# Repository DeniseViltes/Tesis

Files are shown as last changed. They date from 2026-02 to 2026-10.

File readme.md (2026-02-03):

# Plataforma experimental de ecualización activa de celdas de litio

Trabajo Profesional de Ingeniería Electrónica  
Facultad de Ingeniería – Universidad de Buenos Aires (FIUBA)  
Año 2026

**Integrantes**
- Sebastián Ezequiel García
- Denise Oriana Viltes

**Tutora:** Dra. Cecilia G. Galarza  
**Cotutor:** Ing. Juan Zuloaga

---

## Descripción

Este proyecto presenta el diseño, simulación e implementación de una plataforma
experimental para evaluar estrategias de ecualización activa en baterías de litio.

La plataforma permite:
- reconfigurar dinámicamente el conexionado de celdas mediante una matriz de switches
<!-- Esto es un comentario --> - estimar SoC (State of Charge)
<!-- Esto es un comentario -->- ensayar algoritmos de balanceo activo
- validar resultados mediante simulación y prototipo físico

El objetivo es contar con una plataforma para comparar
distintas arquitecturas de balanceo y analizar su eficiencia energética.

---

## Estructura del repositorio

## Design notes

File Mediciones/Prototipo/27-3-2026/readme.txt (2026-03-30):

Pruebas de sw

Cuando probamos 1 celda y el banco en sw, se llega ver un pico de corriente en la fuente de tension, no llegamos a ver a que corresponde en las tensiones medidas en el osciloscopio.

Cuando intercalamos una celda por otra en un mismo banco no hay pico, la salida se ve constante.

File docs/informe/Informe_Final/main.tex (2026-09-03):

\documentclass[12pt]{article}
\input{paquetes}

\makeatletter
\renewcommand\paragraph{\@startsection{paragraph}{4}{\z@}%
  {2ex plus .2ex}%  Espacio antes
  {0.5em}%             Espacio después
  {\normalfont\normalsize\bfseries}% Estilo
}
\makeatother

% Configuración del encabezado para la carátula y el índice

\newcommand{\quotes}[1]{``#1''}

\sisetup{
  per-mode=fraction,
}

\renewcommand\indexname{Índice}

\setmarginsrb{3 cm}{2.5 cm}{3 cm}{2.5 cm}{1 cm}{1.5 cm}{1 cm}{1.5 cm}

\captionsetup{
    width=0.6\textwidth, % Ancho del caption
    margin=20pt, % Margen del caption
}

\makeindex[columns=3, title=Alphabetical Index, intoc]

\begin{document}

%--------------------------- DATOS GENERALES -----------------------------%

\title{Trabajo Profesional de Ingeniería Electrónica}	% Titulo del trabajo.
\author{UBA - Facultad de Ingeniería}	% Nombre y apellido
\newcommand{\tpnumber}{I}       % Número de trabajo práctico
\date{\today}					% Fecha (automática, no tocar)

\makeatletter
\let\thetitle\@title
\let\theauthor\@author
\let\thedate\@date
\makeatother

\pagestyle{fancy}

\fancyhead[R]{Grupo 2}
\fancyhead[L]{TP1}
\rhead{\theauthor}
\lhead{\thetitle}
\cfoot{\thepage}

%-------------------------------------------------------------------------%
%-------------------------------------------------------------------------%
%------------------------------- CARÁTULA --------------------------------%
%-------------------------------------------------------------------------%
%-------------------------------------------------------------------------%

\begin{titlepage}
\fancyhf{} % limpia encabezado y pie

% --- Configuración del pie de página ---
\fancyfoot[L]{\small Trabajo Profesional de Ingeniería Electrónica}
\fancyfoot[R]{\small Año 2026}

% --- Quita la línea del encabezado y activa la del pie ---
\renewcommand{\headrulewidth}{0pt}
\renewcommand{\footrulewidth}{0.4pt}
\thispagestyle{fancy}

\vfill 

\begin{center}
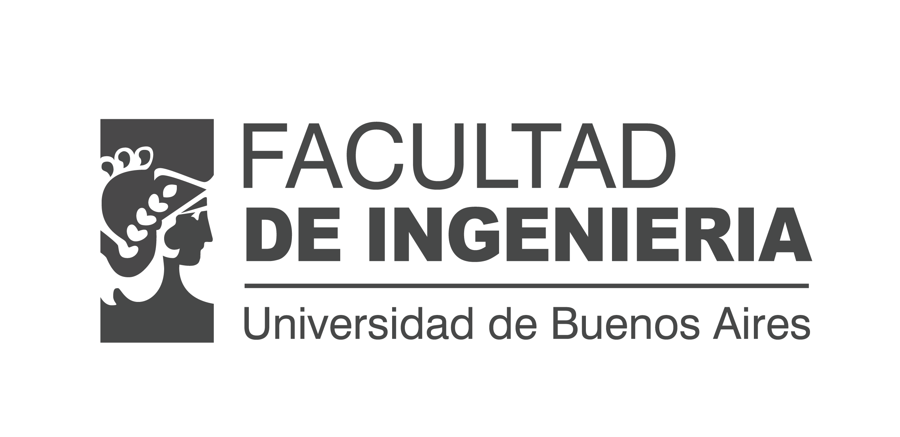
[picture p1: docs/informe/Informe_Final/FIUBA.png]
    \\[1cm]
    
    {\huge \textbf{Diseño de una plataforma experimental de ecualización activa de celdas de litio}}\\[1cm]

    {\large\textbf{Integrantes}}\\[0.2cm]
    {\Large Sebastián Ezequiel García}\\
    Padrón: 103780\\
    \textit{sebgarcia@fi.uba.ar}\\[0.3cm]
    
    {\Large Denise Oriana Viltes}\\
    Padrón: 106943\\
    \textit{dviltes@fi.uba.ar}\\[1cm]

    {\large\textbf{Tutora}}\\[0.2cm]
    {\Large Dra. Cecilia G. Galarza}\\
    \textit{cgalar@fi.uba.ar}\\[0.3cm]
    {\large\textbf{Cotutor}}\\[0.2cm]
   {\Large Ing. Juan Zuloaga}\\
    \textit{jzuloaga@fi.uba.ar}\\[1cm]
\end{center}
\vfill 
\end{titlepage}

\newpage
\tableofcontents
\clearpage

\onehalfspacing
\justifying

%-------------------------------------------------------------------------%

\input{Capitulos/Marco teorico}

\input{Capitulos/Diseño del circuito}
\input{Capitulos/Prototipo}
\input{Capitulos/Mediciones sobre el prototipo}
\input{Capitulos/Circuito final}
\input{Capitulos/Posibles mejoras}

\newpage
\bibliographystyle{IEEEtran}
\bibliography{biblio}

[AGREGARLE COMO REFERENCIAS LAS HOJAS DE DATOS]

\end{document}

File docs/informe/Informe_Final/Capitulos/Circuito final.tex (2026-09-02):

\section{Circuito final}

Con la confirmación de funcionamiento del prototipo, se prosiguió al diseño del sistema final. La principal premisa del trabajo es que sea modular, por lo que se optó por numerosos circuitos pequeños en lugar de uno solo grande como fue el prototipo. En un principio se pensó en mantener las celdas con los portapilas en una placa por separado del resto del circuito dado el tamaño que le agrega a cada módulo. Sin embargo, finalmente se descartó esa idea, resultando en tres circuitos diferentes:

\begin{enumerate}
    \item Circuito de celdas: cada una es un módulo que alberga el portapilas, con su \textit{switch}, LED e inversor.
    \item Circuito de bancos: con el \textit{switch by-pass} de las celdas y desde donde se envían las señales de control a todas las celdas del mismo banco.
    \item Circuito central: donde se inserta el controlador y desde donde parten las señales de control a todo el sistema, y a donde llegan las señales de censado de las celdas.
\end{enumerate}

\begin{figure}[H]
    \centering
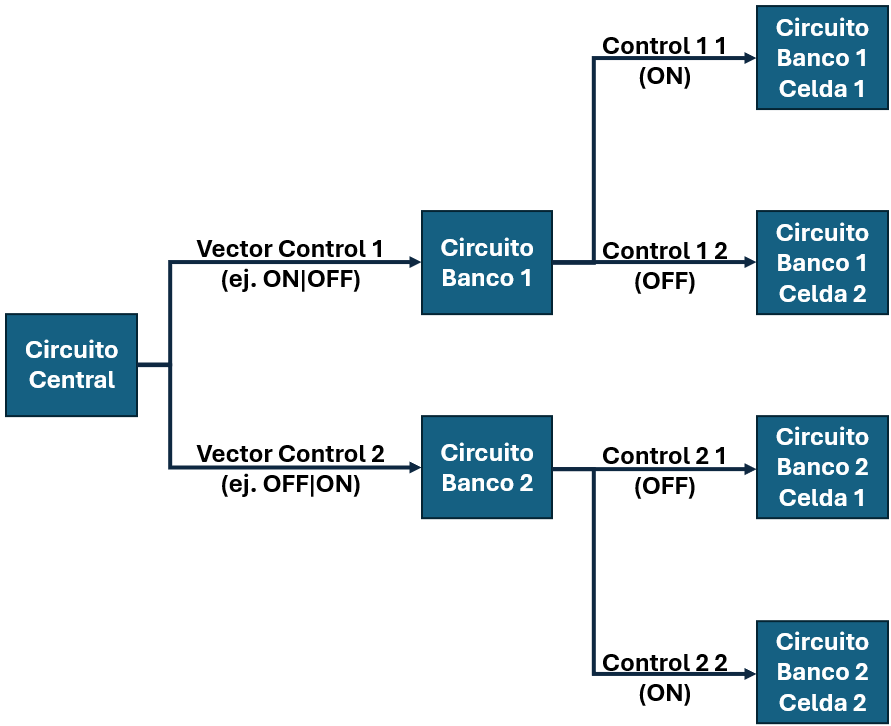
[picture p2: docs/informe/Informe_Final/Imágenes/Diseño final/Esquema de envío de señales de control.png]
    
    \caption{Diagrama de transporte de señales de control entre los módulos.}
    \label{fig:esquema_seniales_control}
\end{figure}

De esta forma, se armaron doce circuitos de celdas, cuatro circuitos de banco y un circuito central.

Al margen de los cambios de diseño del \textit{hardware}, también sufrió cambios el controlador. Debido a la mayor cantidad de celdas en comparación con el prototipo, son necesarios muchos más pines del controlador, más de los disponibles. Esto implica un cambio de lógica al momento de enviar las señales para maximizar el uso de cada pin de salida de la placa programable.

Al no alcanzan los pines del controlador para todas las señales que debe enviar si fuera una por cada celda, se optó por enviar la información en serie para todas las celdas de un banco. Para este rol fue que se utilizó un \textit{shift-register} con \textit{latch} (SR). Más información sobre este componente se provee en la sección del diseño de circuito de banco.

Por otro lado, otro objetivo que se planteó fue el de armar todos los circuitos, siempre que sea posible, con componentes SMD. De esta forma, buscamos:
\begin{itemize}
    \item Minimizar el área de placa de cobre usada,
    \item Facilitar el planchado y perforado de las placas,
    \item Identificar de forma clara qué corresponde a una entrada y/o salida, y qué al circuito propio de cada módulo,
    \item Aprender a soldar componentes SMD.
\end{itemize}

Otro punto a destacar fue que se decidió acerca de qué topología conformarían los módulos conectados. Ya haciendo pruebas y mediciones con el prototipo mismo, rápidamente se mostró la incomodidad al tener que usar cables \textit{dupont} para todo el conexionado. Cables demasiado largos, fácil de enredarse y que no enganchan con firmeza, complican mucho la instalación del banco de prueba. Para esto es que se decidió eliminar el uso de cables individuales y utilizar más que nada pines que encastren entre los módulo para conectarlos.

A la primera configuración planteada se la denominó "tren". Consistía en usar pines $90^\circ$ macho a un lado de la placa y hembra en el extremo opuesto. De esta forma, podrían conectarse de costado cada módulo. Sin embargo, esta configuración tenía tres grandes problemas. Por un lado, los pines hembra y macho $90^\circ$ no están a la misma altura, por lo que se tendría que soldar de forma muy cuidadosa para garantizar un encastre correcto. A su vez, el hecho que haya señales compartidas entre todas las celdas de un mismo banco implicaría que la señal entra por un costado de la placa y tendría que trasladarse a través de todo el circuito hasta la salida en el otro extremo para que el siguiente módulo reciba la señal correcta. Esto complicaría enormemente el ruteo de la placa. Por último, si se tuviera un banco con varias placas de celda, sería necesario mucho espacio en una mesa y sería complicado moverlas sin necesidad de desconectarlas. Por todo esto fue que se decidió optar por la segunda configuración.

La otra opción era la configuración "torre". Este caso era mucho más simple: los módulos de celdas se montarían uno encima de otro mediante pines y, abajo de todo como si fueran los cimientos, estaría el módulo del banco. Esto facilitaba en gran medida el ruteo (no hace falta trasladar la señal de entrada de un lado a otro de la placa), el transporte y el espacio necesario. La única condición estrictamente necesaria es que el pin macho que recibe las entradas desde el "piso de abajo" tenga un equivalente hembra apuntando hacia arriba para transmitirlas hacia el siguiente módulo. Para esto se usaron los pines hembra-macho o también llamados pines hembra largos de la figura \ref{fig:pin_hembra_largo}. Otro inconveniente menor es la poca rigidez estructural de la torre, pero se asumió que los pines tienen un agarre suficientemente fuerte como para mantener a las placas en pie. Con todos los problemas solucionados, esta configuración torre fue la elegida.

\begin{figure}[H]
    \centering
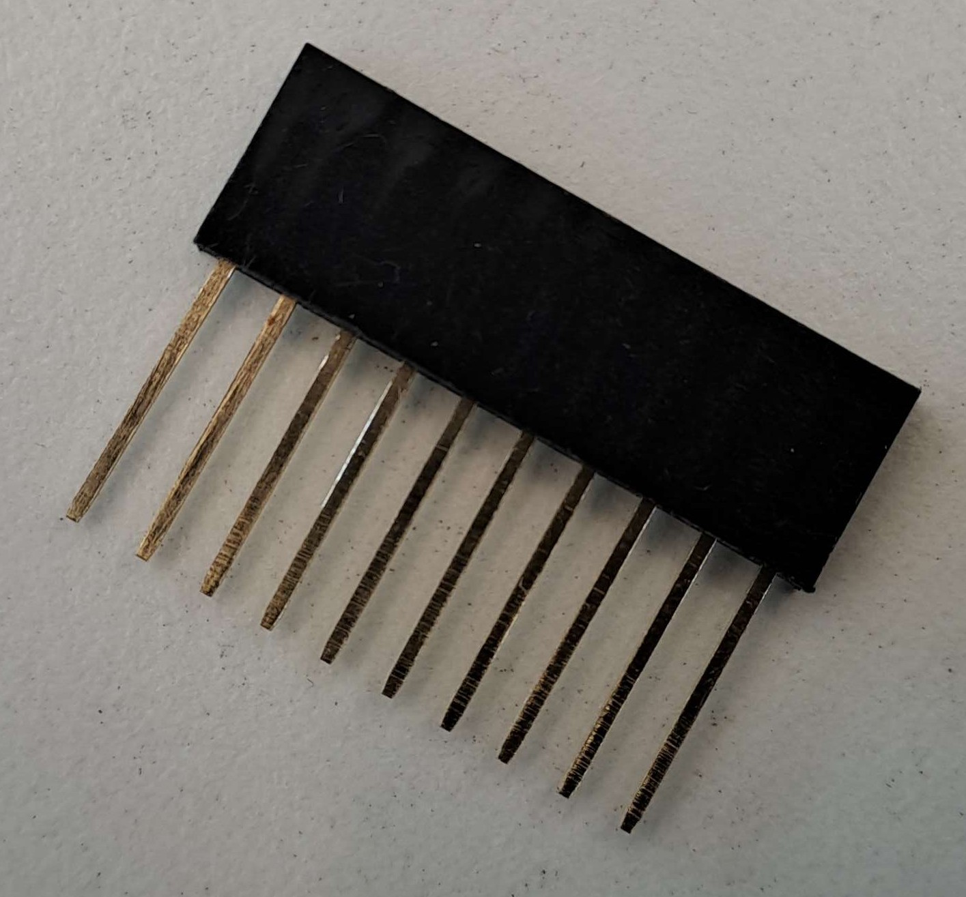
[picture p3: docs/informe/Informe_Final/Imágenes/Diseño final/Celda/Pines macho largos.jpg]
    
    \caption{Tira de diez pines hembra-macho utilizados.}
    \label{fig:pin_hembra_largo}
\end{figure}

\subsection{Diseño del circuito de las celdas}

%OPCIONES PARA LAS ENTRADAS A LAS CELDAS:
%- MULTIPLEXOR
%- SHIFT REGISTER CON LATCH
%- MICRO EN CADA CELDA

El principal problema a tratar fue el de los pocos pines del controlador. Antes de utilizar el \textit{shift-register}, se pensó en colocar un microcontrolador en cada módulo de celda. De esta forma, mediante comunicación I2C se podría enviar la señal de encendido o apagado a cada módulo utilizando solo dos vías. Esto permitiría conectar la cantidad de celdas que se deseen por banco. Sin embargo, se descartó esta idea debido al aumento de precio que implica y su complejidad de implementación. Finalmente se terminó optando por el envío de información en serie en una etapa anterior, y que cada módulo de celda simplemente reciba como entrada su señal de control.

\subsubsection{Versión 2.0}

El circuito, en grandes rasgos, se mantuvo como en el prototipo, al menos en cuanto a su funcionamiento. Sin embargo, sí hubieron diferencias constructivas en pos de la modularidad del sistema. El circuito propiamente dicho fue igual salvo por la incorporación de un inversor para la señal de control negada, como entrada en la base del transistor $Q_3$.

En el prototipo, para las señales negadas se utilizó el integrado \textbf{CD40106} que contenía seis inversores. En este caso, sería un desperdicio de recursos y espacio montar uno de esos por módulo, por lo que se identificaron dos opciones: tener tanto señal de control como señal negada como entradas, o incorporar un inversor más simple por módulo. Se optó por la segunda opción, y, ante la imposibilidad de conseguir inversores individuales, se implementó un inversor CMOS discreto. Para esto se utilizaron los MOSFETS \textbf{AO3400} (canal N) y \textbf{AO3401} (canal P), como se muestra en la figura \ref{fig:inversor_cmos}.

\begin{figure}[H]
    \centering
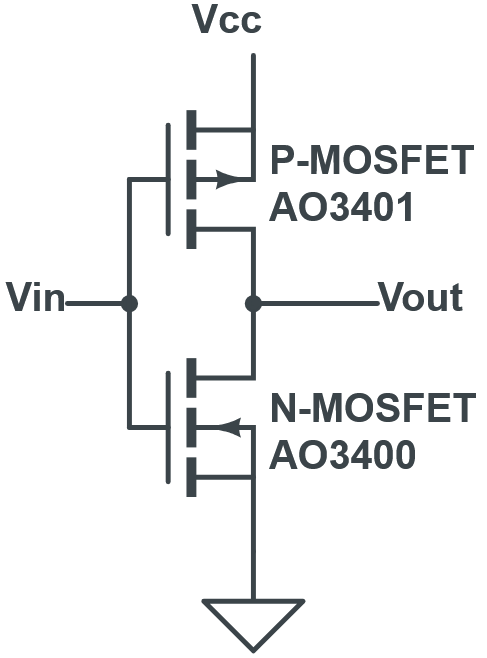
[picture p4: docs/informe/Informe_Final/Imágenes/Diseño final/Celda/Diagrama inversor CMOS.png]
    
    \caption{Diagrama del inversor CMOS discreto implementado.}
    \label{fig:inversor_cmos}
\end{figure}

Al igual que en el prototipo, se implementó un pequeño circuito con un LED. Mediante un TBJ NPN, se abre o cierra la malla del dispositivo según sea la señal de control del \textit{switch} de la celda. De esta forma, se puede ver claramente cuándo es que cada celda está encendida.

Cada módulo tiene una cantidad de entradas definidas para poder funcionar correctamente. En un principio están $Vcc$ y $GND$. Por un lado, necesarios para la etapa de control del módulo, la malla del LED y el inversor CMOS, y por otro para que las tierras de todos los circuitos estén acopladas. A su vez están los buses positivo y negativo de cada banco ($bus\_pos$ y $bus\_neg$). Éstos son tanto entrada como salida: si la celda está prendida, ésta impone su diferencia de tensión entre estos buses, pero a la vez, también deben coincidir con los buses de todas las celdas del banco dado que están en paralelo. Finalmente se tiene el control global. Éste es una señal de control separada de las individuales para cada celda. Con el objetivo de simplificar la comunicación, se decidió enviar, además de las señales de control individuales para cada módulo, una señal compartida para todas ellas. Dado que el control se hace por banco y no por celda, éste sería el control utilizado en el funcionamiento normal del sistema. Para poder seleccionar entre esta señal global y la individual, se usa un \textit{jumper}.

Con respecto a la entrada de control individual, se hicieron varias consideraciones. En un principio, como cada módulo envía al siguiente exactamente la misma información que recibe, cada módulo necesariamente tiene que recibir las señales de control de todas las celdas individuales del banco. Para esto se utilizó una tira de siete pines hembra-macho, uno por módulo de celda en el banco. La tarea de asignar qué señal se corresponde a qué módulo se dejó para hacerse a mano. Esto se hizo mediante una tira de pines macho dobles y un \textit{jumper}. El sistema montado se muestra en la figura \ref{fig:pines_control_celda}.

\begin{figure}[H]
    \centering
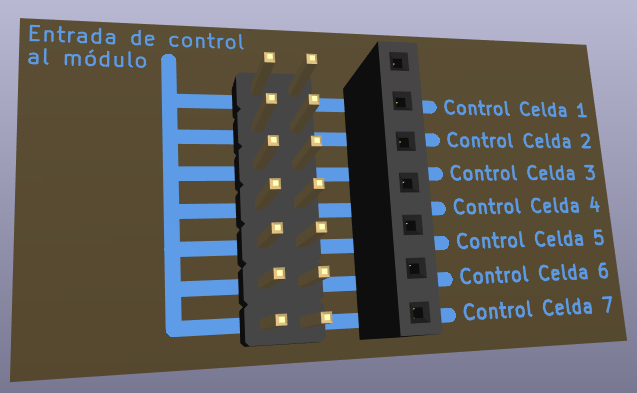
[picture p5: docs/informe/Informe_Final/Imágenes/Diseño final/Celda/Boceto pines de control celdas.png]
    
    \caption{Configuración realizada para la entrada de las señales de control en cada módulo de celda.}
    \label{fig:pines_control_celda}
\end{figure}

En celeste está diagramado el conexionado entre las dos tiras de pines. Importante destacar que el lado izquierdo de la tira de pines macho doble no está conectado con el lado derecho. Pero los pines del lado izquierdo sí están conectados todos entre sí, los cuales son la señal de entrada al módulo en cuestión. De esta forma, mediante un \textit{jumper} puede seleccionarse cuál de las siete entradas termina siendo la que realmente controla la celda.

Por otro lado, también se tienen las salidas de censado. Se decidió tomar el valor de tensión de cada módulo de celda el valor de $cell\_neg$, es decir, el nodo entre el terminal negativo del portapilas y el \textit{drain} del N-MOSFET. Se utilizó un sistema igual que para las entradas de control: cada módulo tiene las tensiones de todos los módulos del banco. Mediante un \textit{jumper} es que se le asigna a cada módulo su salida correspondiente de entre los siete posibles. Para colocarlo se usa otra tira de siete pines macho dobles.

Con todo esto ya quedan definidas las entradas y salidas de cada módulo de celda. Se tienen veinte pines dobles hembra-macho de entrada/salida:
\begin{itemize}
    \item Pin Vcc.
    \item Dos pines GND. Son dos para facilitar el ruteo (si no habría que usar más vías).
    \item $bus\_pos$.
    \item $bus\_neg$.
    \item Pin de control para todos los módulos del banco $Vcontrol\_global$.
    \item Siete pines de control individual (uno por módulo de celda en el banco).
    \item Siete pines de censado de $cell\_neg$ (uno por módulo).
\end{itemize}

Luego está el tema de la estabilidad mecánica de la torre. Ya se mencionó que el agarre de los pines hembra-macho es fuerte. Sin embargo, para mayor seguridad, se tomaron dos medidas. En un principio, en cada ocasión que se utilizaron dichos pines, se tomaron siempre tiras dobles. De esta forma, la cantidad de pines que se conectan entre un módulo y el siguiente se duplica. El único problema de esto es que no se venden en el país pines hembra-macho dobles, por lo que se utilizaron en cada instancia dos tiras simples (salvo en un caso por temas de espacio en la placa). Por otro lado, la otra medida para hacer más robusta la torre fue colocar los pines en diferentes lados de la placa. Con estas dos medidas, la torre debería mantenerse firme incluso si se conectara la máxima cantidad de celdas posibles por banco.

Existe otro inconveniente del que hasta ahora no se habló: la altura de cada módulo. Para ser más específico, la altura del portapilas. El problema reside en que los pines, a pesar de ser mucho más largos que unos hembra comunes, aún así no son más largos que el alto del portapilas. Esto significaría que una celda no podría conectarse con otra por encima. Para solucionar esto se decidió usar otra iteración de los mismos pines. Es decir, entre módulo y módulo hay otras tiras de pines como se ve en la figura \ref{fig:celda_stackeada}. De esta forma, hay un muy pequeño espacio entre cada módulo, por donde entran sin problema los componentes SMD del circuito.

\begin{figure}[H]
    \centering
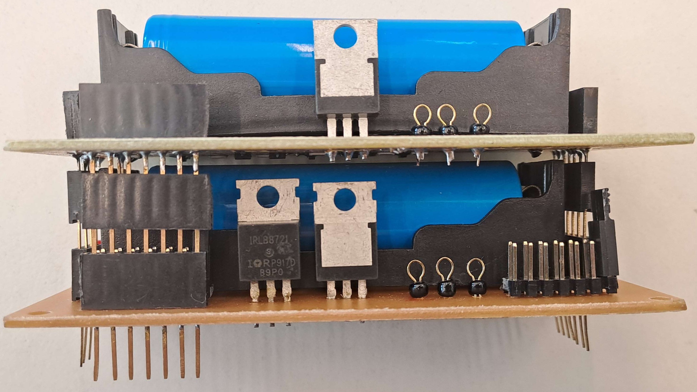
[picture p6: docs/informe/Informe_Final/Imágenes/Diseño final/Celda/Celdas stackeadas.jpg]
    
    \caption{Dos módulos de celdas (versión 2.1), una por encima de otra, con los pines de conexión.}
    \label{fig:celda_stackeada}
\end{figure}

Como datos de color, se menciona que el MOSFET de canal N que enciende y apaga cada celda se colocó con la cara metálica del encapsulado apuntando hacia afuera de la placa. Esto permite que tenga lugar disponible en caso que se desee incorporar un disipador. No es necesario para esta topología pero, en caso de querer aumentar la corriente a la salida, puede hacer falta. Por otro lado, también se utilizó, como en el prototipo, un fusible de \SI{3}{\ampere} en cada celda en la malla de salida. Además, se creó una pequeña zona libre de cobre en torno a los tornillos sujetadores del portapilas. Esto se hizo para que las tuercas que ajustan no estén en contacto con el plano de tierra del circuito.

En cuanto al ancho de las pistas, se tomó para las pistas de la malla de potencia \SI{1.5}{\milli\meter} y para las pistas de la etapa de control, \SI{0.4}{\milli\meter}. Ambas fueron elegidas de forma tal que puedan sin problemas tolerar la corriente máxima que puede atravesar cada pista. Los valores fueron seleccionados con la tabla dada por Peterson (2025) \cite{peterson2025pcb}.

Finalmente, para facilitar el \textit{debuggeo} se instalaron tres \textit{test-points}: uno en la base del TBJ PNP, otro en el nodo de \textit{gate} del \textit{switch} N-MOSFET y el último a la salida del inversor.

Con todo esto, el circuito resultó como se ve en las figuras \ref{fig:pcb_celda_v20} y \ref{fig:modelo3d_celda_v20}.

\begin{figure}[H]
    \centering
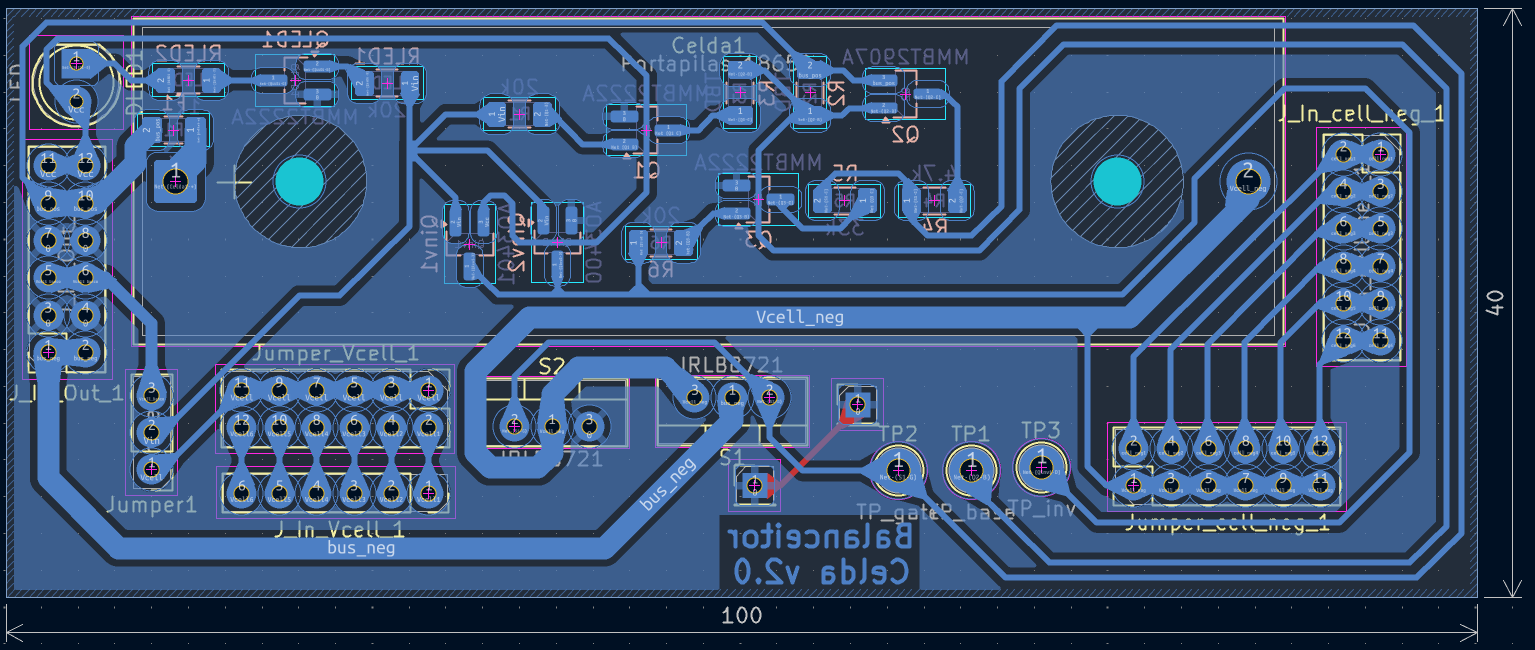
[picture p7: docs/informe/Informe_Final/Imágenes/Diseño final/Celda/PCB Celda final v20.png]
    
    \caption{PCB diseñado en \textit{KiCad} del módulo de una celda, versión 2.0.}
    \label{fig:pcb_celda_v20}
\end{figure}

\begin{figure}[H]
    \centering

    \begin{subfigure}{\linewidth}
        \centering
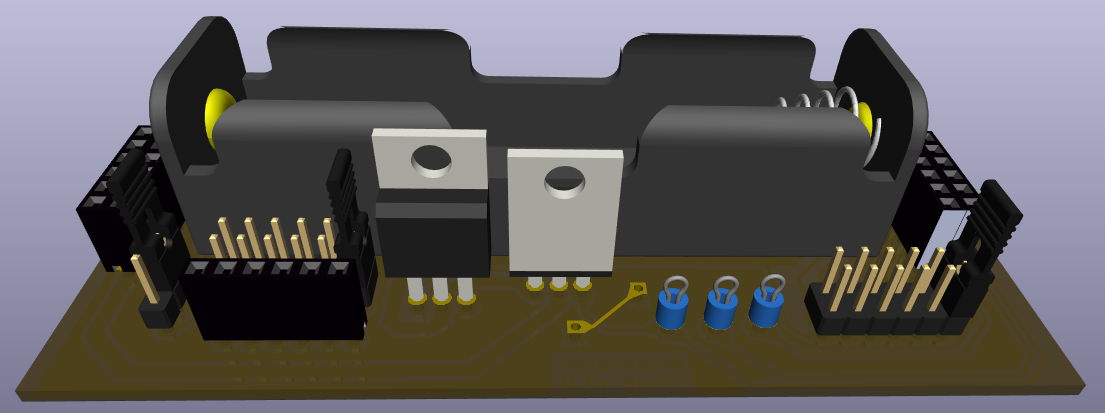
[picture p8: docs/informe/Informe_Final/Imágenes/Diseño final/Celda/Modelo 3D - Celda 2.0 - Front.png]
        
        \caption{Modelo 3D del frente.}
        \label{fig:modelo3d_celda_v20_f}
    \end{subfigure}

    \vspace{0.5cm}

    \begin{subfigure}{\linewidth}
        \centering
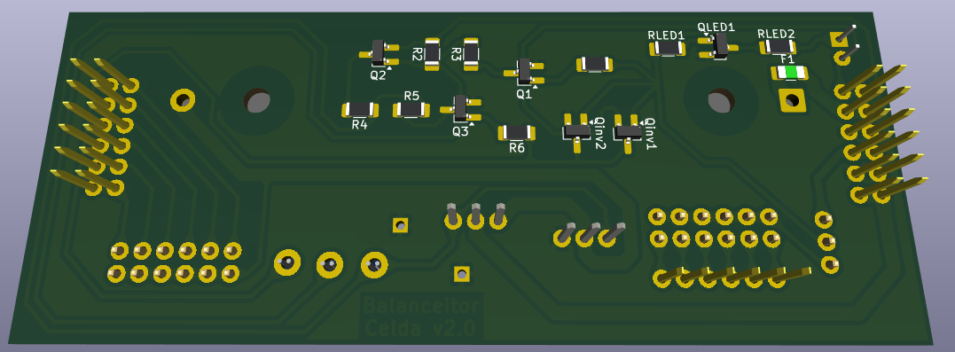
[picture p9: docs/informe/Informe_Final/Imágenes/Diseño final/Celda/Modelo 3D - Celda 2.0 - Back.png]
        
        \caption{Modelo 3D del reverso.}
        \label{fig:modelo3d_celda_v20_r}
    \end{subfigure}

    \caption{Modelos 3D del módulo de una celda, versión 2.0.}
    \label{fig:modelo3d_celda_v20}
\end{figure}

\subsubsection{Versión 2.1}

La versión 2.0 del módulo de celdas tuvo una vida muy corta. Por un lado, debido a un error de cálculos, se diseñó el módulo para que sea parte de un banco de hasta seis celdas. Sin embargo, el máximo real de módulos conectados que permite el SR es siete. A su vez, hubo un problema mucho más grave: la celda nunca se apagaba. Incluso cuando su señal de control era de apagado, el PNP se mantenía encendido. Esto provocaba un camino de baja impedancia entre el bus positivo y la tierra, mediante los transistores $Q_2$ y $Q_3$ de la figura \ref{fig:circuito_original}. Este problema ya había sido detectado en el prototipo pero se lo había descartado como una falla en la impresión de la placa. Finalmente se encontró la verdadera respuesta, y era efectivamente un problema de diseño. Los resistores $R_2$ y $R_3$, al ser tan grandes ($\SI{10}{\mega\ohm}$ y $\SI{1}{\mega\ohm}$ respectivamente), provocaban una significativa caída de tensión ante cualquier diminuta corriente parásita o de fuga que los atraviesen. Dicha caída era suficientemente alta como para encender el PNP, por ende, encendiendo el N-MOSFET de \textit{switcheo}. Reemplazándolos por resistores de $\SI{100}{\kilo\ohm}$ y $\SI{10}{\kilo\ohm}$ se solucionó el problema. Es curioso notar que este efecto no se veía en simulaciones, dado que era causado por corriente parásitas que el motor del \textit{LTspice} no simula.

Dado que el diseño estaba claramente incorrecto, se creó una nueva versión del módulo de celdas, corrigiendo algunos de los errores encontrados y aplicando otras tantas mejoras.

En un principio, se decidió eliminar el control global de todo el banco del diseño. Se lo consideró innecesario y que agregaba pines y \textit{jumpers} excesivos. Ahora, si se desea apagar o prender todas las celdas de un mismo banco, simplemente se le envía a todas señales iguales en lugar de decidir de qué forma tomar la entrada de control. Esto permitió eliminar el pin de $Vcontrol\_global$ y la tira de tres pines macho con el \textit{jumper} de selección de entrada de control. A su vez, al eliminar este pin de las entradas se simplificó el ruteo, lo cual también se eliminó la necesidad de que hayan dos pines de GND separados.

Por otro lado, hubieron mejoras en cuanto a la estabilidad mecánica de cada torre. En lugar de usar tiras de pines hembra-macho dobles, se instalaron orificios para una varilla roscada de \SI{3}{\milli\meter} en cada esquina de la placa. Así se reemplazaron las tiras dobles por simples, ahorrando en tiras de pines a comprar y espacio en la placa. De esta forma, se tiene ahora certeza absoluta de la robustez de la instalación por las varillas.

Por último, en lugar de una vía se utilizó un resistor SMD de \SI{0}{\ohm}. Éste cumple la misma función pero ocupando menos espacio y sin la necesidad de hacer orificios en la placa.

Con todos los cambios mencionados, también se pudo achicar ligeramente el tamaño de cada módulo (unos pocos milímetros por lado). De este modo, el PCB resultó como se muestra en las figuras \ref{fig:pcb_celda_v21} y \ref{fig:modelo3d_celda_v21}.

\begin{figure}[H]
    \centering
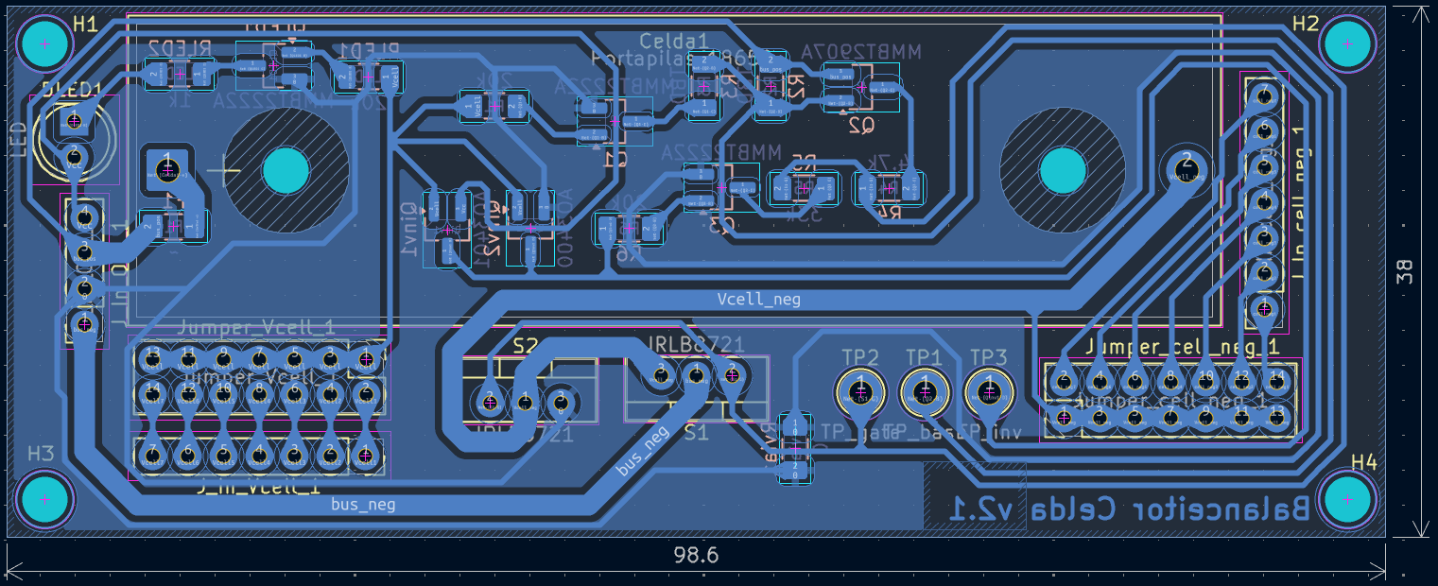
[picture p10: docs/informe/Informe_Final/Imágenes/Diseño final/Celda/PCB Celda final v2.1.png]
    
    \caption{PCB diseñado en \textit{KiCad} del módulo de una celda, versión 2.1.}
    \label{fig:pcb_celda_v21}
\end{figure}

\begin{figure}[H]
    \centering

    \begin{subfigure}{\linewidth}
        \centering
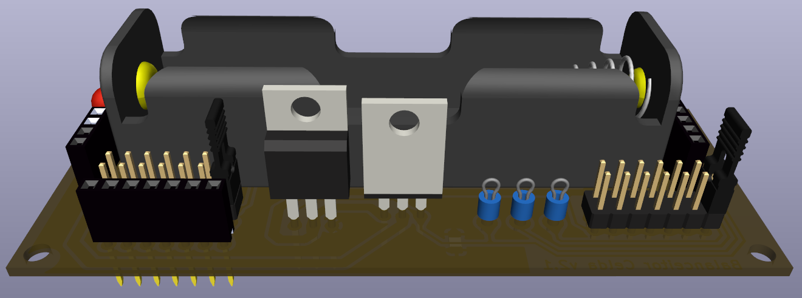
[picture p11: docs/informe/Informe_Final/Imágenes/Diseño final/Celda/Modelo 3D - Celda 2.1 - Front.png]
        
        \caption{Modelo 3D del frente.}
        \label{fig:modelo3d_celda_v21_f}
    \end{subfigure}

    \vspace{0.5cm}

    \begin{subfigure}{\linewidth}
        \centering
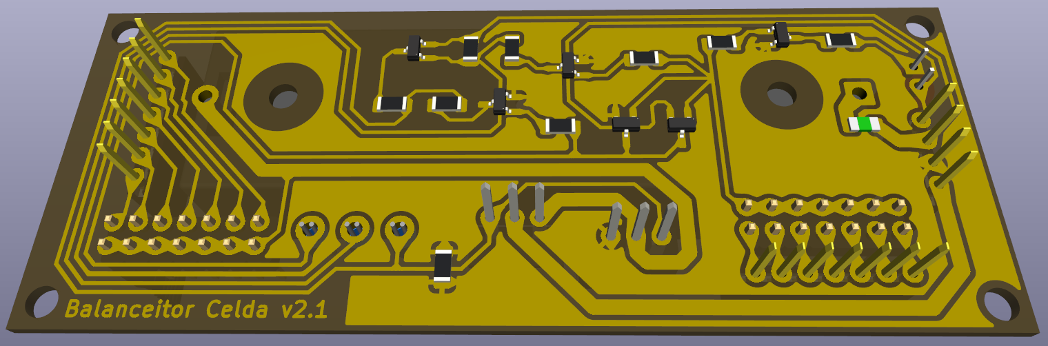
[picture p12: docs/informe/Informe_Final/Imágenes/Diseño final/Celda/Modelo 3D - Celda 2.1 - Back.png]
        
        \caption{Modelo 3D del reverso.}
        \label{fig:modelo3d_celda_v21_r}
    \end{subfigure}

    \caption{Modelos 3D del módulo de una celda, versión 2.1.}
    \label{fig:modelo3d_celda_v21}
\end{figure}

A diferencia de la versión anterior, esta sí funcionó como era esperado y se cumplieron exitosamente las pruebas básicas de funcionamiento del módulo. Sin embargo, unos resultados fueron algo alarmantes.

\subsubsection{Versión 2.2}

Mientras se realizaban las pruebas de funcionamiento en los módulos de celda v2.1, se descubrió que el valor de tensión de $cell\_neg_1$, el nodo del terminal negativo de las celdas del banco 1, era negativo. Este valor se volvía más negativo a medida que se agregaban más bancos en serie, llegando a unos \SI{-500}{\milli\volt} cuando se tenían cuatro bancos instalados. Esto es alarmante porque ese mismo nodo es el que se censa mediante del multiplexor analógico, el cual, para no dañarse, puede recibir tensiones menores a medio volt negativo. Dado que se está alcanzando dicho umbral, era necesario reducir (en módulo) dicha tensión. Cabe destacar que este fenómeno se da solamente en los nodos $cell\_neg$ de las celdas del banco 1.

\begin{wrapfigure}{l}{0.55\textwidth}
    \centering
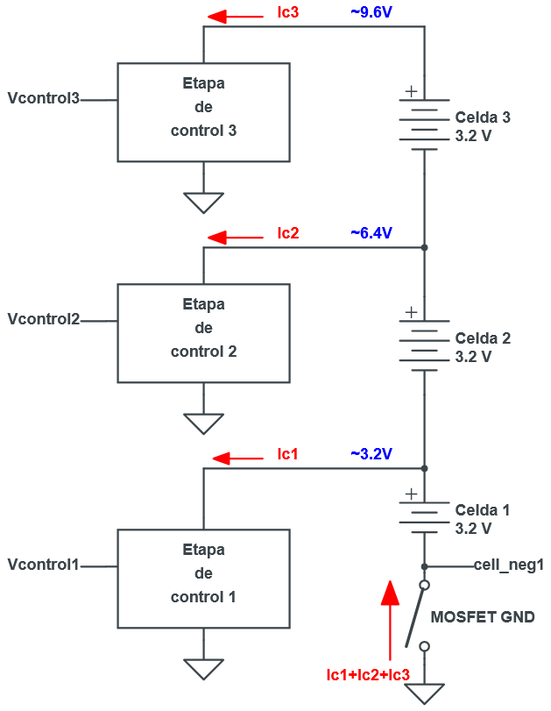
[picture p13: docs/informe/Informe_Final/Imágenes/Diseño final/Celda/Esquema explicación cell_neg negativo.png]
    
    \caption{Esquema simplificado de un sistema de tres bancos de una celda cada uno.}
    \label{fig:cell_neg_negativo}
\end{wrapfigure}

La causa del problema mencionado se puede analizar de forma más visual mediante el diagrama de la figura \ref{fig:cell_neg_negativo}. El inconveniente radica en que las mallas de control de cada módulo reciben corriente de la misma celda a la que están conectadas y cierran por tierra. 

Esto quiere decir que la única forma en la que la malla se cierra y la corriente regresa a las celdas es mediante la tierra. Cuando el N-MOSFET de GND está cerrado, o lo que es equivalente, cuando la celda del banco 1 está prendida, la corriente retorna sin problema alguno. Sin embargo, cuando dicha celda se encuentra apagada, el MOSFET está abierto. Mediante pruebas empíricas se descubrió que la corriente de todas formas circula a través del transistor, pero con un valor de impedancia significativo. Esto implica una caída de tensión, lo que conlleva a que el nodo $cell\_neg_1$ adquiera un valor de tensión negativo.

Otro dato a destacar es que las corrientes mostradas en el diagrama no son iguales. Su magnitud respeta el ordenamiento $Ic_3 > Ic_2 > Ic_1$ debido a que la caída de tensión en cada etapa de control aumenta a medida que aumenta el número de banco.

Este efecto se tornó mucho más notorio al disminuir las resistencias de $R_2$ y $R_3$. Éstas están relacionadas con la corriente consumida en la etapa de control durante el encendido. La solución no era trivial: se podrían aumentar nuevamente dichas impedancias pero eso significaría regresar el problema que tuvo el módulo v2.0, donde era imposible apagar la celda.

Finalmente se descubrió otra alternativa. Mediante la colocación de un tercer resistor entre $R_2$, $R_3$ y la base del PNP como se muestra en la figura [FIGURA].

% Ton PNP sin Rbase: 210us - Ton PNP con Rbase=100k: 240us

\begin{table}[H]
\centering
\begin{tabular}{@{}cccc@{}}
\toprule
$R_2\ [\Omega]$ & $R_3\ [\Omega]$ & $R_{\text{base}}\ [\Omega]$ & $cell\_neg_1\ [\text{V}]$ \\ \midrule
\SI{100}{k}     & \SI{10}{k}      & 0                           & \SI{-0.510}{} \\
\SI{560}{k}     & \SI{56}{k}      & \SI{100}{k}                 & \SI{-0.428}{} \\
\SI{560}{k}     & \SI{56}{k}      & \SI{560}{k}                 & \SI{-0.280}{} \\ \bottomrule
\end{tabular}
\caption{Comparación de valores de resistencias con su respectivo valor de tensión del nodo $cell\_neg_1$.}
\label{tab:cell_neg}
\end{table}

[SEGUIR]

De esta forma, se diseñó la tercera y última variante del módulo de celda, la versión 2.2 como se aprecia en las figuras \ref{fig:pcb_celda_v22} y \ref{fig:modelo3d_celda_v22}. Como este efecto ya se descubrió que \textit{LTspice} no lo simula, los valores exactos de los resistores no se encontraron hasta que se implementó físicamente el circuito. A su vez, como una alternativa, se instaló un \textit{jumper} soldado para poder cortocircuitar el nuevo resistor $R_{base}$ en caso que se desee regresar a la topología de los módulos v2.1.

\begin{figure}[H]
    \centering
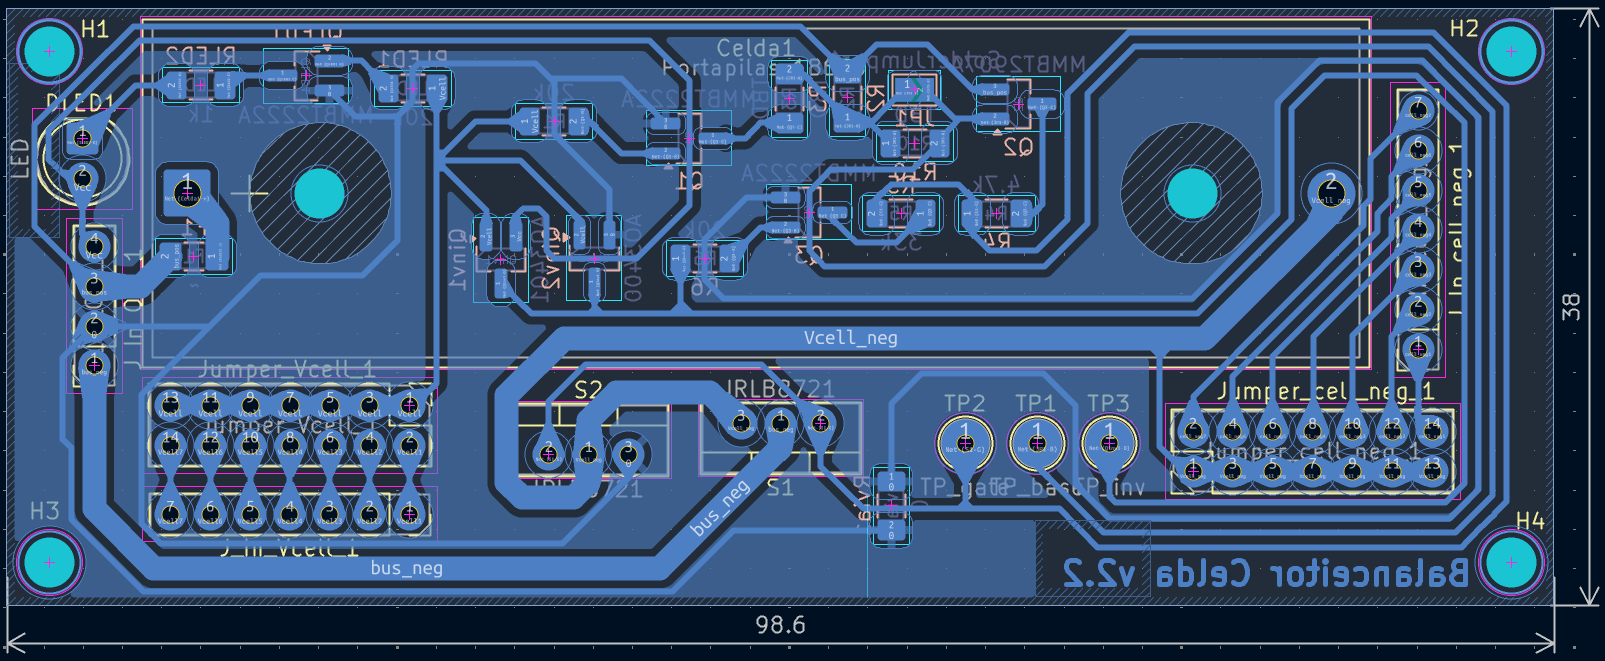
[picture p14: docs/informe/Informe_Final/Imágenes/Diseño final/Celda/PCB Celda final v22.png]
    
    \caption{PCB de la versión 2.2 del módulo de celda.}
    \label{fig:pcb_celda_v22}
\end{figure}

\begin{figure}[H]
    \centering

    \begin{subfigure}{\linewidth}
        \centering
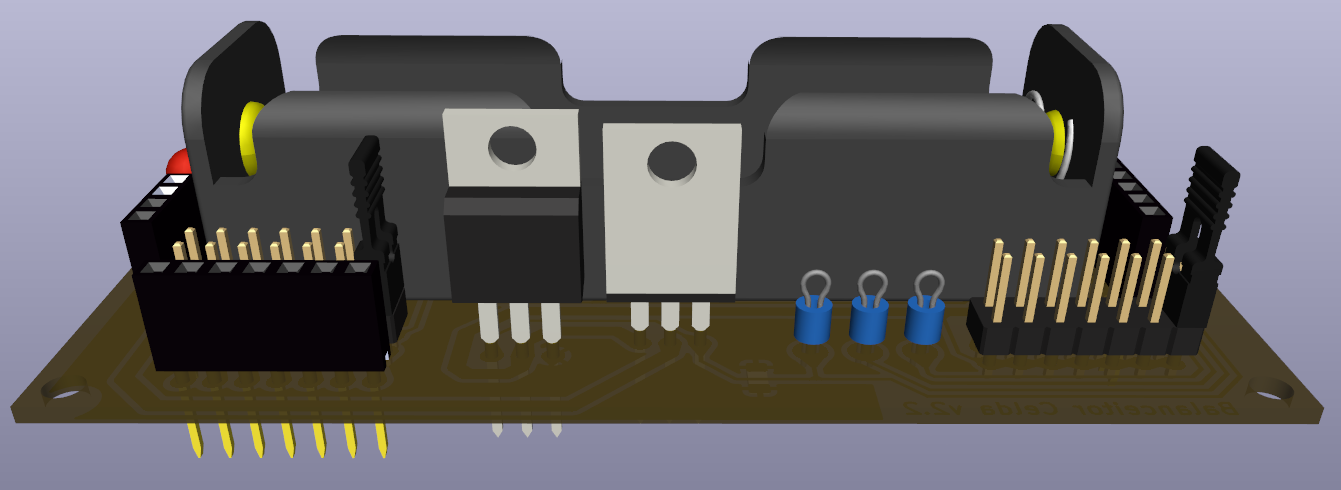
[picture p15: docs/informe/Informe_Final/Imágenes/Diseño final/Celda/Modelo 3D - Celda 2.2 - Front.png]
        
        \caption{Modelo 3D del frente.}
        \label{fig:modelo3d_celda_v22_f}
    \end{subfigure}

    \vspace{0.5cm}

    \begin{subfigure}{\linewidth}
        \centering
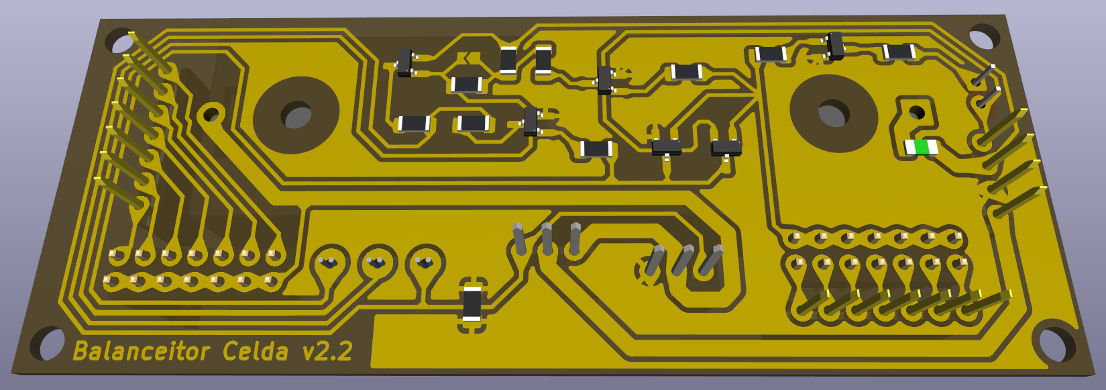
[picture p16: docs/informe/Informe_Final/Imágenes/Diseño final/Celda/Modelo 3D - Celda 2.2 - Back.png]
        
        \caption{Modelo 3D del reverso.}
        \label{fig:modelo3d_celda_v22_r}
    \end{subfigure}

    \caption{Modelos 3D del módulo de una celda, versión 2.2.}
    \label{fig:modelo3d_celda_v22}
\end{figure}

\subsection{Diseño del circuito de los bancos}

Se comienza con la problemática inicial, el switch de bypass, como se menciona anteriormente el P-MOSFET utilizado en el prototipo, no cumplia con el comportamiento esperado, se vuelve al panorama inicial en la búsqueda de componentes, resultando en dos opciones:

\begin{table}[H]
\centering
\begin{tabular}{@{}cccc@{}}
\toprule
P-MOSFET  & $V_{GS(TH)}\ [\si{\volt}]$ & $R_{DS(on)}\ [\si{\ohm}]$ & $R_{\theta JA}\ [\si{\celsius \per \watt}] $ \\ \midrule
IRLML6402 & -1.2         & 0.065        & 100             \\
AO3401    & -1.3         & 0.085        & 125             \\ \bottomrule
\end{tabular}
\caption{Comparación de criterios para la selección del MOSFET de canal P.}
\label{tab:nuevo_pmos}
\end{table}

 Ambos muy similares pero siendo el \textbf{IRLML6401} con ventaja. Al cambiar a un dispositivo de baja potencia es necesario analizar a la potencia que se verá exigido dicho componente. En este caso se supone una temperatura de funcionamiento  de $\SI{60}{\celsius}$ y del datasheet del componentes se obtiene que $T_{j} = \SI{150}{\celsius}$, se calcula la potencia máxima permitida para el componente con \eqref{eq:potencia_disipada}, obteniendo $P_{permitida} = \SI{900}{\milli \watt}$

\begin{gather}
    P_{permitida} = \frac{T_{jmax} - T_{funcionamiento}}{R_{\theta JA}}
    \label{eq:potencia_disipada}
\end{gather}

A continuación se realiza analiza la potencia en el P-MOSFET del banco 1, aumentando la cantidad de bancos totales, dicho switch siempre encendido y los bancos superiores siempre apagados de forma tal de exponer el switch al caso de mayor exigencia de corriente. Debe destacarse que la carga del sistema se modifica para mantener la corriente constante en la salida en \SI{3}{\ampere} para todas las matrices.

\begin{table}[H]
\centering
\begin{tabular}{@{}ccccc@{}}
\toprule
Cantidad de bancos & $V_{gs} [\si{\volt}]$ & $V_{ds} [\si{\volt}]$ & $I_d  [\si{\ampere}]$ & $Potencia [\si{\milli \watt}[$ \\ \midrule
2                  & -1.86               & -134.6              & -1.5               & 202.8                        \\
3                  & -1.79               & -221.4              & -2.03              & 450.7                        \\
4                  & -1.78               & -250.2              & -2.3               & 577.3                        \\
5                  & -1.767              & -268.0              & -2.47              & 662.47                       \\
6                  & -1.75               & -280.3              & -2.58              & 723.7                        \\ \bottomrule
\end{tabular}
\caption{Potencia en el P-MOSFET en el banco 1 para distinta cantidad de bancos en la matriz.}
\label{tab:potencia}
\end{table}

Como se ve en la tabla (\ref{tab:potencia}) este dispositivo disipa energía dentro de los limites establecidos en el datasheet, por lo tanto, para la cantidad de bancos fabricados se cumple con no necesitar disipador. 
De todas formas a modo preventivo en caso de resultar en una potencia mayor en el circuito físico se conecta un segundo P-MOSFET quedando ambos en paralelo. Esto logra dividir la corriente entre ambos MOSFETS, disminuyendo la potencia que disipa cada uno significativamente, en este caso no es de interés que sea una división simétrica de corriente, el único objetivo es no trabajar cerca de la potencia limite. Cabe aclarar que se analiza el caso del bypass del banco 1 ya que es que disipa la mayor cantidad de potencia, en los bancos superiores, la potencia disipada en los bancos superiores resulta menor a los \SI{300}{\milli \watt}.

Ya que el $V_{GS}$ logrado se encuentra cerca del umbral de encendido, el MOSFET opera en una región para la cual el fabricante no especifica el valor de $R_{DSon}$ de funcionamiento. A partir de los valores de la tabla \ref{tab:potencia}, se puede estimar que $R_{DS} = \frac{V_{DS}}{I_D} \simeq \SI{100}{\milli \ohm}$. Por lo tanto al utilizar el esquema de doble P-MOSFET (fig. \ref{fig:doble_pmos}), la resistencia equivalente resulta $R_{DSeq} = \frac{R_{DSon}}{2}$. Por lo tanto no solo  se observa una mejora en cuanto a potencia, al dividirse la corriente en ambos P-MOSFETS, si no que al reducir $R_{DSeq}$, reduce $V_{DS}$ y por consecuencia incrementa ligeramente el $V_{GS}$. Esto significa una menor caida de tensión entre $bus_pos$ y $bus_neg$, resultando en un mejor bypass.  Por otro lado, como buena práctica \cite{ti_mosfet_parallel}, se agrega una pequeña resistencia en el gate de cada MOSFET, asimismo, se busca una conexión simétrica en las pistas que unen a los MOSFETS en el PCB.

\begin{figure}[H]
    \centering
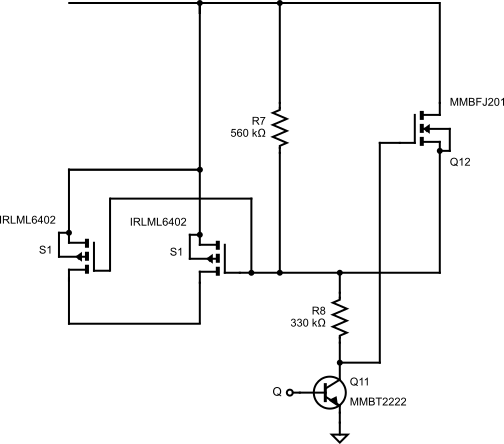
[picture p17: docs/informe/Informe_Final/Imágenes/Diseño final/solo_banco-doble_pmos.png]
    
    \caption{Conexión del P-MOSFET en paralelo}
    \label{fig:doble_pmos}
\end{figure}

Asimismo se ve en la figura \ref{fig:doble_pmos},  se agrega una resistencia en el gate de cada MOSFET como buena práctica indicada en \cite{ti_mosfet_parallel} y luego en el diseño de PCB se busca asegurar una conexión simetrica en las pistas que unen a los MOSFETS.

Para este modulo, se evalúa la necesidad de utilizar el jfet, se realizan pruebas con solo los elementos del banco en una placa (fig. \ref{fig:placa_de_prueba_banco}).
El principal motivo para agregarlo es para mejorar el apagado del PMOS, un apagado más veloz ayuda a evitar solapamientos entre el PMOS del módulo banco y el NMOS del módulo celda.

\begin{figure}[H]
    \centering
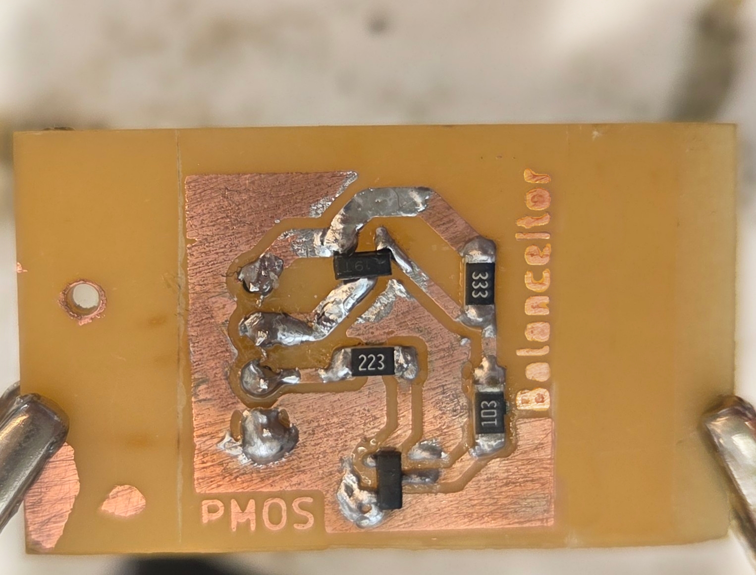
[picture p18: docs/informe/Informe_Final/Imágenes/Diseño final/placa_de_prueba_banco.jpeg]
    
    \caption{Placa de pruebas de P-MOSFET y JFET.}
    \label{fig:placa_de_prueba_banco}
\end{figure}

Se obtienen as siguientes mediciones:

\begin{figure}[H]
    \centering
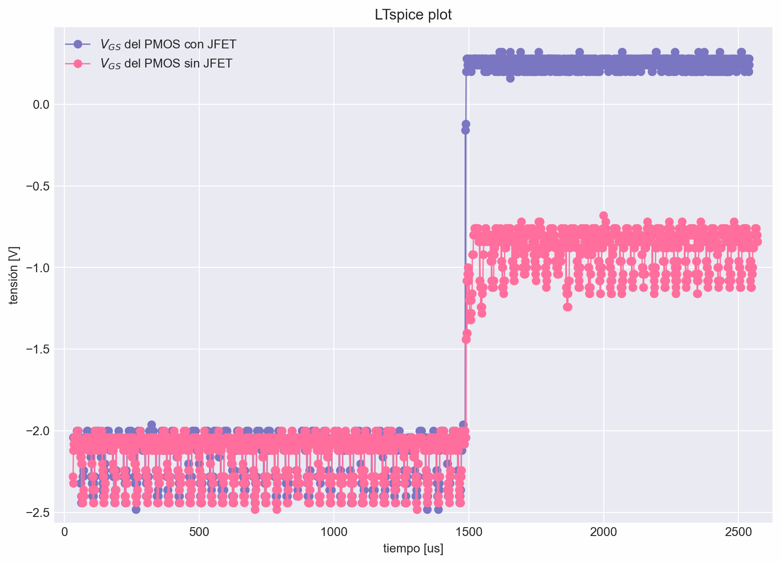
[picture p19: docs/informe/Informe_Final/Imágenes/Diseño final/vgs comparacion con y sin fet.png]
    
    \caption{Medición en banco de prueba del $V_{GS}$ del PMOS.}
    \label{fig:vgs comparacion con y sin fet}
\end{figure}

Como se puede observar, es claro el beneficio del JFET. Agregarlo permite que el PMOS pueda efectivamente apagarse, l caso sin JFET se queda en el limite entre el encendido y apagado. En cuanto a la velocidad, son unos pocos \si{\micro \second} de diferencia, pero son los suficientes para provocar un solapamiento con el NMOS del modulo celda. Por lo tanto el módulo banco, continua con JFET.

El modulo banco es el encargado de distribuir las señales de control a las celdas en su dominio. Como se menciona anteriormente, el encargado de realizar esta tarea es el SR, no se exigen criterios exigentes para seleccionar un componente, el componente que más se ajusta al proyecto es el \textbf{74HC595}. Como característica a destacar es que tiene registro de almacenamiento (latch). Este se trata de un componente de 8-bits, el cual permite manejar 8 salidas a partir de 3 señales de entrada. Al enviar la información de las 8 salidas en serie por un solo pin se logra reducir la cantidad de pines de forma significativa. 

Su funcionamiento se basa en dos registros, \textit{registro de desplazamiento}, el cual recibe la información en serie y el registro de almacenamiento, este guarda toda la información y la envía de forma paralela a sus 8 salidas de forma simultanea.
Las señales de control se envían por el pin SERIAL DATA INPUT (DATA), un bit a la vez, de forma simultanea, se  envía un pulso por el pin SHIFT CLOCK. Este último pin al recibir un pulso se encarga de desplazar todos los pines una posición ingresando el bit al registro de desplazamiento. En este estado en las salidas del SR no es posible ver los bits enviados, es necesario enviar un pulso en LATCH CLOCK (LATCH) para enviar todos los bits almacenados.

En cuanto los pines OUTPUT ENABLE (OE) y RESET se conectan directamente a GND y VCC. El primero se encarga de habilitar las salidas en paralelo, esta pin es active-low (entrada negada), por lo tanto se enciende un cero lógico, al colocarlo a GND, las salidas quedan siempre habilitadas. La situación es similar con el pin RESET, es una entrada active-low, por lo tanto un cero lógico resetea el registro de desplazamiento sin modificar las salidas actuales. El pin SERIAL DATA OUTPUT sirve para conectar otros SR en serie, y como las salidas son de alta impedancia, es seguro dejarlo desconectado.

Por lo tanto, para cada banco se necesitan 3 pines para manejar el SR, DATA, CLOCK y LATCH. Para no utilizar pines o señales de control adicionales, se aprovecha  el SR para enviar la señal de control del banco, resultando en 7 salidas paralelas restantes. Este valor es el que se toma como limite de celdas por banco. Como se ve en la figura \ref{fig:sr_conexion}  la primer salida se designa al control del banco y el resto de forma ordenada ascendente a las celdas. A cada salida se le colocan un resistor en serie como protección ante los picos de corriente que se pueden generar debido al inversor en el módulo celda. Para estos resistores se busca que sean valores menores a \SI{500}{\ohm}, su único objetivo es evitar el pico de corriente, no debería haber una gran caída de tensión debido a este.

\begin{figure}[H]
    \centering
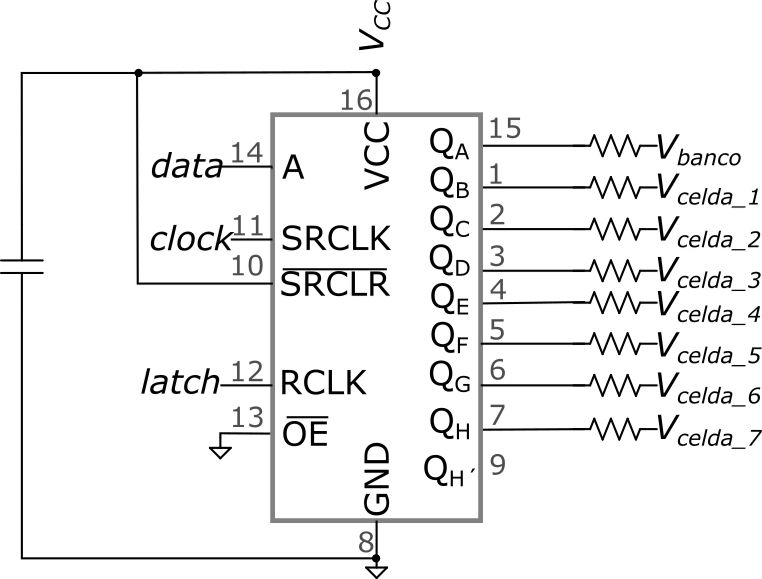
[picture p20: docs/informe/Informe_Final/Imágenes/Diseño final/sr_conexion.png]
    
    \caption{Diagrama de conexión del SR.}
    \label{fig:sr_conexion}
\end{figure}

En el caso de las mediciones, esta instancia solo se encarga de recolectar las mediciones del terminal negativo de la celda. Este valor no será utilizado en el controlador, pero si debe estar para cumplir con las funcionalidades de la plataforma experimental. Para el presente informe esta medición se encuentra solo como una posibilidad más de medición. Como instrumento de medición se utiliza el \textit{Multiplexor analógico}, \textbf{74HC4051} (MUX). Este componente permite conectar una salida común a uno de los 8 canales analógicos a partir de tres entradas selectoras (S0, S1 y S2). Para este caso, se utiliza como multiplexor, por lo tanto los 8 canales actuan como entradas, y el pin común como salida. La entrada de tensión negativa y el pin que habilita el dispositivo (active-low), se conectan a tierra, permitiendo un rango de tensión para los canales entre $GND$ y $V_{cc}$,y, como en el caso del SR queda constantemente habilitado. 

La entrada del \textit{gpi}o del controlador admite como máximo \SI{3.3}{\volt}, por lo tanto se aprovecha en esta etapa a colocar un divisor resistivo en las canales del MUX. La tensión máxima permitida por el dispositivo es $V_{cc}$ por lo tanto es divisor esta para establecer que la tensión máxima sea  \SI{3.3}{\volt} obteniendo así una tensión que también cumpla con el \textit{gpio} del controlador, La conexión de pines se observa en la figura \ref{fig:diagrama_mux}.

\begin{figure}[H]
    \centering
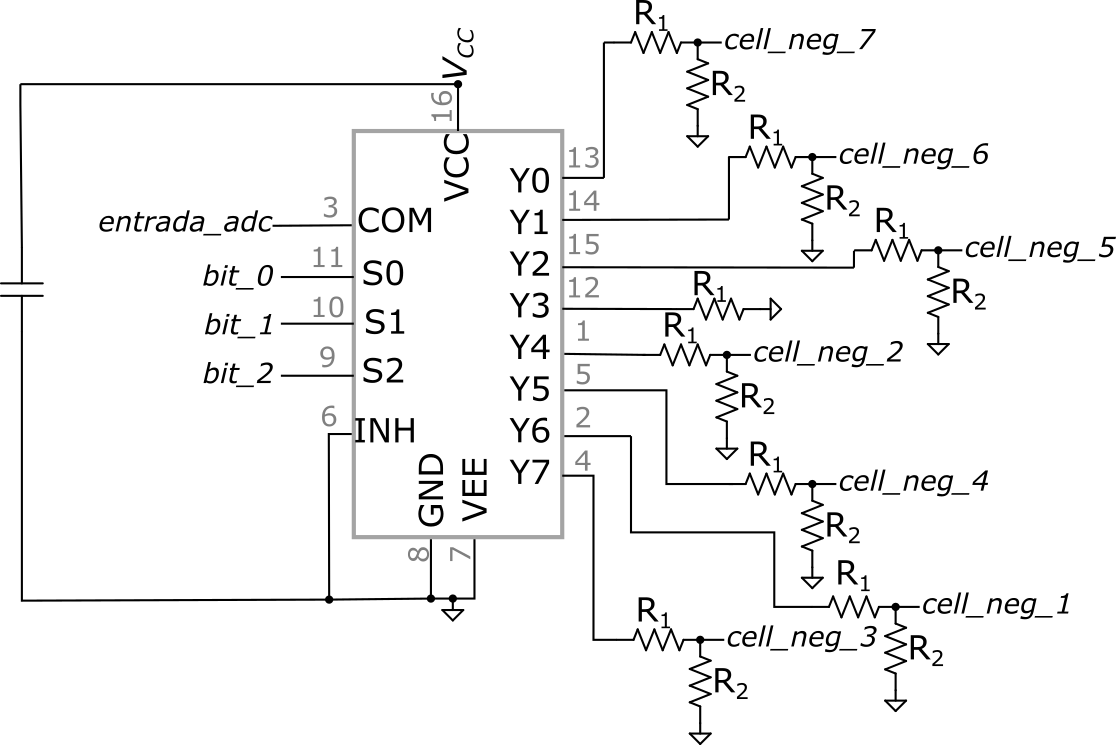
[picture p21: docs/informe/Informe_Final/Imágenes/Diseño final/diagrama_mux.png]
    
    \caption{Diagrama de conexión del MUX.}
    \label{fig:diagrama_mux}
\end{figure}

Para ambos integrados usados en este módulo se coloca un capacitor de desacople entre $V_{cc}$ y $GND$ para mantener la estabilidad en la alimentación y filtrar ruidos de alta frecuencia. 

Luego para completar el PCB, se coloca el LED correspondiente al banco y los pines  coincidiendo con los pines de la celda. Para la conexión con las celdas se utilizan pines hembra simples. En el caso de las entradas, se busca mejor robustez mecánica por lo tanto se decide utilizar cable plano. Se utilizan pines hembra para cable plano de 14 pines, repitiéndose tan solo $GND$ en dos pines.

El resultado final del PCB se encuentra en la figura\ref{fig:pcb_modulo_banco} El tamaño final resulta por poco un poco más ancho que el modulo celda. Esto incluso resulta favorable para la estructura de torre, ya que proporciona más estabilidad al modulo de celdas cuando la celda ya se encuentra colocada.

\begin{figure}[H]
    \centering
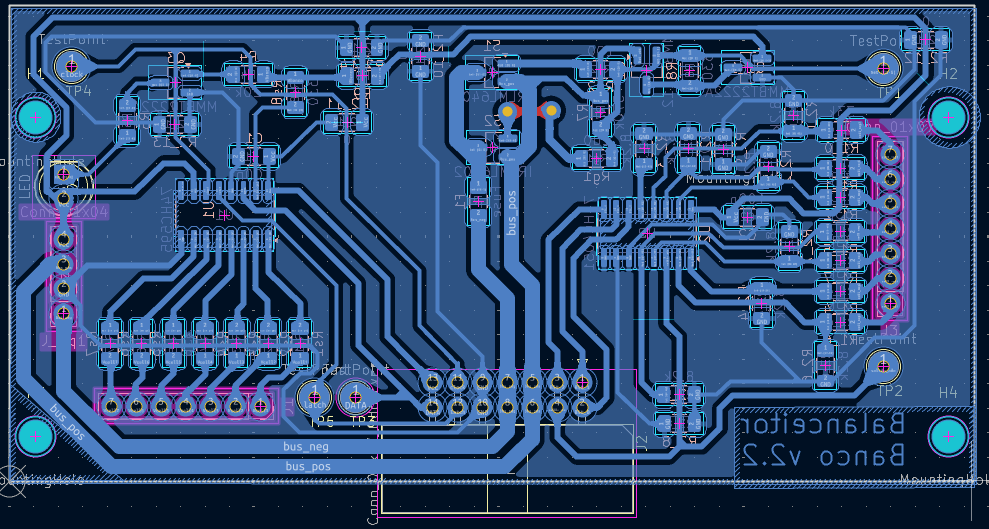
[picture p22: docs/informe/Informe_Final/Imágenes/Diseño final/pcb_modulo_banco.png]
    
    \caption{Diseño del PCB del módulo banco,}
    \label{fig:pcb_modulo_banco}
\end{figure}

Para llegar al diseño final del pcb, es decir la \textbf{versión 2.2} (fig. \ref{fig:pcb_modulo_banco}) se realizaron los siguientes cambios:

\begin{enumerate}
    \item Cambio de huellas: El primer error durante la elaboración fue utilizar huellas \textit{DIP-16}, que luego se modificaron por huellas \textit{SOIC-16}. Dando origen a la\textbf{ versión 2.1}. Para esta versión se agregan test points en la salida del mux, y en los pines de control del SR.

    \item El siguiente cambio fue eliminar resistencias de pull down en el shift register, En una versión inicial, se utilizaba el pin $OE$ del SR para la llave maestra por lo cual resultaba necesario que los pines de salida no queden en alta impedancia en caso de deshabilitar las salidas. Dicha idea se decartó y los resistores se eliminaron para una mejor eficiencia del SR en la \textbf{versión 2.2}.
\end{enumerate}

\begin{comment}
    poner imagen del resultado final del banco
\end{comment}

\subsection{Diseño del circuito central}

Como se mencionó previamente, como placa controladora se utilizó una \textbf{STM32 NUCLEO-F103RB}. Haciendo mediciones de testeo, rápidamente se hizo notoria la necesidad de simplificar el conexionado entre controlador y módulos de banco al igual que entre los mismos bancos entre sí. Al haber tantas señales que debían enviarse, muchas digitales y otras analógicas que debían conectarse en pines específicos, se tornaba una tarea muy tediosa cada vez se armaba y desarmaba el sistema. Para esto es que se diseñó el llamado \enquote*{circuito central}. Su tarea era ser simplemente una placa con pines hembra donde se montara la STM32, y tenga salidas mediante conectores de cable plano para enviar a cada módulo de banco. De esta forma, se reemplazaría todo el cableado por ruteo de la placa y las conexiones serían mediante tiras de catorce cables planos.

Originalmente se decidió que la placa no tenga ningún tipo de lógica circuital. Es decir, su rol es únicamente de soporte mecánico y de envío de información mediante buses.

Sin embargo, a medida que se hacían mediciones de pruebas sobre las demás placas, fueron surgiendo la necesidad (e ideas nuevas) con funciones para implementar. Para cuando se diseñó efectivamente la placa, lejos estaba de esa propuesta original muy simple de ser únicamente para simplificar el conexionado. Estas nuevas funciones agregadas fueron:
\begin{enumerate}
    \item Una llave de apagado manual y otra automática.
    \item \textit{Switches} entre cada banco y la salida, y entre bancos.
    \item Un medidor de corriente a la salida.
    \item La creación de una tensión $-Vcc$ de \SI{-5}{\volt}.
    \item Amplificadores operacionales para proteger los pines del controlador que censan tensión.
\end{enumerate}

Con respecto a los \textit{switches}, como se mencionó, hubieron uno manual y otro controlado. Ambos funcionan cortando la llegada de $Vcc$ a los módulos, y de esta forma, evitando cualquier tipo de control sobre las celdas. El manual se implementó con un pulsador y funciona simplemente como un botón de prendido y apagado de todo el sistema. A su vez, el automático se implementó, con la topología mostrada en la figura [FIG], con el objetivo de apagar todo el sistema ante la detección de una falla crítica (como puede serlo, un pico demasiado alto de corriente).

[AGREGAR DIAGRAMA DEL SWITCH PMOS]

[COMPLETAR]

\subsection{Problemas de diseño} 

Uno de los principales problemas durante el diseño del circuito inicial fue la tierra, colocando una tierra virtual en el terminal negativo se logra que funcione el sistema, pero se encontraron algunos inconvenientes. Se utiliza como banco de prueba una matriz de $2x1$, dos bancos de una celda y se observaron los siguientes resultados:

\begin{itemize}
    \item Banco 1 OFF, Banco 2 ON,
    \begin{figure}[H]
        \centering
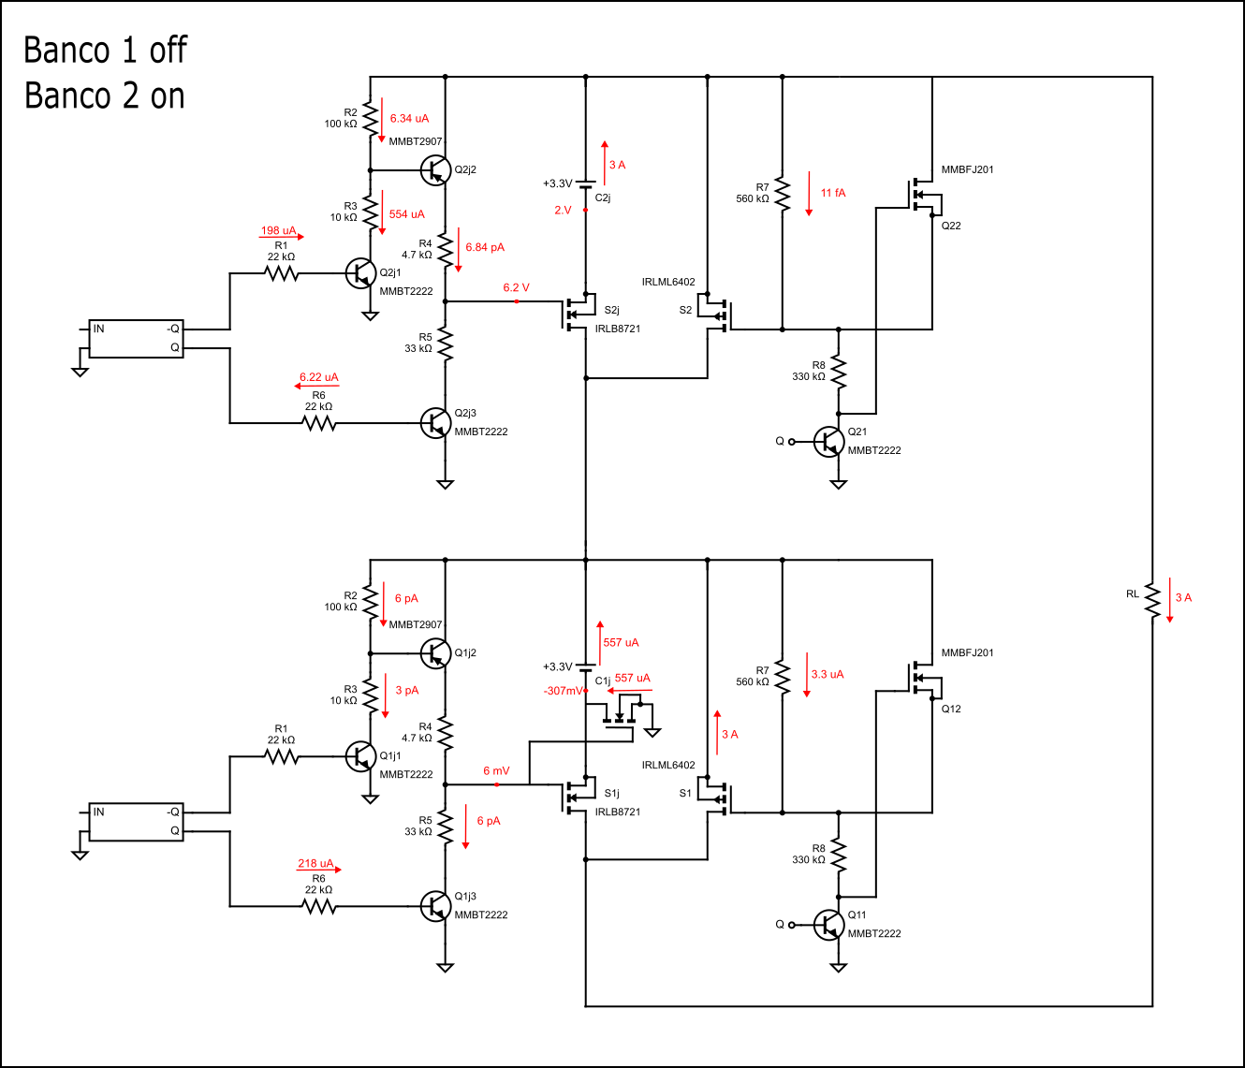
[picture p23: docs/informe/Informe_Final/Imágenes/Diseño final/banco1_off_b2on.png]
        
        \caption{ Análisis de corriente para la configuración: \textit{Banco 1 OFF, Banco 2 ON}}
        \label{fig:banco1_off_b2on}
    \end{figure}

    \item Banco 1 ON, Banco 2 OFF,
    \begin{figure}[H]
        \centering
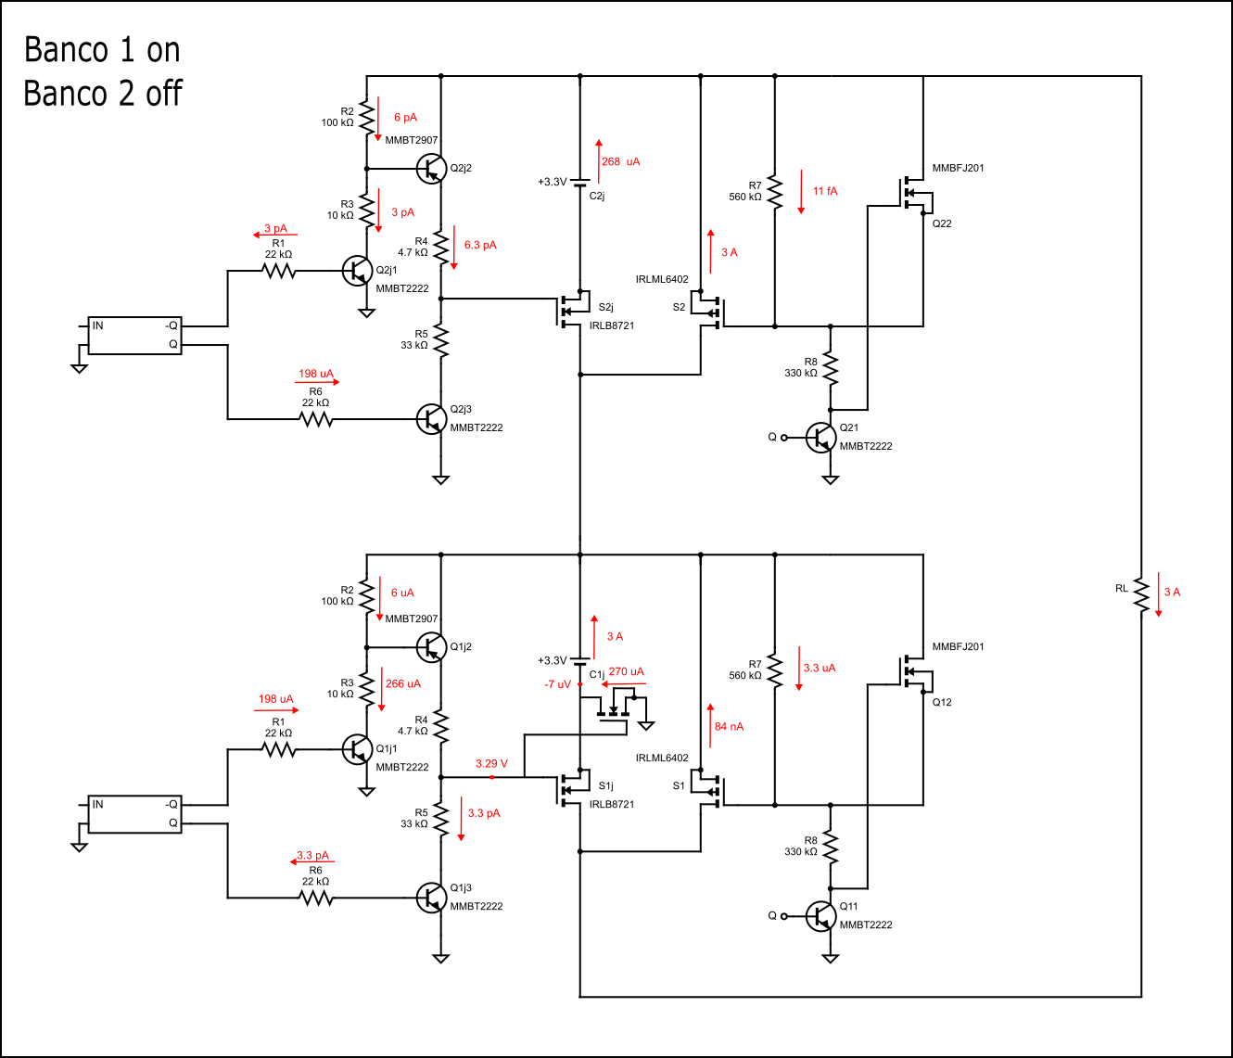
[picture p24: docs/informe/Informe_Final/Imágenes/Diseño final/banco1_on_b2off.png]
        
        \caption{Análisis de corriente para la configuración: \textit{ Banco 1 ON, Banco 2 OFF}}
        \label{fig:banco1_on_b2off}
    \end{figure}
    \item Banco 1 ON, Banco 2 ON,
    \begin{figure}[H]
        \centering
        
        \caption{Análisis de corriente para la configuración: \textit{Banco 1 ON, Banco 2 ON}}
        \label{fig:banco1_on_b2on}
    \end{figure}
    
\end{itemize}
Lo primero en notar de esta situación (fig. \ref{fig:banco1_off_b2on}) es la corriente en el MOSFET de tierra, esto provoca una tensión negativa en el terminal negativo de la celda. Analizando la corriente en cada componente del circuito de la celda, es posible notar que dicha corriente se genera en el driver del banco 2. Al encender la celda del banco 2, es decir encender el TBJ NPN $Q_{2j2}$, el colector queda a tierra, cerrando la malla atraves de la tierra virtual del MOSFET de tierra. Como no hay una referencia a GND para cada banco, al agregar bancos aumenta la tensión que percibe el driver de dicho banco, resultando en un aumento de corriente en el colector del TBJ de encendido.

Como se ve en (fig. \ref{fig:banco1_on_b2off}), y en (fig. \ref{fig:banco1_on_b2on}), este efecto ocurre incluso en caso de estar el banco 1 encendido. Al estar la celda del banco 1 encendida, se produce el efecto de la tierra virtual obteniendo que la celda tenga su terminal negativo a GND, pero al medir la corriente que circula en el MOSFET de tierra, se sigue viendo lo descripto anteriormente. Esto principalmente ocurre por que hay un único GND global para todo el circuito y la tierra virtual resulta ser el mismo. 

\subsection{Diseño del controlador}

Para el controlador de este diseño modular, no es posible partir del controlador del prototipo, es necesario un nuevo planteo. Los principales cambios son debido al \textit{hardware}, los cuales afectan a la lógica del software. 

Toda la lógica de encendido ahora depende del SR, a diferencia del controlador del prototipo donde cada switch era un pin del \textit{GPIO}. acá solo hay un pin de \textit{Data} y es el SR el que se encarga de seleccionar el switch a accionar. A cada banco le corresponde un switch, y a modo de mantener todo sincronizado y ahorrar pines \textit{GPIO}, se decide que los pines del SR \textit{Latch} y \textit{Clock} serán los mismo para toda la matriz. Esto implica que cada vez se envía un pulso de \textit{clock} el bit actual en data de todos los bancos será desplazado, de igual manera con un pulso de \textit{latch}. Por lo tanto hay que tener precaución  al enviar los pulsos de \textit{latch} y \textit{clock} para evitar enviar información basura a los \textit{switches}.

Por lo tanto, ahora se organiza el controlador por jerarquías. Se siguen mandando las instrucciones por \textit{USART}, y el que las maneja es el \textbf{controlador} el cual tiene un conjunto de bancos, a cada banco le asigna un SR. Desde el banco solo se va a poder enviar un '1' o un '0', pero sin activar el \textit{clock}, es el controlador el que se va a encargar de los mandar pulsos de \textit{clock} y \textit{latch} solo cuando todos los pines de data

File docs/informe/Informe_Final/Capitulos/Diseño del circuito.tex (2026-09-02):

\section{Diseño del circuito}

%---> Que es una celda y que es un banco
El circuito propuesto surge a partir del trabajo de \cite{kim2012self}, donde se implementa una plataforma de ecualización activa mediante el método de \textit{bypass}. En este contexto y con el fin de unificar la terminología de este informe, se denomina \textit{celda} a la unidad de almacenamiento que convierte energía química en energía eléctrica constituida por un ánodo y un cátodo. Cada una de estas celdas se conecta a un circuito para habilitar o deshabilitarla, al cual llamaremos \enquote*{\textit{switch}}. Por otro lado, el conjunto de celdas conectadas en paralelo se denomina \enquote*{banco}, los cuales cuentan con su propio \textit{switch} de \textit{by-pass} para asegurar la continuidad del sistema. Se conectan los bancos en serie formando una matriz, como se ve en la figura \ref{fig:matriz_de_celdas}, a la cual se designa como \enquote*{batería}. En esta plataforma, se trabajará con celdas LiFePo4 de valor nominal de \SI{3.2}{\volt} (con valores mínimo y máximo de \SI{2.5}{\volt} y \SI{3.7}{\volt} respectivamente).

%[ARGREGAR DIBUJITOS CON EL CAMINO DE LA CORRIENTE CUANDO ESTAN PRENDIDAS/APAGADAS LAS CELDAS]

% LISTO [AGREGAR LA EXPLICACION DE LA BATERIA RECONFIGURABLE CON LA POSIBILIDAD DE ELIMINAR CELDAS DE SERVICIO]

% LISTO [AGREGAR UN PARRAFO DE COMO ECUALIZARIAMOS CON ESTO]

\begin{figure}[H]
    \centering
    
    \caption{Esquema de la matriz de celdas propuesta \cite{kim2012self}.}
    \label{fig:matriz_de_celdas}
\end{figure}

Ambos grupos, el de celdas y el de los \textit{switches}, se unifican mediante el controlador formando la plataforma experimental de la figura   \ref{fig:esquema_bateria}. Para mayor claridad se denominaron \enquote*{bus positivo} (o \enquote*{bus\_pos}, como se lo llamó más comúnmente) al nodo del terminal positivo de la celda y \enquote*{bus negativo} (o \enquote*{bus\_neg}) al nodo conectado al borne del \textit{switch} más alejado de su celda.

\begin{figure}[H]
    \centering
    
    \caption{Esquema de la plataforma experimental adaptado de \cite{kim2012self}.}
    \label{fig:esquema_bateria}
\end{figure}

El principio de funcionamiento de la matriz consiste en encender o apagar los \textit{switches} de cada celda para lograr la tensión deseada en la salida del circuito. El controlador se encarga de dicha mecánica y de seleccionar a los bancos más apropiados para alcanzar la tensión objetivo maximizando el tiempo de vida útil de la misma.

Además de la ecualización previamente mencionada, esta topología permite crear una batería reconfigurable. Como los bancos están en serie, prendiendo o apagándolos es que se puede decidir si la tensión de salida del sistema corresponderá a la de una celda, dos, tres, etcétera. Es decir, que se podrá obtener una tensión típica de salida $n\times\SI{3.2}{\volt}$, siendo $n$ un número a elegir entre $1$ y la cantidad de bancos en la batería.

Esta funcionalidad presenta dos grandes ventajas. Por un lado, la posibilidad de modificar en tiempo real mediante el controlador la tensión que se desea obtener, basta con elegir el número de bancos encendidos. Por otro lado, si no están todos encendidos a la vez, se los puede alternar periódicamente para prolongar el tiempo de funcionamiento del sistema antes de necesitar ser cargado.

\subsection{Esquema base}

 La figura \ref{fig:circuito_original} muestra cómo fue el planteo original del circuito:

\begin{figure}[H]
    \centering
    
    \caption{Circuito obtenido de \cite{kim2012self}.}
    \label{fig:circuito_original}
\end{figure}

Este esquema presenta dos partes con funciones diferentes. El lado izquierdo corresponde al circuito responsable de prender y apagar cada celda. A su vez, el derecho es similar para los bancos. En ambos casos a modo de llave se usa un transistor MOSFET junto con TBJs para sus respectivas etapas de control.

\begin{comment}
    Agregar que se trabaja con una fuente externa.
\end{comment}

\subsubsection{\textit{Switch} de las celdas}

%--> Como funciona el switch (el camino de la señal de la señal de control para encender switch)
%--> Que componentes se consiguen

El circuito de las celdas consta de un N-MOSFET en serie con la celda. De esta forma, al encender el MOSFET se cierra la malla y se obtiene como salida la tensión de la celda. Para lograr esto con éxito es crucial que la tensión $R_{DS}$ del transistor sea lo más chica posible. El otro caso es con el MOSFET apagado, dejando a la celda en una malla abierta, apagándola.

Por otro lado, también se tiene la etapa de control, la cual recibe una señal de entrada y su negada, que definen si se debe prender o apagar el sistema. En las figuras(fig.  \ref{fig:celda_encendida}) y(fig.  \ref{fig:celda_apagada}) se pueden ver ambos casos.

\begin{figure}[H]
    \centering
    \begin{subfigure}{0.48\textwidth}
        \centering
        
        \caption{}
        \label{fig:celda_encendida}
    \end{subfigure}
    \hfill
    \begin{subfigure}{0.48\textwidth}
        \centering
        
        \caption{}
        \label{fig:celda_apagada}
    \end{subfigure}
    \caption{Circuitos de una celda encendida (a) y apagada (b).}
    \label{fig:circuito_celda_on_off}
\end{figure}

Cuando se recibe la señal de encendido (\textit{IN} $= 1$) como en la figura(fig.  \ref{fig:celda_encendida}), se enciende directamente el TBJ NPN $Qij_1$, el cual a su vez enciende el PNP $Qij_2$. Esto implica un aumento de tensión en el nodo de \textit{gate} del MOSFET, permitiendo conducción a través de él. Esto se mantiene así hasta que el capacitor MOS se carga, cortando el paso de la corriente a través de $Qij_2$. Como se mencionó previamente, con el MOSFET prendido se obtiene la tensión de la celda a la salida.

Con respecto a las resistencias, sus ubicaciones y valores cumplen un rol específico. En un principio, las resistencias en las bases de los TBJs ($R_1$ y $R_6$) están para limitar la corriente que entra a la base de los transistores. Por otro lado, las resistencias $R_2$ y $R_3$ tienen valores elevados de forma tal que la corriente de colector del TBJ NPN $Qij_1$ se reducida en valor. Esto último es crucial, dado que la etapa de control también está siendo alimentada por las mismas celdas por lo que se busca minimizar la potencia consumida en dicha etapa. De forma similar se toman los valores de las resistencias $R_4$ y $R_5$: se buscan valores elevados para que la corriente circulando a través de $Qij_2$ sea chica, pero no tan elevado como para realentizar excesivamente la descarga del capacitor MOS cuando se apaga la celda.

Con estas consideraciones en mente, se tiene el otro caso, el de apagar de la figura(fig.  \ref{fig:celda_apagada}), el cual funciona de forma más simple. $Qij_1$ y $Qij_2$ están apagados pero sí se enciende $Qij_3$. Con este TBJ, el \textit{gate} del MOSFET tiene conexión a tierra, permitiendo su descarga. De esta forma se lo puede apagar y abrir la malla que contiene a la celda.

Finalmente, se tiene el diodo \textit{zener}. Su rol es de protección: si por alguna falla, la tensión toma un valor demasiado elevado, se puede eliminar el pico a través del \textit{zener} y descargarlo a tierra por el transistor $Qij_3$. De esta forma, dicho pico de tensión no se propaga por el circuito ni afecta a la salida del sistema.

\subsubsection{\textit{Switch} de los bancos}

%--> Para que está el switch
%--> Como debe ir sincronizado con las celdas del banco
%--> Como se enciende el switch
%--> Para que esta el Jfet
%--> Que componentes se consiguen

El \textit{switch} de cada banco solo entra en funcionamiento cuando todas las celdas del banco se encuentras apagadas. Encender $S_i$ permite garantizar la existencia de un camino eléctrico entre las celdas previas ($S_{(i-n)}$) y los terminales de la batería. El \textit{switch} tiene dos estados posibles: en caso de apagarse las celdas, éste se debe encender; de otro modo, en caso de hallarse al menos una celda encendida se deberá mantener el \textit{switch} apagado.

El P-MOSFET debe accionarse según el estado de las celdas del banco evitando el solapamiento con el N-MOSFET de cualquier celda. Al momento de encenderse, se deben apagar las celdas y luego se procede a habilitar el \textit{switch} del banco. En caso contrario es necesario tomar medidas más cautelosas, al encender las celdas es obligatorio tener el P-MOSFET apagado, pero su conmutación no es instantánea, y en estos instantes aún existe conducción, dando lugar a la posibilidad de tener dos caminos uno por $S_i$ y otro por $S_{ij}$. La velocidad de conmutación del \textit{switch} depende de la velocidad de descarga de su compuerta, por lo tanto, para mejorar este aspecto se encuentra el JFET. Éste solo entra en funcionamiento cuando se apaga el P-MOSFET, y ofrece un camino de menor impedancia para descargar la compuerta del P-MOSFET, logrando acelerar la conmutación de \textit{switch}.

A nivel circuital, planteando como estado inicial el circuito apagado, tenemos en el \textit{gate} aproximadamente la tensión de la celda obteniendo un \textit{$v_{gs} \simeq 0$}. Por lo tanto, para encender el P-MOSFET(fig.  \ref{fig:banco_encendido}, se inyecta un pulso positivo en la base de $Q_{i1}$, esto provoca que baje la tensión del nodo colector del mismo, obteniendo un \textit{$V_{GS}$} más negativo el cual enciende el \textit{switch}. Luego, para apagar el switch, se necesita un pulso negativa en la entrada del $Q_{i1}$, volviendo a subir la tensión a el nivel de celda, 

\begin{figure}[H]
    \centering
    \begin{subfigure}{0.48\textwidth}
        \centering
        
        \caption{}
        \label{fig:banco_encendido}
    \end{subfigure}
    \hfill
    \begin{subfigure}{0.48\textwidth}
        \centering
        
        \caption{}
        \label{fig:banco_apagado}
    \end{subfigure}
    \caption{Circuitos de un banco encendido (a) y apagado (b).}
    \label{fig:circuito_banco_on_off}
\end{figure}

%[DEJAR ABIERTA LA POSIBILIDAD DE EXPLICAR EL PORQUE PARTICULAR DE CADA VALOR DE LOS COMPONENTES]

\subsection{Cambios funcionales}

%--->Porque anda mal, y los cambios para que funcione
%---> Porque ponemos [Rout]? En principio para que no tire error ltspice. Además sirve para modelar la resistencia interna de la celda. Por otro lado los dejamos para tomar mediciones en la placa.

Al circuito descrito previamente se le aplicaron sucesivos cambios. El principal problema es que en algunos aspectos fallaba y no cumplía correctamente su rol de ecualizador. Algunos de los cambios fueron hechos para corregir dichos problemas, mientras que otros simplemente para mejorar el funcionamiento del sistema en ciertos aspectos.

En un principio, debe hacerse la aclaración de cómo se toma la salida. La salida es diferencial, tomando la tensión entre los buses positivo del último banco y el negativo del primero. Importante notar que en el circuito original no hay tierra en la malla de salida. Este fue una de los primeros problemas que se detectó y se corrigió.

\subsubsection{Incorporación de tierra flotante}

%-->Primero probamos solo poniendo la tierra
%-->Despues agregamos una resistencia, y variamos la resistencia
%--->Agregamos el mosfet para tener la celda a tierra cuando la celda está encendida (con una resistencia considerable) y flotando cuando este apagada.

%[PONER POR QUE SE PUSO LA TIERRA FLOTANTE Y LOS GRAFICOS DE COMO QUEDA CON Y SIN EL CAMBIO]

Se simula el circuito propuesto en(fig.  \ref{fig:circuito_original}) evaluando el comportamiento de un banco con una única celda. En esta simulación se encuentran algunos defectos respecto al funcionamiento planteado, como se muestra en la figura(fig.  \ref{fig:primer_simu_funcional}).En la salida se alcanza el valor de tensión esperado correspondiente a una celda encendida, sin embargo al apagar la celda, la tensión no cae a cero.
Esto se debe a que en la celda aun hay corriente, es decir que la celda nunca se apaga. 

\begin{figure}[H]
    \centering
    
    \caption{Primer resultado de simulación con el circuito propuesto}
    \label{fig:primer_simu_funcional}
\end{figure}

La solución propuesta es colocar una tierra en el terminal negativo de la celdas del primer banco, proporcionando una referencia a tierra absoluta para el resto de la matriz. Esto proporciona un camino de descarga para todas las cargas residuales, evitando así las corrientes parásitas. De esta forma se asegura el apagado completo de la celda.

Con esta solución surgen fugas en esta nueva tierra, por lo tanto, en un intento de solucionar  este problema, se coloca una resistencia en la tierra  (fig.  \ref{fig:detalle_resistencia_en_tierra}). En este caso si se observan resultados positivos en el apagado de la celda, a mayor resistencia, menor la corriente que se fuga por la tierra. Pero surge un efecto negativo, a resistencias altas se observan deformaciones en la salida, los bancos superiores dejan de funcionar bajo lo indicado por la señal de control y solo replican la condición del banco 1. Para observar esta situación, se propone utilizar como banco de pruebas en ltspice la siguiente configuración, 

\begin{itemize}
    \item Matriz 2x2
    \item Entrada de control pulso de \SI{10}{\milli \second}, con un tiempo de encendido de 10ms.
     \item Periodo de \SI{20}{\milli \second}
      \item Configuración 1:Bancos sincronizados (ambos bancos comienzan encendidos).
     \item Configuración 2: Bancos desincronizados, es decir banco 1 comienza encendido, banco 2 comienza apagado.
\end{itemize}

\begin{figure}[H]
    \centering
    
    \caption{Detalle del circuito con conexión a tierra en el terminal negativo de la celda mediante una resistencia.}
    \label{fig:detalle_resistencia_en_tierra}
\end{figure}

\begin{figure}[H]
    \centering

    \begin{subfigure}{\textwidth}
        \centering
        
        \caption{Tensión de salida.}
        \label{fig:config1-barrido_de_res-tension_salida}
    \end{subfigure}

    \vspace{0.8em}

    \begin{subfigure}{\textwidth}
        \centering
        
        \caption{Corriente en la celda.}
        \label{fig:config1-barrido_de_res-corriente_celda}
    \end{subfigure}

    \label{fig:config1-barrido_res}
\end{figure}

\begin{figure}[H]\ContinuedFloat
    \centering

    \begin{subfigure}{\textwidth}
        \centering
        
        \caption{Corriente en tierra.}
        \label{fig:config1-barrido_de_res-corriente_en_tierra}
    \end{subfigure}

    \caption{Barrido de resistencias en la tierra para la configuración 1.}
\end{figure}

\begin{figure}[H]
    \centering

    \begin{subfigure}{\textwidth}
        \centering
        
        \caption{Tensión de salida.}
        \label{fig:config2-barrido_de_res-tension_salida}
    \end{subfigure}

    \vspace{0.8em}

    \begin{subfigure}{\textwidth}
        \centering
        
        \caption{Corriente en la celda.}
        \label{fig:config2-barrido_de_res-corriente_celda}
    \end{subfigure}

    \label{fig:config2-barrido_res}
\end{figure}

\begin{figure}[H]\ContinuedFloat
    \centering

    \begin{subfigure}{\textwidth}
        \centering
        
        \caption{Corriente en tierra.}
        \label{fig:config2-barrido_de_res-corriente_en_tierra}
    \end{subfigure}

    \caption{Barrido de resistencias en la tierra para la configuración 2.}
\end{figure}

A partir de lo expuesto, se coloca un MOSFET en la tierra, coordinado con el MOSFET de la celda (fig.  \ref{fig:mos en tierra}). Hay dos opciones de conexión, se puede conectar el drain o el source a tierra. Utilizando el banco de pruebas indicado anteriormente en la configuración 1, no se observan diferencias en el comportamiento del circuito con ambas opciones de conexión. Sin embargo al utilizar la matriz en la segunda configuración, el caso del drain a tierra, provoca que el segundo banco no genere la tensión de salida esperada. (fig. \ref{fig:tension-salida_comparacion_mos}).

\begin{figure}[H]
    \centering
    
    \caption{Circuito con un N-MOSFET entre la tierra y el terminal negativo de la celda.}
    \label{fig:mos en tierra}
\end{figure}

Este cambio (fig. \ref{fig:mos en tierra}) soluciona el problema del apagado de la celda, cuando el N-MOSFET esta apagado funciona como una gran resistencia. Cuando el N-MOSFET está encendido proporciona una tierra para el terminal negativo de la celda.

[INSERTAR IMAGENES DE COMPORTAMIENTO DEL MOSFET PARA DRAIN O SOURCE A TIERRA]
\begin{figure}[H]
    \centering
    
    \caption{Comparación de la tensión en la salida para ambas conexiones del mosfet}
    \label{fig:tension-salida_comparacion_mos}
\end{figure}

\begin{comment}
mosfet prendido -> tierra
mosefet apagado->resistencia
\end{comment}

\subsubsection{Capacitor en la salida}

Al realizar simulaciones con más de un banco surge otro problema, al intercalar un banco por otro, en el instante de switch se genera un pico de tensión. En el instante de conmutación al apagar un banco la salida cae a cero, y luego al encenderse el otro vuelve a subir a la tensión correspondiente. Esto se da en un pequeño instante, pero idealmente la salida debe ser constante, por lo tanto para oponerse a los cambios bruscos de tensión, se coloca un capacitor en la salida en paralelo a la carga. 

\begin{comment}
[INSERTAR COMPARACIÓN DE SALIDA CON Y SIN CAP]
\end{comment}

\subsubsection{Pruebas con \textit{delay} en la entrada}

%[Se buscaba solucionar el problema de los picos de corriente, no se pudo]

Otro inconveniente que se tenía fue la presencia de picos de corriente de las celdas. en el instante del \textit{switcheo} como se muestra en la figura \ref{fig:I_cell_s_delay_s_zoom}. Cabe destacar que estos picos aparecían solamente en las celdas pero no se veían reflejados en la salida. A su vez, se daba cuando se pasaba de todas las celdas del banco apagadas, es decir, todos los N-MOSFETs abiertos, a al menos una prendida. 

En los mismo gráficos se aprecia que el encendido y apagado se hace correctamente pero con grandes picos de corriente entre apagado y prendido. Estos valores son de dos órdenes de magnitud mayores a la corriente esperada y puede llegar a dañar la celda.

\begin{figure}[H]
    \centering
    \begin{subfigure}{0.9\textwidth}
        \centering
        
        \caption{}
        \label{fig:I_cell_s_delay_s_zoom}
    \end{subfigure}
    \begin{subfigure}{0.9\textwidth}
        \centering
        
        \caption{}
        \label{fig:I_cell_s_delay_c_zoom}
    \end{subfigure}
    \caption{Corriente simulada de la celda 12 en función del tiempo con \textit{switcheo}, valores totales (a) y con \textit{zoom} en las bajas corrientes (b).}
    \label{fig:I_cell_s_delay}
\end{figure}

Después de analizar la situación se llegó a la conclusión que esto se debe a que el cambio de los MOSFETs de las celdas y del banco no se daban exactamente a la vez. 

\begin{figure}[H]
    \centering
    \begin{subfigure}{0.32\textwidth}
        \centering
        
        \caption{}
        \label{fig:pico_i_pmos}
    \end{subfigure}
    \hfill
    \begin{subfigure}{0.32\textwidth}
        \centering
        
        \caption{}
        \label{fig:pico_i_ambos}
    \end{subfigure}
    \hfill
    \begin{subfigure}{0.32\textwidth}
        \centering
        
        \caption{}
        \label{fig:pico_i_nmos}
    \end{subfigure}
    \caption{Esquemas de la progresión del \textit{switcheo} de una celda y del banco cuando se pasa de todas las celdas del banco apagadas a una prendida.}
    \label{fig:pico_corriente_esquema}
\end{figure}

En la figura (fig.  \ref{fig:pico_corriente_esquema}) se aprecia la progresión de izquierda a derecha de la situación descrita previamente. Se parte de la posición inicial de la figura (fig.  \ref{fig:pico_i_pmos}), donde están los \textit{switches} de las celdas abiertos y el del banco cerrado. Sin embargo, el problema radica en que el cierre de un MOSFET es más rápido que su apertura. Entonces, cuando se da la orden de prender la celda (por ende, abrir el \textit{switch} del banco a la vez), ocurre lo de la figura (fig.  \ref{fig:pico_i_ambos}). Queda formada una malla con muy baja impedancia, siendo las $R_{DS}$ de los dos MOSFETs las únicas resistencias presentes, lo que produce el nombrado pico de corriente en la celda. Una vez se carga el capacitor del P-MOSFET, se transita al esquema(fig.  \ref{fig:pico_i_nmos}), donde se vuelve al funcionamiento correcto.

\subsubsection{Resistencias del nodo de \textit{gate} de los N-MOSFET}

->Se descarga más rápido el mos, mejorando el problema del delay

\subsubsection{Selección de componentes}
%[Componentes no lineales que se mantuvieron: TBJs NPN y PNP, JFET]

Para seleccionar los componentes se parte de los propuestos en \cite{kim2012self}. Los TBJs y el JFET aun es posible encontrarlos en el mercado y  funcionan para las tensiones esperadas en esta matriz, por lo que se mantienen en el circuito final. El resto de los elementos son reemplazados priorizando que estos estén disponibles en el mercado local.

\paragraph{MOSFET}

Dado que el componente utilizado en el circuito original es obsoleto, se analizan nuevas opciones, que cumplan con lo pedido en \cite{kim2012self},

\begin{itemize}
    \item Tensión $V_{GS}$ baja, preferentemente mucho menor que la tensión de las celdas.
    \item MOSFET de potencia. No es un aspecto crítico, pero debe permitir la circulación de corrientes del orden de \SI{1}{\ampere}, por lo tanto se busca que tenga una $R_{DS_{on}}$ muy baja. Esto permite la circulación bidireccional de corriente con perdidas mínimas.
    \item Minimizar el calentamiento, se buscan componentes con una resistencia térmica baja o que permitan el uso de disipadores térmicos.
\end{itemize}

Para el caso de los N-MOSFET, no se encuentran dificultades para encontrar reemplazos, se prueban las opciones, y se selecciona la que ofrece el nivel de tensión esperado en la salida. En cambio esto no sucede para los P-MOSFET, el modelo utilizado en el paper no se consigue actualmente, por lo tanto se buscan sustitutos que cumplan las condiciones expuestas. El primer modelo elegido AO3401A, cumple con los primeros items y en simulacion se comportaba como era necesario, sin embargo al revisar la potencia disipada, nos encontramos que no cumple con el ultimo item, por lo tanto se busca un sustito nuevamente. Como nueva solución, se consigue otro mosfet SMD, el cual cumple con las exigencias, bajo las condiciones típicas, en el caso del $v_{th}$ máximo, no sería posible encender correctamente el dispositivo.

\begin{comment}
    la mayoría de las opciones disponibles tienen un $V_{GS}$ en el rango de [2, 4]\si{\volt}, y otras producen mucho calentamiento. Por lo tanto, los MOSFET que mejor se adecúan al circuito propuesto son,

    [PONER LA EVOLUCIÓN DEL P-MOSFET (PRIMERO EL DEL PAPER, DESPUÉS OTRO QUE NO ERA DE POTENCIA, DESPUÉS PROBAMOS MÁS Y FINALMENTE EL ÚLTIMO)]
\end{comment}

\begin{itemize}
    \item \small{\textbf{N-MOSFET: } IRLB8721.}
    \item \small{\textbf{P-MOSFET: } FDMS6681Z.}
\end{itemize}

En ambos casos, se trata de MOSFET de potencia; en el primer caso es un THT, una opción fácil de conseguir, y en el segundo se trata de un dispositivo SMD de potencia que logra cumplir los requerimientos con márgenes ajustados. En condiciones normales de operación, permiten prescindir de disipadores de corriente, evitando condiciones de estrés térmico.

\paragraph{TBJ}
Para la etapa de control no hay requerimientos esenciales, por lo tanto se eligen TBJ típicos para el canal n y p, en versión smd, siendo esta la única condición  de diseño.
\paragraph{JFET}
En el caso del JFET, se buscan dispositivos de bajo consumo, y con alta impedancia de forma que sea posible conectarlo a la celda.

%[Componentes que se cambiaron: NMOS, PMOS, \textit{zener}, inversores]

%//Requsitos para elegir los MOS

%-vgs chico (nos costo encontrar uno de potencia con vgs menor a 3V)
%-potencia (Para que se banque la corriente de todos los bancos)
%-térmicos (El pmos smd no tiene disipador termico, tienen que bancarse el calor sin disipador)

\paragraph{Zener}

No se indica en \cite{kim2012self} un modelo de diodo Zener; por lo tanto, se elige uno que se adapte a los nuevos parámetros del circuito. Se busca que la tensión nominal del Zener sea lo más cercana a la tensión máxima que permita la celda. La corriente que circule por esta rama se espera que sea despreciable, lo que permite elegir un diodo de baja potencia. Se elige el diodo Zener de $V_z = \SI{3.9}{\volt}$ y \SI{1}{\watt}. 

%// Zener: seleccionamos uno adecuado para la celda que vamos a usar

\paragraph{Inversor}

Para la entrada de control, en el circuito original se propone el uso de un \textit{flip-flop} para generar las señales complementarias en los transistores $Q_{ij1}$ y $Q_{ij3}$. En este proyecto, para simplificar la implementación se reemplaza el \textit{flip-flop} por una compuerta \textit{NOT}. Toda la lógica de control se desarrolla en el microcontrolador, por lo tanto las operaciones y secuencias conmutación se trasladan al dispositivo de control. 

Permitir un mínimo de lógica digital en el diseño de la placa, ayuda a optimizar los recursos del microcontrolador. El uso del inversor permite reducir los pines \textit{gpio} necesarios, controlando ambas entradas del driver de $S_{ij}$ mediante una única señal y eliminando la necesidad de lógica externa adicional.

Para garantizar el funcionamiento correcto del circuito es necesario insertar tiempos muertos durante la conmutación del \textit{switch} del banco y el de las celdas para evitar estados no deseados durante la transición.

%//Inversor: cambiamos el flip flop por un inversor.

[QUIZAS: VER SI AGREGAR UNA SUBSECTION DE POTENCIA/CONSUMO/*EFICIENCIA* PARA COMPARAR CON LAS MEDICIONES CUANDO ESTEN]

\paragraph{Resumen}

%[AGREGAR UNA TABLITA CON LOS COMPONENTES Y SUS REQUISITOS, INCLUYENDO A LOS TBJS Y EL JFET QUE NO CAMBIAMOS]

A modo de resumen se presenta la siguiente tabla con los requisitos que debe cumplir cada uno de los componentes del circuito y cuáles fueron finalmente los elegidos que cumplen. Cabe destacar que lo primero que se revisó para cada uno de los componentes es la disponibilidad en el mercado local.

\begin{table}[H]
\centering
\begin{tabular}{>{\centering\arraybackslash}m{2.8cm} m{8cm} >{\centering\arraybackslash}m{3.2cm}}
\hline
\textbf{Componente} & \multicolumn{1}{c}{\textbf{Requisitos}} & \textbf{Modelo elegido} \\ \hline
N-MOSFET    & \vspace{4pt}\begin{itemize}[leftmargin=*, nosep]
                \item Tensión $V_{GS}$ igual o menor que la tensión de la celda
                \item Que sea de potencia
                \item Baja resistencia térmica
            \end{itemize} & IRLB8721   \\ \hline
P-MOSFET    & Similar al N-MOSFET con la consideración que debe poder ser atravesado por la corriente de salida & FDMS6681Z  \\ \hline
TBJ NPN     & Bajo costo y alta disponibilidad & MMBT2222A  \\ \hline
TBJ PNP     & Bajo costo y alta disponibilidad & MMBT2907A  \\ \hline
JFET        & Bajo consumo e impedancia & MMBFJ201   \\ \hline
Diodo Zener & La tensión $V_Z$ debe ser la menor posible que siga siendo mayor a la tensión máxima de la celda (\SI{3.7}{\volt}) & 1N4730A    \\ \hline
Inversor    &   \multicolumn{1}{c}{-}    & CD40106    \\ \hline
\end{tabular}
\label{tab:componentes}
\caption{Resumen de los componentes seleccionados y los requisitos que deben cumplir.}
\end{table}

\subsection{Simulaciones en masa}

-->Se simulan distintos casos de configuraciones de celdas 

////////////

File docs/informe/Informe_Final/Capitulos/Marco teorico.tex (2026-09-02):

\section{Marco teórico}
\begin{comment}

-->Ver propuesta, baterias, ecualizacion pasiva y activa

1) QUE ES UNA BATERIA
2) QUE ES UN BMS -> FUNCIONES DEL BMS
3) ECUALIZACION-> PASIVA VS ACTIVA
4) SOLUCION PROPUESTA (breve porque se desarrolla bien en diseño del circuito)
\end{comment}
En la actualidad, con la creciente demanda energética, sumado a la reducción progresiva de la generación de electricidad mediante combustibles fósiles, son necesarias más y mejores forma de almacenar energía eléctrica. Las baterías de litio recargables como  Li-Ion, Li-Po, LiFePO4, etc,  demostraron ser una forma eficiente de almacenamiento.

Generalmente en la mayoría de aplicaciones en las que se requiere una bateriía, se necesita más de lo que puede suministrar una única celda. Por lo tanto, una batería es formada por un grupo de celdas, las cuales se conectan conformando una matriz que cumple con los requerimientos necesarios para el dispositivo en cuestión. Debido a variaciones en las condiciones de fabricación de cada celda, una única batería puede contener celdas con diferentes capacidades \cite{chen2015system}, distintos coeficientes térmicos o, incluso distinto envejecimiento . En cada carga y descarga, estas diferencias provocan desbalances en las carga almacenada en cada celda, parámetro conocido como SoC (\textit{State of Charge}) provocando \cite{rumpf2018influence}:

\begin{itemize}
    \item Disminución de la eficiencia,
    \item Reducción en la vida útil,
    \item Sobrecalentamiento,
    \item Riesgo de cortocircuitos por formación de filamentos de litio metálico.
\end{itemize}

Para mitigar estas complicaciones, el BMS, \textit{Battery Management System}\cite{quinones2019estudio}, debe cumplir el rol de garantizar un funcionamiento seguro de la batería protegiendo las celdas de sobrecarga, sobredescarga y sobrecorriente, asimismo mantener las condiciones seguras de operación dentro de los rangos adecuados de tensión y  temperatura y asi  prolongar la vida útil de las baterías todo lo posible,  En este contexto surge la necesidad de distribuir la energía de forma equitativa en toda la batería y así aprovechar la capacidad total de la misma \cite{lu2013review}. Para ello, la técnica de ecualización resulta una herramienta necesaria, y se puede clasificar en dos tipos de métodos, pasivos o activos, basándose en la topología del sistema. Se ecualiza a partir de una de las características de la batería como, el Soc, la tensión o la capacidad \cite{hua2020comprehensive}.

\begin{comment}
    cuadrito de metodos de ecualización?
\end{comment}

Los métodos pasivos son los más ampliamente difundidos por su simplicidad, fiabilidad y bajo costo. Suele tratarse de un \textit{shunt} resistivo conectado en paralelo a la batería para disipar el exceso de energía de las celdas. Este método aunque es simple y de baja complejidad, trae como desventaja una gran duración de ecualización debido a la baja energía de ecualización y también una corriente de balanceo restringida a los limites de disipación de calor del propio hardware , limitando el uso de este tipo de ecualización, principalmente en baterías de gran capacidad\cite{hua2020comprehensive}.Muchos de estos inconvenientes son posibles solucionar mediante ecualización activo pero aumentando la complejidad de y costo del circuito \cite{pericsoarua2018passive}.

\begin{comment}
    agregar imagen como ejemplo de la conexión del shunt
\end{comment}

Los circuitos de ecualización activa tienen una topología que no utiliza la disipación de la energía sobrante de una celda en su lugar, se transfiere la energía sobrante de una celda a otra celda del circuito o módulos utilizando componentes capaces de almacenar energía como, capacitores, inductores, transformadores, y convertidores,

%se requiere contar con un sistema de control que se encargue de medir el estado de cada celda y del balance de cargas para optimizar el desempeño general del sistema. A este controlador se lo denomina BMS, \textit{Battery Management System}, cuya tarea principal es la ecualización de las cargas . De esta forma se logran diversas estrategias como un \textit{shunt} resitivo para disipar la energía sobrante (balanceo pasivo \cite{li2023active}), convertidores DC-DC, capacitores conmutativos (balanceo activo \cite{li2023active}), entre otras tecnologías \cite{chen2015system}.

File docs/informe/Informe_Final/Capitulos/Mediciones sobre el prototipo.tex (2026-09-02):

\section{Mediciones sobre el prototipo}

[VER SI ESTÁ BIEN SEPARAR EN IMPLEMENTACIÓN Y MEDICIONES O HACERLO TODA UNA MISMA SECCIÓN]

Como se mencionó previamente, el objetivo del prototipo era verificar el correcto funcionamiento del circuito real. Para eso la etapa de medición es crucial, dado que se puede utilizar para buscar posibles errores y mejoras a implementar en el dispositivo final. Sin embargo, como medida cortafuegos, se decidió soldar el prototipo y medir de forma progresiva: primero una celda, luego un banco, y finalmente todo el circuito. De este modo, en caso de haber alguna falla crítica, se puede detectar de forma temprana antes de ya haber dedicado más trabajo y usado todos los componentes a disposición.

\subsection{Primera medición fallida en una celda del banco 1}

Lo primero que se soldó fue el circuito de una de las celda junto con la etapa de control del banco $1$. Aunque a simple vista parecía que todo estaba en orden, rápidamente se reveló que no era el caso.

[INSERTAR IMAGEN DEL KICAD Y FOTO DE ESTA CELDA]

En primer lugar se buscó verificar el funcionamiento en estado estacionario de la celda, por lo que se conectó a la entrada una fuente de tensión continua de \SI{5}{\volt} (con una corriente de hasta \SI{20}{\milli\ampere}). Esto debería ser suficiente para obtener como tensión de salida a la de la celda pero no fue el caso: la salida era nula con pequeñas variaciones ocasionales en torno a las decenas de milivolts.

Ante la temprana falla se midieron las caídas de tensión de todos los componentes en las mallas de control. Cuando se estaba midiendo la caída sobre el resistor $R_3$, el TBJ PNP $Qij_2$ comenzó a soltar humo. De este punto en adelante se desataron una serie de eventos desafortunados que concluyeron en el reemplazo de varios componentes más.

En el intento de desoldar el transistor para reemplazarlo, el diodo \textit{zener} también empezó a soltar humo. Fue tanta la temperatura que desprendió que el estaño que lo sujetaba se fundió. Cabe destacar que la fuente de continua no estaba conectada pero sí estaba colocada la celda. Aunque debido a la baja potencia que emite, ésta no debería haber sido la causa de la destrucción del diodo.

Luego, más humo se desprendió de lo que parecería ser el fusible de la celda. Éste fue rápidamente extraído, aunque luego de unas pruebas con multímetro se descubrió que ambos fusibles estaban perfectamente bien y que ninguno se había quemado.

Dado este nuevo suceso, se decidió que lo más probable que se haya quemado era el transitor N-MOSFET de la tierra, por lo que se lo desoldó. Debido a la proximidad con otros componentes, el calor del soldador fue tal que el plástico del portafusible de la celda se derritió. No hubo otra opción que también descartarlo, siendo el cuarto componente en seguidilla en ser eliminado y sin tener una clara idea de cuál fue el problema.

\subsection{Segundo intento de medición y primero exitoso}

Luego de los problemas del intento anterior, se priorizó restaurar los componentes en la placa, asegurándose en cada paso el correcto funcionamiento de los mismos. Comenzando por la etapa de control, se soldaron nuevos TBJ NPN y diodo \textit{zener}. Ingresando una tensión de control equivalente a un $1$ lógico (\SI{5}{\volt}) se corroboró la correcta apertura del transistor.

Luego, debido a la proximidad de los componentes y el gran tamaño relativo de los portafusibles, se decidió extraerlos. En su lugar se colocaron alambres para cerrar las mallas en las que estaban colocados.

Con lo soldado hasta ahora el sistema debería prender y apagar correctamente la celda. Lo único faltante es el N-MOSFET de la tierra. Cuando se lo desoldó, la pista quedó dañada y se soltó el \textit{pad}, por lo que colocarlo nuevamente resultaría dificultoso. Más adelante es algo que debe hacerse (y se hizo) pero por el momento se podría medir sin el transistor y cortocircuitar la tierra con el nodo correspondiente de forma manual con cables cuando sea necesario.

Con el circuito de la celda devuelto a casi su estado original se conectó todo para volver a medir. Cabe destacar que en lugar de la celda de litio se colocó una tensión a través de una fuente de continua. La razón detrás de esta decisión fue colocar una corriente máxima de \SI{100}{\milli\ampere} para, en caso de que algo falle, minimizar la probabilidad de quemar más componentes.

Con todo esto en mente, se encendieron las fuentes que emiten la tensión de la celda y la entrada de control y se obtuvo a la salida la tensión de la celda. Aunque un progreso respecto del último intento de medición, rápidamente se hizo notorio otro problema: la fuente de la celda estaba emitiendo corriente. Normalmente eso es lo que se esperaría ver salvo cuando la salida está abierta (como era el caso en cuestión) donde no debería haber corriente circulando. Estos valores rondaban los \SI{80}{\milli\ampere} o \SI{90}{\milli\ampere}, valores para nada despreciables. 

Midiendo la caída de tensión en cada componente se encontró la ubicación del problema: había caída de tensión en los resistores $R_7$ y $R_8$ correspondientes a la etapa de control del \textit{switch} del banco. En ellos caían [PONER VALOR TENSIONES].

[AGREGAR IMAGEN CON EL REDONDEL ROJO DE LOS RESISTORES EN CUESTIÓN]

Ese bloque estaba apagado por lo que no debería haber corriente circulando por sus componentes. Testeando continuidad en el nodo de [LA FIGURA QUE FALTA ARRIBA] hay un cortocircuito con tierra. Se desoldó el TBJ, el cual se partió a la mitad. Probablemente haya estado quemado, lo cual explicaría el humo visto previamente en el primer intento de medición que se había creído erróneamente que provenía de alguno de los fusibles. El cortocircuito seguía estando por lo que también se extrajo el JFET, momento en el cual se solucionó el problema.

Nuevamente se incorporan las fuente de tensión y esta vez sí se obtiene el resultado esperado: \SI{33.}{\volt} a la salida con corriente nula. Incorporando cargas de prueba se aprecia que la corriente de salida varía. El MOSFET de la tierra flotante sigue ausente pero se pudo corroborar el correcto funcionamiento del encendido y apagado de una celda.

\subsection{Problemas de diseño del prototipo}

Entre mediciones fallidas y valores no esperados, se pudieron identificar algunos errores de diseño. Por un lado por huellas mal elegidas, y por otro, por errores en el esquemático. Antes de detallarlos es importante destacar que ninguno de estos problemas son críticos ni inhibieron el circuito. Aunque simples de corregir para la versión final, requirieron de trabajo y tiempo al momento de identificarlos.

En primer lugar se tienen los problemas en las huellas, comenzando por la de los JFET. Debido a una confusión con los TBJ, los cuales usan el mismo encapsulado pero diferente configuración de los pines, la huella en \textit{KiCad} no coincidió con la dada en la \textit{datasheet}, como se muestra en la figura \ref{fig:JFET_pinout}.

\begin{figure}[H]
    \centering
    \begin{subfigure}{0.3\textwidth}
        \centering
        
        \caption{}
        \label{fig:JFET_pinout_datasheet}
    \end{subfigure}
    \hfill
    \begin{subfigure}{0.4\textwidth}
        \centering
        
        \caption{}
        \label{fig:JFET_pinout_kicad}
    \end{subfigure}
    \caption{\textit{Pinout} del JFET MMBFJ201 según la hoja de datos (a) y como fue configurado en la huella de \textit{KiCad} (b).}
    \label{fig:JFET_pinout}
\end{figure}

De forma similar, la huella de los diodos \textit{zener} estaba invertida. Esto significó una inversión del ánodo y el cátodo como se aprecia en la figura \ref{fig:zener_kicad}.

\begin{figure}[H]
    \centering
    
    \caption{Huella del diodo \textit{zener} utilizada en \textit{KiCad}.}
    \label{fig:zener_kicad}
\end{figure}

Siendo un elemento de protección, no tiene un rol activo en el funcionamiento del circuito, es más, si todo se desarrolla correctamente nunca debería actuar. Pero el hecho que se encuentre en directa conduciendo cuando no debería provocó valores altos de tensión en el nodo del \textit{gate} de los N-MOSFET cuando el sistema está apagado.

[PONER DIAGRAMA DE LA MALLA DEL CIRCUITO Y COMPLETAR]
[ESTA BIEN DECIR QUE LA TENSION ERA DE 3.3-0.7 EN EL GATE CUANDO ESTABA APAGADO?]

Por otro lado, se tiene la huella de los P-MOSFET. Aunque técnicamente era la huella correcta, la hoja de datos da un comentario que no se tuvo en cuenta. En la figura \ref{fig:pmos_config_datasheet} se ve que hay una región que debería estar libre de cobre en la placa, indicada como "KEEP OUT AREA".

\begin{figure}[H]
    \centering
    
    \caption{Vista inferior del transistor P-MOSFET FDMS6681Z mostrada en su \textit{datasheet}.}
    \label{fig:pmos_config_datasheet}
\end{figure}

Al no incorporar esa zona, hubieron complicaciones al momento de soldarlo: hicieron falta varios intentos de soldar y desoldar el transistor para evitar que el \textit{drain} entre en cortocircuito con el plano de tierra. Finalmente, lo que se decidió hacer es con un destornillador raspar parte del cobre y así evitar que entre en contacto con el MOSFET, como se muestra en la figura \ref{fig:pmos_arreglado}.

\begin{figure}[H]
    \centering
    
    \caption{Foto del transistor P-MOSFET FDMS6681Z soldado indicando la corrección que se hizo para que no haya cortocircuito entre el \textit{drain} y el plano de tierra.}
    \label{fig:pmos_arreglado}
\end{figure}

Al margen de los errores de huellas, hubo otro error menor de diseño con el \textit{jumper} del primer banco. Recordemos que se incorporaron \textit{jumpers} para cada banco, de forma que se pueda medir por separado cada uno usando siempre la misma bornera como salida para colocar carga. Sin embargo, para el primer banco, fue mal diseñado como se aprecia en la figura \ref{fig:jumper_mal}.

\begin{figure}[H]
    \centering
    \begin{subfigure}{0.45\textwidth}
        \centering
        
        \caption{}
        \label{fig:jumper_mal}
    \end{subfigure}
    \hfill
    \begin{subfigure}{0.45\textwidth}
        \centering
        
        \caption{}
        \label{fig:jumper_bien}
    \end{subfigure}
    \caption{Esquema de cómo fue diseñado el circuito prototipo erróneamente en \textit{KiCad} (a) y cómo debería haber sido (b).}
    \label{fig:jumpers}
\end{figure}

El objetivo de los \textit{jumpers} era poder seleccionar si la tensión de la bornera de salida correspondía a una de tres opciones: solo el banco 1, los bancos 1 y 2, o los tres bancos. Sin embargo, como fue diseñado el circuito, el \textit{jumper} correspondiente al primer banco no tenía función alguna, y, en caso que se conecte, se estaría poniendo peligrosamente en cortocircuito a las celdas.

Otro inconveniente fue la forma en la que se soldaron los transistores N-MOSFET. Con el objetivo de minimizar el uso de vías, se utilizaron algunos de los componentes THT para conectar pistas entre capas opuestas. Esto fue práctico usando resistores y diodos pero no fue buena idea con los transistores. Debido a tener pines gruesos, a la forma del encapsulado y a la ubicación en la placa, soldar en la capa \textit{front} resultó incómodo. Como consecuencia de esto, las soldaduras quedaron desprolijas y se torna complicado el proceso de desoldado si fuera necesario.

Por último, el mayor problema que tuvo la placa fue una pobre elección de P-MOSFET como \textit{switch} del circuito \textit{by-pass} de banco. Cuando el transistor debía estar encendido, la tensión $V_{GS}$ era de alrededor de $\SI{1.8}{\volt}$, sin embargo, la tensión de umbral típica (extraída de su hoja de datos) es de $\SI{1.7}{\volt}$. Esto quiere decir que, aunque tecnicamente el MOSFET estaba conduciendo, lo hacía con una resistencia $R_{DS}$ alta entre \textit{drain} y \textit{source}. Es por esto que se veían valores más bajos de lo esperado en la salida: unos $\SI{400}{\milli\volt}$ caen en cada uno de estos transistores cuando están encendidos. Es por esto que se decidió cambiarlo para el circuito final.

Problemas que recordamos:
    - X Huella JFET (corto en la fuente de tensión)
    - X Huella PMOS (corto de drain con tierra)
    - X Huella del Zener (casualidad)
    - X Jumper del banco 1 esta mal puesto
    - X NMOS con soldaduras en las dos capas
    - El PMOS no era correcto
Seguir investigando:
    - Zener funciona raro (no permite que el gate llegue a 0V)

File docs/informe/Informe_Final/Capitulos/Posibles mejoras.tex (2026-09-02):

\section{Posibles mejoras}

\begin{itemize}
    \item Resistores de la salida del SR en cada celda en lugar del banco.
    \item Resistor chiquito de protección en el inversor de cada celda.
    \item Implementación de micro por celda para poder usar protocolos de comunicación más sofisticados (y eliminar los jumpers).
    \item Implementación de tensión negativa en cada banco (ya sea mediante otra entrada o un ICL) para que el MUX pueda correctamente medir el valor de $cell\_neg$.
    \item Switches entre bancos y dip switches entre bancos y salida automáticos.
    \item Implementación de integrado para censado de corriente bidireccional.
    \item Implementación de $Vcc$ a partir de la batería misma.
\end{itemize}

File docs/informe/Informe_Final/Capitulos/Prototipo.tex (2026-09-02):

\section{Prototipo}

[Matriz $3\times2$, uso de celdas 18650 de \SI{3.2}{\volt}]

[PONER LAS MEDICIONES Y EL TESTEO COMO OTRA SECCION]

[AGREGAR UN APENDICE CON UN PEQUEÑO MANUAL DE USO DEL CIRCUITO]

\subsection{Diseño del prototipo}

[Uso de una fuente externa para los LEDs e inversores]
[ejamos el capatitor en una bornera en la salida para  ver cual sirve en la realidad]

\subsubsection{Diseño del esquemático}

[LEDs, portapilas, fusibles, \textit{test points}, \textit{jumpers}]

[POR QUÉ DISEÑAMOS ASÍ LA PLACA, ESPACIO, DISPOSICIÓN, ETCÉTERA]

\subsubsection{Diseño del PCB}

[Placa de $\SI{20}{\centi\meter}\times\SI{20}{\centi\meter}$ bifásica]

////////////

\subsection{Controlador para el prototipo}

[Selección de microcontrolador]

\subsubsection{Diseño del controlador para el prototipo}

[Primero se apaga lo que se deba apagar y después se enciende lo que se deba encender]
 
Para programar el controlador se utiliza la aplicación \textbf{\textit{STM32CubeIDE}}, este entorno permite desarrollar, compilar y depurar el código del microcontrolado, en este caso, \textbf{STM32 NUCLEO-F103RB}. Para la configuración inicial de la placa se utiliza la aplicación \textbf{\textit{STM32CubeMX}}, con la cual se crea el archivo \textit{.ioc}, almacenando toda la información de la configuración de los pines, y todos los archivos necesarios para el funcionamiento de la placa. En la STM32CubeMX
se configura la función de los pines, se habilitan los pines necesarios y se configura de ser necesario el clock, DMA, interrupciones, etc. Uno de los archivos que se generan, es el \textit{main.c}, donde se inicializan todos los periféricos, también proporciona el bucle principal \textit{while(1)}, en donde se pueden agregar las tareas principales.

 En el prototipo, el enfoque principal es diseñar el control manual para probar cada configuración de la matriz. Se utiliza el control manual para poder acceder y probar cada celda, este modo sirve para imitar las simulaciones en \textit{LTSpice} y evaluar el comportamiento del prototipo. 
 En una primera instancia se simplifica el diseño del controlador a determinar el estado de cada celda mediante linea de comandos (CLI), y a partir del estado de todas las celdas del banco, el controlador actualiza el estado del switch del banco según corresponda.
 
 Para este diseño cada switch es un pin distinto del microcontrolador, esto significa que se deben reservar 1 pin para switch del banco y 1 pin para el switch de la celda, resultando en 9 pines \textit{gpio} en modo salida para el prototipo. Cada pin se enciende o se apaga determinando su estado a través del HAL.

Otro requerimiento es la posibilidad de probar el \textit{modo de switching}, en este estado se espera poder encender y apagar los apagar los pines de forma alternada, permitiendo evaluar la conmutación entre celdas y entre bancos. No se espera que el sistema conmute a altas frecuencias en condiciones normales, pero si es necesario verificar como responde el sistema ante este caso. Por lo tanto, el programa del controlador debe tener la posibilidad de asignar el estado \textbf{\textit{switching}} a una celda, siempre actualizando de forma acorde el switch del banco. Se proponen dos opciones, switching sincronizado y complementario, para lograr esto se asignan flags a cada celda seleccionada y se actualiza de forma simultanea todos los pines. Al mismo tiempo, desde el CLI, se le asigna un grupo a cada celda, cada grupo responde a la frecuencia elegida. De esta forma se permite testear conmutación entre celdas, entre bancos, el sistema a distintas frecuencias, y grupos de celdas a distintas frecuencias, así como encontrar los limites en frecuencia del sistema.

Cabe destacar que para obtener una representación fiel de la frecuencia pedida, es necesario actualizar el estado según una base temporal constante. Para ese se puede utilizar el \textit{\textbf{SysTick}}, un temporizador integrado, el cual genera interrupciones periódicas cada \SI{1}{\milli \second}. Para utilizar esta base, se coloca la función correspondiente a la actualización de los pines dentro de la rutina de interrupciones, \textbf{$SysTick_Handler()$} así actualizando el estado de la matriz de forma regular. En caso de utilizar el bucle principal en \textit{main.c}, no se obtendría una base temporal constante, ya que la duración de una iteración depende de la duración del resto de las tareas.

[AGREGAR FOTITO DEL PUTTY]

\subsection{Implementación}

[DECIR QUE ESTABA \enquote*{MAL} LA HUELLA DEL PMOS]

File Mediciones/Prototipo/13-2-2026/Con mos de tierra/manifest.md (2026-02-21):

# Run: 13/2/2026

## Objetivo
Obtener una medicion del comportamiento actual, de chequear si es correcto

## Parámetros
Celda 12, soldada
Celda 11 y banco 1 aun no están soldados por completo
No está el mosfet de tierra conectado, y no hay tierra en cell neg
Rl = 47 ohm

## Conclusiones rápidas
En la salida tenemos entre 0 y 65mA

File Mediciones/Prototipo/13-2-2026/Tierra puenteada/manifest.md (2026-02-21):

# Run: 13/2/2026

## Objetivo
Obtener una medicion del comportamiento actual, de chequear si es correcto

## Parámetros
Celda 12, soldada
Celda 11 y banco 1 aun no están soldados por completo
No está el mosfet de tierra conectado, estamos puenteando la tierra, en el encendido y apagado la celda esta con el terminal negativo a tierra.
Rl = 47 ohm

## Conclusiones rápidas
En la salida tenemos entre 0 y 65mA

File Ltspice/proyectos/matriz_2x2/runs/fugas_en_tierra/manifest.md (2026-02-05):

# Run: 02-02-2026 — prueba de resistencias

## Objetivo
Ver como el valor de la resistencia en tierra
 afecta a la corriente en la celda y a la tension de salida

## Esquemático base
version1.9.asc

## Parámetros
Rg= [1, 2.2, 4.7, 10]
RL=1k

## Conclusiones rápidas

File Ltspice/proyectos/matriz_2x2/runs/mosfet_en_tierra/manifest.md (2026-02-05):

# Run: 02-04-2026 — prueba de mosfet

## Objetivo
Ver si al poner el mosfet el circuito funciona mejor

## Esquemático base
version2.6.asc

## Parámetros
RL=10

## Conclusiones rápidas
En config MAS-MAS, no se ven diferencias
En config MAS-MENOS, cuando se enciende el segundo banco no se llega a la tensión deseada.

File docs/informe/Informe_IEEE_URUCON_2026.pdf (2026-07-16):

## Diseño de una plataforma experimental para ecualización activa de celdas de litio

Sebastián Ezequiel García, Denise Oriana Viltes

La creciente demanda energética actual requiere de más y mejores formas de almacenar energía. Las baterías de litio como Li-Ion, Li-Po, LiFePO4, etc, demostraron ser una forma eficiente de almacenamiento. Una batería está formada por un grupo de celdas, las cuales a modo de ensamble serie-paralelo cumplen con los requerimientos de tensión y corriente. Debido a variaciones en las condiciones de fabricación, una batería contiene celdas con diferentes capacidades [1], coeficientes térmicos, resistencias internas, etc. Estas diferencias provocan desbalances de SoC (State of Charge) entre las celdas, provocando sobrecalentamiento, riesgo de cortocircuitos por formación de filamentos de litio metálico, reducción en la vida útil y disminución de la eficiencia de almacenaje [2].
Para mitigar estas complicaciones, mantener las condiciones seguras de operación y así prolongar la vida útil de las baterías, resulta esencial distribuir la carga de forma equilibrada o ecualizar la carga entre celdas, y contar con una arquitectura que permita aislar rápidamente cualquier celda disfuncional.
Los métodos de ecualización pueden clasificarse en métodos pasivos y métodos activos. Los primeros son los más utilizados por su simplicidad y bajo costo. Estos equilibran la energía de las celdas disipando el exceso de energía entre ellas. Los segundos son más complejos y costosos. Una estrategia posible es redistribuir la energía eléctrica mediante circuitos apropiados [3]. Otra alternativa es utilizar un bypass con el cual se distribuye la energía reconfigurando el camino de la corriente. Esto se obtiene mediante una matriz circuital reconfigurable y activada digitalmente que es capaz de aislar celdas individuales, permitiendo distintas conexiones [4].
En este trabajo se diseñó una plataforma experimental usando una topología de matriz reconfigurable de celdas LiFePO4 de capacidad nominal 1,5 A h. Se parte del circuito propuesto en [5] e implementa una plataforma de ecualización activa mediante el método de bypass. Se denomina celda a la unidad de almacenamiento electroquímico, asociada a un switch que permite habilitarla o deshabilitarla. Un conjunto de celdas conectadas en paralelo forma un banco, provisto de un switch de bypass para garantizar la continuidad del sistema. Finalmente, los bancos se conectan en serie para conformar la “batería”.

1
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

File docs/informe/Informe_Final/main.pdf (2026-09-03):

# Diseño de una plataforma experimental de ecualización activa de celdas de litio

### Integrantes

## Sebastián Ezequiel García

Padrón: 103780
sebgarcia@.uba.ar

## Denise Oriana Viltes

Padrón: 106943
dviltes@.uba.ar

### Tutora

## Dra. Cecilia G. Galarza

cgalar@.uba.ar

### Cotutor

## Ing. Juan Zuloaga

jzuloaga@.uba.ar

Trabajo Profesional de Ingeniería Electrónica | Año 2026

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

Trabajo Profesional de Ingeniería Electrónica | UBA - Facultad de Ingeniería

## 1. Marco teórico

En la actualidad, con la creciente demanda energética, sumado a la reducción progresiva de la generación de electricidad mediante combustibles fósiles, son necesarias más y mejores forma de almacenar energía eléctrica. Las baterías de litio recargables como Li-Ion, Li-Po, LiFePO4, etc, demostraron ser una forma eciente de almacenamiento.
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

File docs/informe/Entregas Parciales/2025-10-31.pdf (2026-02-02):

# Informe 31/10/2025

### Integrantes

## Sebastián Ezequiel García

Padrón: 103780
sebgarcia@fi.uba.ar

## Denise Oriana Viltes

Padrón: 106943
dviltes@fi.uba.ar

### Tutora

## Dra. Cecilia G. Galarza

cgalar@fi.uba.ar

### Cotutor

## Ing. Juan Zuloaga

jzuloaga@fi.uba.ar

Propuesta de Trabajo Profesional de Ingeniería | Año 2025
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

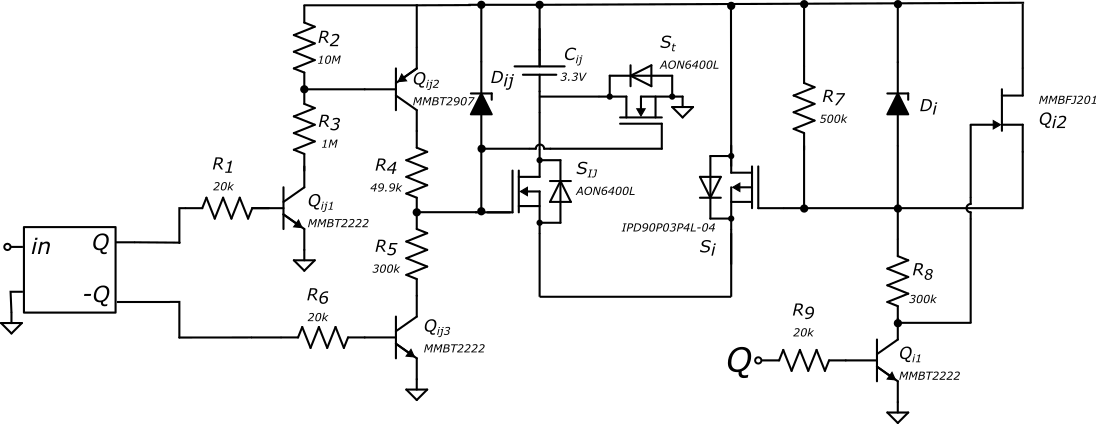
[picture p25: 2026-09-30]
media/Latex/Diseño del circuito/Circuito - Con mosfet en la tierra.png

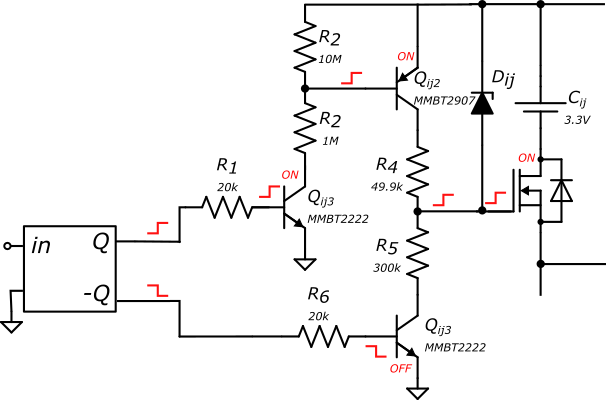
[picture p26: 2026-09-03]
media/Latex/Diseño del circuito/Circuito - Celda Encendida.png

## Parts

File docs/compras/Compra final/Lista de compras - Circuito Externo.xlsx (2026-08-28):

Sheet: Materiales que faltan
Componente | Cantidad necesaria (contando los que ya tenemos) | Redundancia | Total
Conectores cable plano macho 2x7 | 0 | 4 | 4
Quad-opamp TL084 | 0 | 1 | 1
~~ICL7660~~ | ~~0~~ | ~~?~~ | ~~?~~
~~Borneras para el Vcc externo~~ | ~~0~~ | ~~2 (si encontramos alguna buena)~~ | ~~?~~
Capacitores 100nF | 3 | 3 | 6
R shunt 2512 50mΩ | 1 | 1 | 2
R 1kΩ | 0 (1 del central +1 del 4to banco - 3 que tenemos) | 4 | 5
R 33kΩ | 9 (32 necesarios - 23 que tenemos) | 1 | 10
Switch ON/OFF | 1 | 1 | 2
DIP switch de 4 | 2 | 0 | 2
DIP switch de 1 | 3 | 0 | 3
Sensor de corriente (INA180) | 2 | 1 | 3
IRLB8721 (N-MOSFET de celda) | 1 | 0 | 1
MMBFJ201 (JFET para los bancos) | 2 | 1 | 3

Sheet: Hoja1
Componente | Total
Conectores cable plano macho 2x7: | 4
Quad-opamp TL084: | 1
Capacitores 100nF: | 6
R shunt 2512 50mΩ 1W: | 2
DIP switch de 4 posiciones: | 2
DIP switch de 1 posicion: | 3
Sensor de corriente (INA180): | 3
IRLB8721: | 1
MMBFJ201 : | 3

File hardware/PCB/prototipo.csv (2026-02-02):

Id | Identificador | Huella | Cantidad | Identificación | Suministrador y ref
1 | VCELL11,VCELL22,VCELL21,VCELL32,VCELL31,VCELL12 | BatteryHolder_MPD_BK-18650-PC2 | 6 | 3.3
2 | Q22_2,Q31_2,Q32_2,Q11_2,Q12_2,Q21_2 | SOT-23-3 | 6 | MMBT2907A
3 | R22_3,R21_3,R31_3,R11_3,R12_3,R32_3 | R_Axial_DIN0207_L6.3mm_D2.5mm_P7.62mm_Horizontal | 6 | 1Meg
4 | Q31_3,Q31_1,Q32_1,Q32_3,Q22_3,QLED11,Q11_3,Q12_3,QLED3,Q12_1,Q21_1,Q22_1,Q1_1,Q11_1,Q3_1,Q21_3,QLED1,QLED22,Q2_1,QLED32,QLED31,QLED2,QLED21,QLED_12 | SOT-23-3 | 24 | MMBT2222A
5 | TPB21,TPG11,TPgnd31,TPB32,TPC21,TPG2,TPG1,TPG3,TPgnd21,TPC12,TPgnd22,TPgnd11,TPC31,TPB12,TPgnd32,TPC22,TPG32,TPB22,TPB11,TPC32,TPG21,TPbanco2,TPG22,TPbanco1,TPC11,TPG12,TPB31,TPG31,TPgnd12 | TestPoint_Bridge_Pitch2.54mm_Drill1.0mm | 29 | TestPoint
6 | R21_6,RLED12_1,RLED21_1,RLED1_1,R32_1,R1_9,RLED32_1,R11_1,RLED3_1,R31_6,R22_1,RLED22_1,R32_6,R21_1,RLED11_1,R2_9,R12_1,R22_6,RLED31_1,RLED2_1,R11_6,R12_6,R3_9,R31_1 | R_Axial_DIN0207_L6.3mm_D2.5mm_P7.62mm_Horizontal | 24 | 20k
7 | D2,D1,D22,D11,D12,D32,D3,D21,D31 | D_DO-41_SOD81_P7.62mm_Horizontal | 9 | 1N4736A
8 | R1_8,R3_8,R2_8 | R_Axial_DIN0207_L6.3mm_D2.5mm_P7.62mm_Horizontal | 3 | 300K
9 | R21_5,R11_5,R22_5,R31_5,R12_5,R32_5 | R_Axial_DIN0207_L6.3mm_D2.5mm_P7.62mm_Horizontal | 6 | 33k
10 | DLED22,DLED2,DLED21,DLED31,DLED3,DLED12,DLED32,DLED11,DLED1 | LED_D5.0mm | 9 | LED
11 | RLED12_2,RLED31_2,RLED22_2,RLED21_2,RLED11_2,RLED32_2 | R_Axial_DIN0207_L6.3mm_D2.5mm_P7.62mm_Horizontal | 6 | 1k
12 | S31,S21,S22,S12,S32,S11,Sgnd21,Sgnd11 | TO-220-3_Vertical | 8 | IRLB8721
13 | R21_4,R31_4,R11_4,R32_4,R22_4,R12_4 | R_Axial_DIN0207_L6.3mm_D2.5mm_P7.62mm_Horizontal | 6 | 4.7k
14 | J1 | PinHeader_2x12_P2.54mm_Vertical | 1 | Conn_02x12_Odd_Even
15 | S1,S2,S3 | FDMS6681Z | 3 | FDMS6681Z
16 | RLED2_2,RLED1_2,RLED3_2 | R_Axial_DIN0207_L6.3mm_D2.5mm_P7.62mm_Horizontal | 3 | 1K
17 | F11,F22,F2,F3,F32,F1,F31,F21,F12 | Fuseholder_Cylinder-5x20mm_Schurter_0031_8201_Horizontal_Open | 9 | Fuse
18 | J_B4,J_B1,J_B2,Celdas_bus1,J_B3 | PinHeader_1x02_P2.54mm_Vertical | 5 | Conn_01x02_Pin
19 | Rout32,Rout21,Rout31,Rout12,Rout11,Rout22 | R_Axial_DIN0207_L6.3mm_D2.5mm_P7.62mm_Horizontal | 6 | 1m
20 | R12_2,R31_2,R32_2,R21_2,R22_2,R11_2 | R_Axial_DIN0207_L6.3mm_D2.5mm_P7.62mm_Horizontal | 6 | 10Meg
21 | Q3_2,Q1_2,Q2_2 | SOT-23-3 | 3 | MMBFJ201
22 | R2_7,R1_7,R3_7 | R_Axial_DIN0207_L6.3mm_D2.5mm_P7.62mm_Horizontal | 3 | 570K
23 | OUT1 | TerminalBlock_bornier-2_P5.08mm | 1 | Conn_01x02_Socket
24 | Celdas_sup1,Celdas_inf1 | PinHeader_1x03_P2.54mm_Vertical | 2 | Conn_01x03_Pin
25 | A1 | DIP-14_W7.62mm_LongPads | 1 | ~

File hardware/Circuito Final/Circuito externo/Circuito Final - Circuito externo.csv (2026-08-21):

Reference | Qty | Value | DNP | Exclude from BOM | Exclude from Board | Footprint | Datasheet
Bornera1,Bornera2 | 2 | Conn_01x02_Socket |  |  |  | Huellas:TerminalBlock_bornier-2_P5.08mm
C1,C2,C3 | 3 | 10u |  |  |  | Capacitor_SMD:C_1206_3216Metric_Pad1.33x1.80mm_HandSolder
C5,C6,C7,C8 | 4 | 100n |  |  |  | Capacitor_SMD:C_1206_3216Metric_Pad1.33x1.80mm_HandSolder
J1,J2 | 2 | Conn_02x19_Odd_Even |  |  |  | Connector_PinSocket_2.54mm:PinSocket_2x19_P2.54mm_Vertical
J3,J4 | 2 | Conn_01x02 |  |  |  | Connector_PinSocket_2.54mm:PinSocket_1x02_P2.54mm_Vertical
J5 | 1 | Conn_01x03_Pin |  |  |  | Connector_PinHeader_2.54mm:PinHeader_1x03_P2.54mm_Vertical
Jsalida_1,Jsalida_2,Jsalida_3,Jsalida_4 | 4 | Conn_02x07_Odd_Even |  |  |  | Connector_IDC:IDC-Header_2x07_P2.54mm_Horizontal
Q1,Q2 | 2 | FDMS6681Z |  |  |  | Huellas:FDMS6681Z | https://www.onsemi.com/pub/Collateral/FDMS6681Z-D.PDF
Q3 | 1 | MMBT2222A |  |  |  | Package_TO_SOT_SMD:SOT-23 | https://assets.nexperia.com/documents/data-sheet/MMBT2222A.pdf
R1,R5,R6 | 3 | 10k |  |  |  | Resistor_SMD:R_1206_3216Metric_Pad1.30x1.75mm_HandSolder
R2 | 1 | 1m |  |  |  | Resistor_SMD:R_2512_6332Metric_Pad1.40x3.35mm_HandSolder
R3 | 1 | 22k |  |  |  | Resistor_SMD:R_1206_3216Metric_Pad1.30x1.75mm_HandSolder
R4 | 1 | 1k |  |  |  | Resistor_SMD:R_1206_3216Metric_Pad1.30x1.75mm_HandSolder
R11,R12,R21,R22,R31,R32,R41,R42 | 8 | 39k |  |  |  | Resistor_SMD:R_1206_3216Metric_Pad1.30x1.75mm_HandSolder
R33,R34,R35,R36,R37,R38,R39,R40,R43,R44,R45,R46,R47,R48 | 14 | 0 |  |  |  | Resistor_SMD:R_1206_3216Metric_Pad1.30x1.75mm_HandSolder
Rf1,Rf2,Rf3,Rf4,Rx1,Rx2,Rx3,Rx4 | 8 | 33k |  |  |  | Resistor_SMD:R_1206_3216Metric_Pad1.30x1.75mm_HandSolder
SW1 | 1 | SW_SPDT |  |  |  | Button_Switch_THT:SW_Slide_SPDT_Straight_CK_OS102011MS2Q
SW2,SW3 | 2 | SW_DIP_x04 |  |  |  | Button_Switch_THT:SW_DIP_SPSTx04_Slide_6.7x11.72mm_W7.62mm_P2.54mm_LowProfile
SW4,SW5,SW6 | 3 | SW_DIP_x01 |  |  |  | Button_Switch_THT:SW_DIP_SPSTx01_Slide_9.78x4.72mm_W7.62mm_P2.54mm
TP1,TP2 | 2 | TestPoint |  |  |  | TestPoint:TestPoint_Keystone_5005-5009_Compact
U1 | 1 | Opamp_Quad |  |  |  | Package_SO:SO-14_3.9x8.65mm_P1.27mm
U2 | 1 | ICL7660 |  |  |  | Package_SO:SOIC-8_3.9x4.9mm_P1.27mm | http://datasheets.maximintegrated.com/en/ds/ICL7660-MAX1044.pdf
U3 | 1 | INA180A1 |  |  |  | Package_TO_SOT_SMD:SOT-23-5 | http://www.ti.com/lit/ds/symlink/ina180.pdf

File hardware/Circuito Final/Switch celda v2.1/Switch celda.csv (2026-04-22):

Reference | Qty | Value | DNP | Exclude from BOM | Exclude from Board | Footprint | Datasheet
Celda1 | 1 | Portapilas 18650
DLED1 | 1 | LED
F1 | 1 | ~
Jumper1 | 1 | Conn_01x03_Pin
Jumper_cell_neg_1,Jumper_Vcell_1,J_In_cell_neg_1 | 3 | Conn_02x07_Odd_Even
J_In_Out_1 | 1 | Conn_02x06_Odd_Even
J_In_Vcell_1 | 1 | Conn_01x07_Socket
Q1,Q3,QLED1 | 3 | MMBT2222A
Q2 | 1 |  |  |  |  | MMBT2907A | 10
Qinv1 | 1 | AO3401 |  |  |  | 20k | 5
Qinv2 | 1 | AO3400 |  |  |  | 4.7k | 5
R1,R6,RLED1 | 3 |  |  |  |  | 33k | 5
R2,R3 | 2 | TBD |  |  |  | 1k | 5
R4 | 1 |  |  |  |  | 10k | 5
R5 | 1 |  |  |  |  | 1Meg | 5
RLED2 | 1 |  |  |  |  | 10Meg | 5
S1,S2 | 2 | IRLB8721
TP1 | 1 | TP_base
TP2 | 1 | TP_gate
TP3 | 1 | TP_inv
TPgnd1,TPgnd2 | 2 | TP_gnd

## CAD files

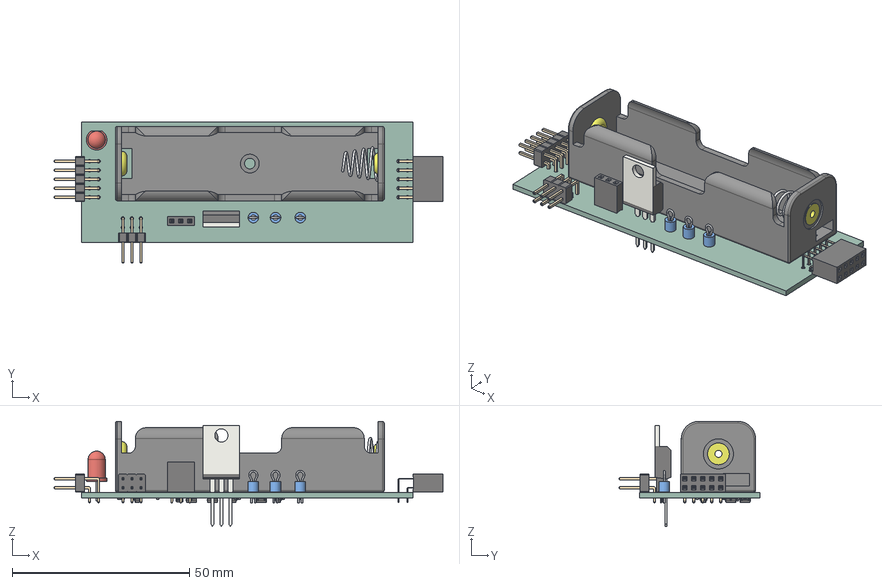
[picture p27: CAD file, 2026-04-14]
hardware/Circuito Final/Ideas/Switch celda - Trencito con mux/Switch celda.step
109.8 x 39.8 x 29.8 mm
PinSocket_1x03_P2.54mm_Vertical
TestPoint_Loop_D2.54mm_Drill1.5mm_Beaded x 3
PinHeader_2x05_P2.54mm_Horizontal
PinHeader_2x03_P2.54mm_Horizontal
LED_D5.0mm
PinSocket_2x05_P2.54mm_Horizontal
Portapilas 18650
TO-220-3_Vertical
R_0603_1608Metric x 8
SOT-23 x 6
Fuse_0603_1608Metric
SOT-363_SC-70-6
Switch celda_PCB

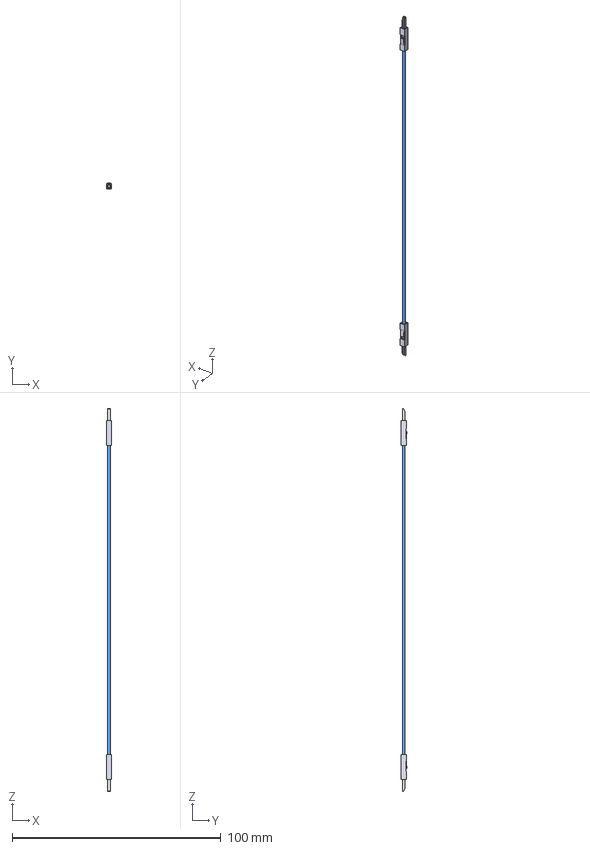
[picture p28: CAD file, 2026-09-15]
hardware/PCB/Modelos 3D/Dupont azul macho-macho.step
2.54 x 2.79 x 183.6 mm
DS1071-1x1 x 2

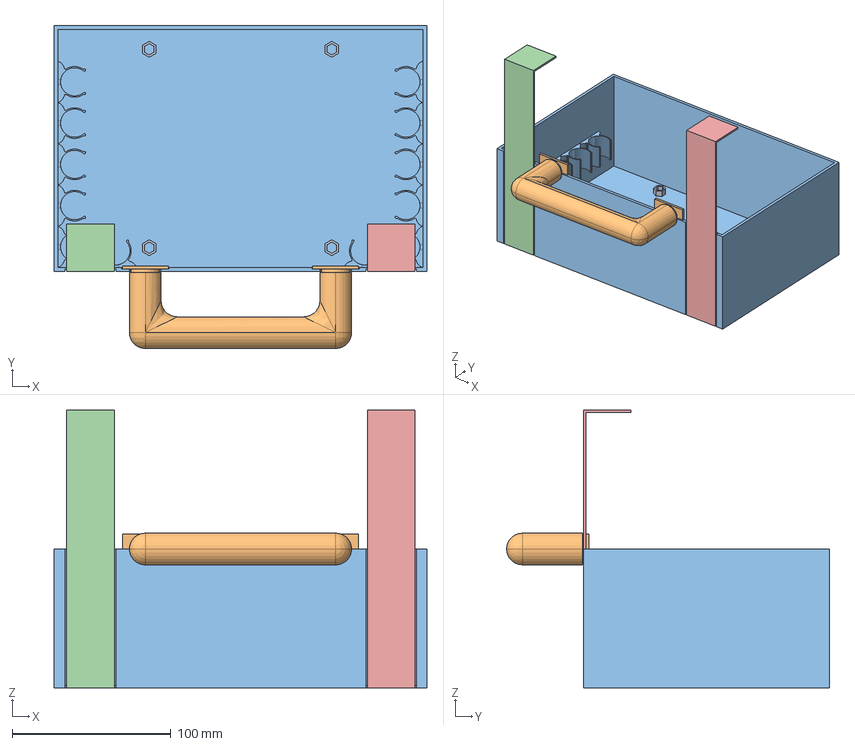
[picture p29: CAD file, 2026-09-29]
Soporte 3D/Cajita.FCStd
235.0 x 203.5 x 175.0 mm
Tuercas
Manija
Traba Izquierda
Traba Derecha

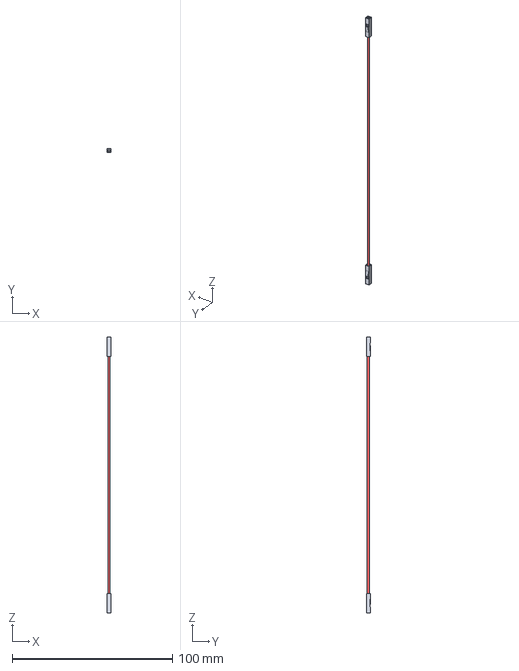
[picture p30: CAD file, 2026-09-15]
hardware/PCB/Modelos 3D/Dupont rojo hembra-hembra.step
2.54 x 2.79 x 172.0 mm
DS1071-1x1 x 2

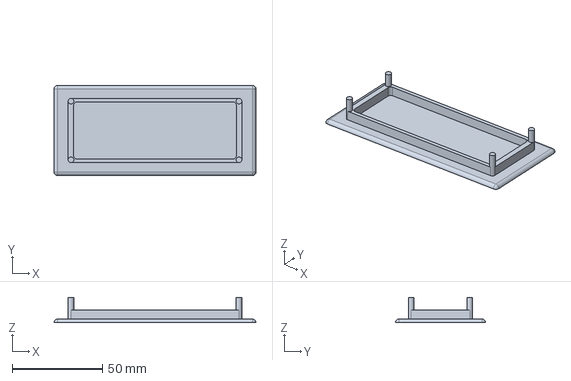
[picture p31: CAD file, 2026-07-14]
Soporte 3D/base.FCStd
112.0 x 50.0 x 14.0 mm

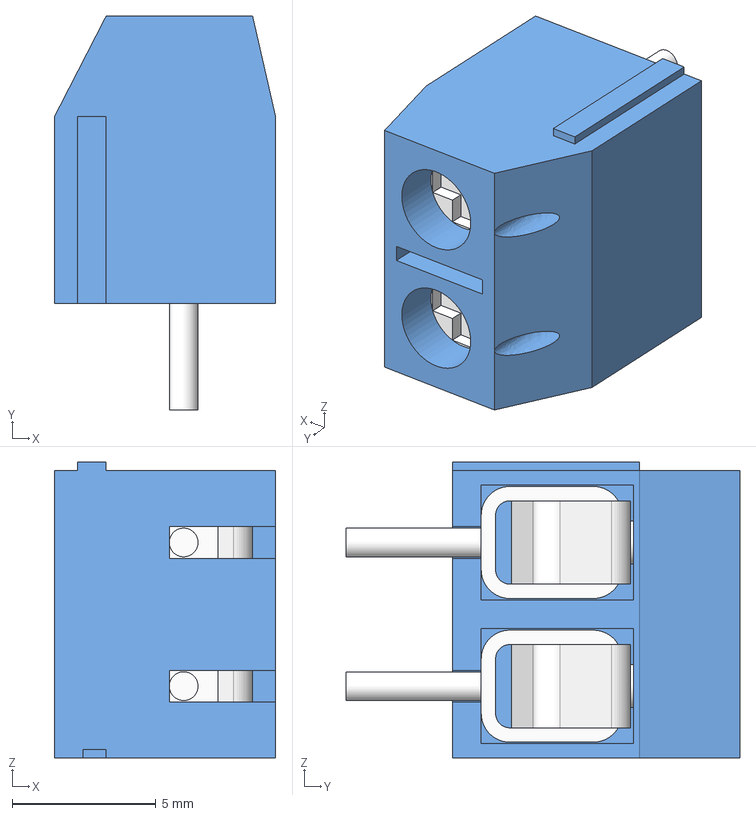
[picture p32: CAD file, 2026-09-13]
hardware/PCB/Modelos 3D/Bornera 2x1.stp
7.70 x 13.7 x 10.3 mm

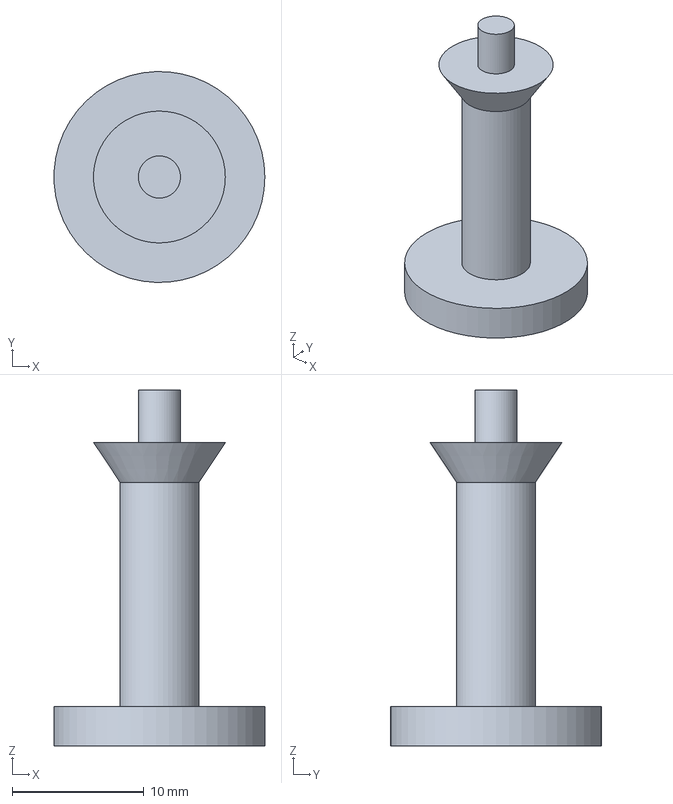
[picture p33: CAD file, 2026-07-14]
Soporte 3D/palito soporte.FCStd
16.0 x 16.0 x 27.0 mm

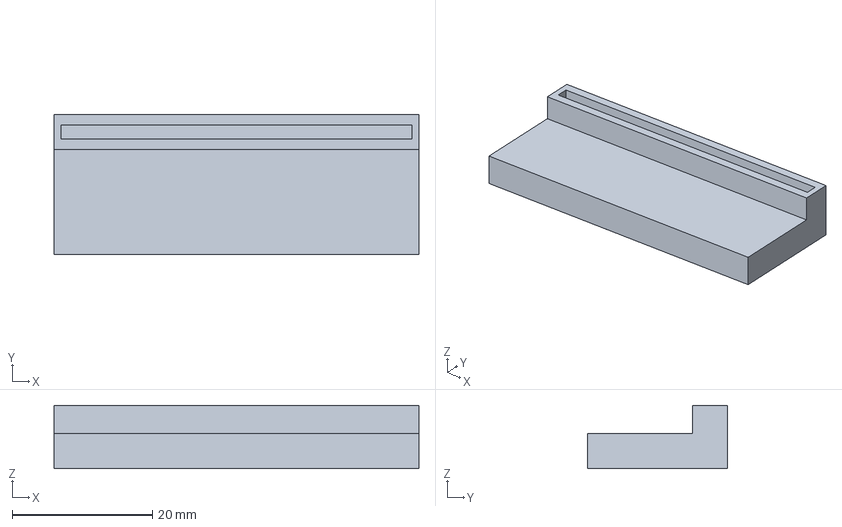
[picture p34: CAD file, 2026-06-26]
Soporte 3D/medio cosito.FCStd
52.0 x 20.0 x 9.00 mm

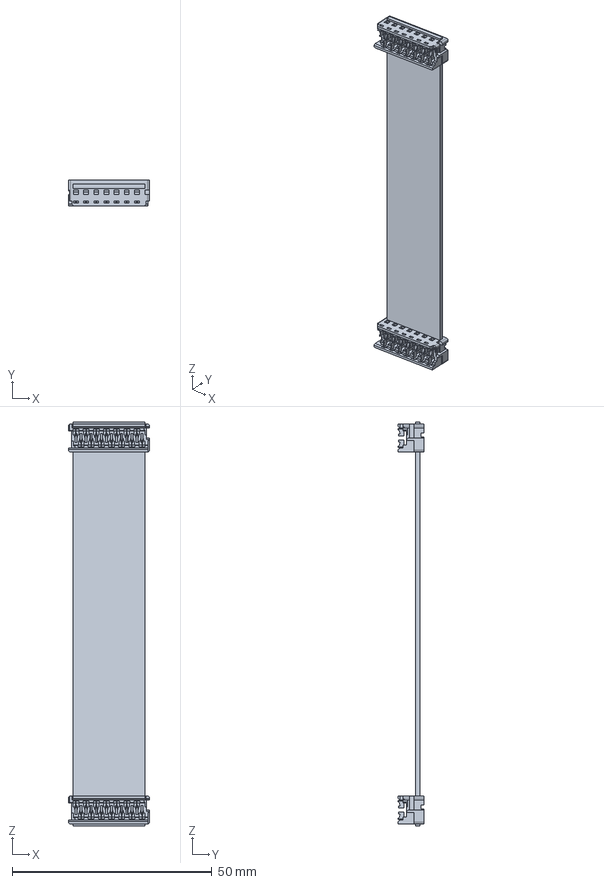
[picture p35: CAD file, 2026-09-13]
hardware/PCB/Modelos 3D/Cable plano 2x7.stp
20.3 x 6.40 x 101.0 mm

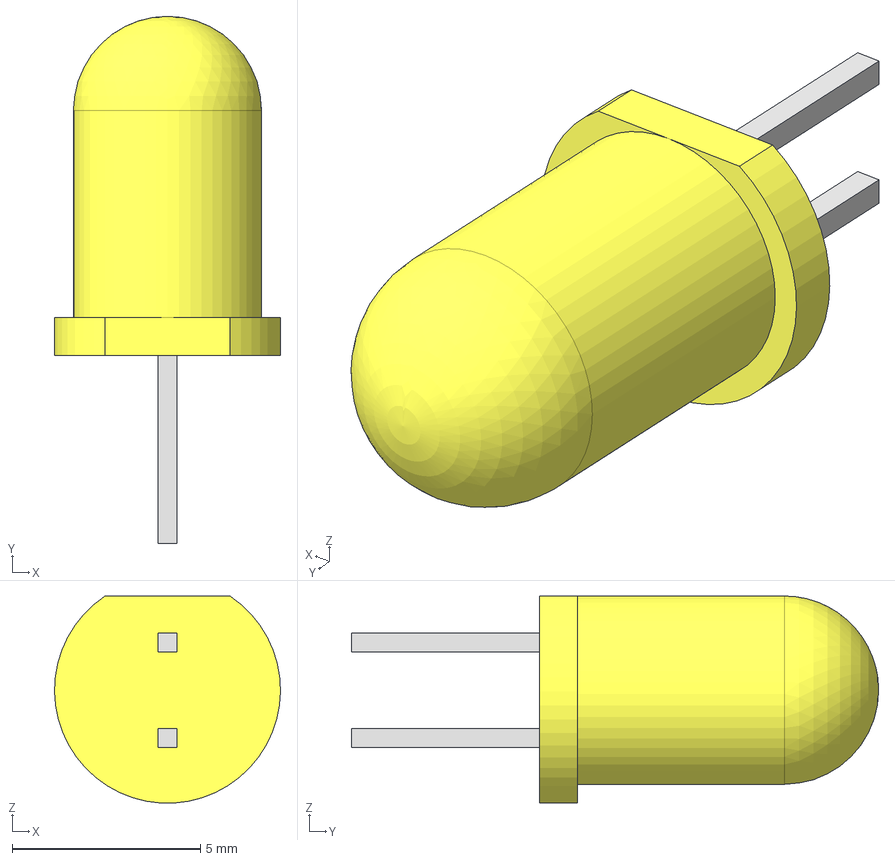
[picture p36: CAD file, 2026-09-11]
hardware/PCB/Modelos 3D/LED 5mm amarillo.stp
6.00 x 14.0 x 5.49 mm

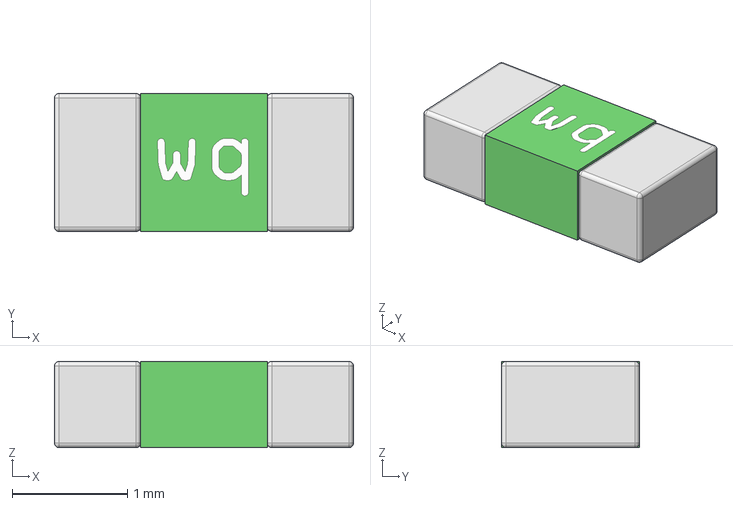
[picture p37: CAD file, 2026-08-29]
hardware/PCB/Modelos 3D/Fusible SMD 0805.stp
2.60 x 1.20 x 0.751 mm

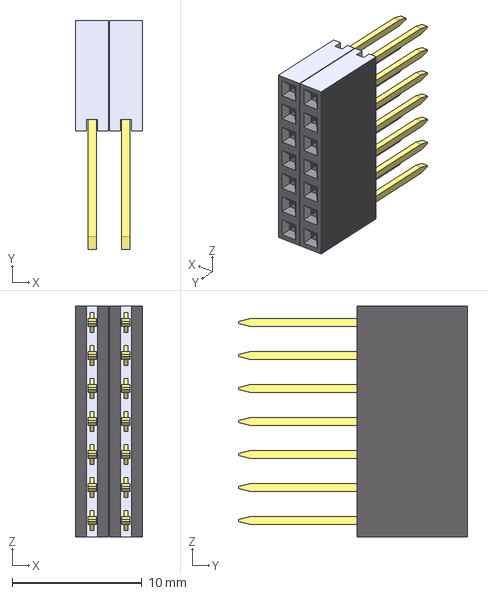
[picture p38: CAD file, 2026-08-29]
hardware/PCB/Modelos 3D/Pin hembra largo 2x7.step
5.14 x 17.6 x 17.8 mm
1x001
1x7

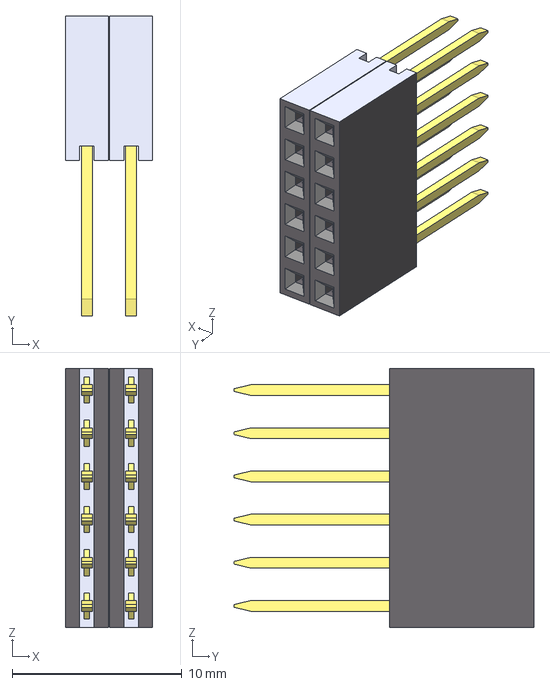
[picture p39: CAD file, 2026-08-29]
hardware/PCB/Modelos 3D/Pin hembra largo 2x6.STEP
5.14 x 17.6 x 15.2 mm
1x001
1x6

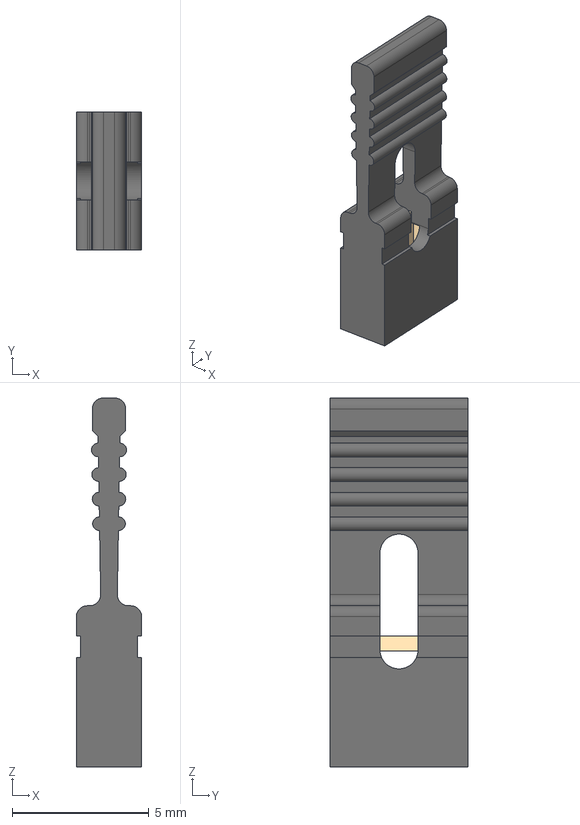
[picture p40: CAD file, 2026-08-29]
hardware/PCB/Modelos 3D/Jumper.stp
2.39 x 5.05 x 13.5 mm

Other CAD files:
hardware/PCB/Modelos 3D/Celda 18650.stp
hardware/PCB/Modelos 3D/Pin hembra largo 1x6.STEP
hardware/PCB/Modelos 3D/Pin hembra largo 1x7.STEP
hardware/PCB/Modelos 3D/Pin hembra largo 1x4.STEP
Soporte 3D/base.3mf
Soporte 3D/baseV1.3mf
Soporte 3D/palito soporte.3mf
hardware/PCB/Modelos 3D/FDMS6681Z.step
hardware/PCB/Modelos 3D/FDMS6681Z.stp
hardware/PCB/Modelos 3D/Portafusible.stp
hardware/PCB/Modelos 3D/Portapilas 18650.STEP

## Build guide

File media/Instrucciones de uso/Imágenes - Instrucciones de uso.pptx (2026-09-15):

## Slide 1

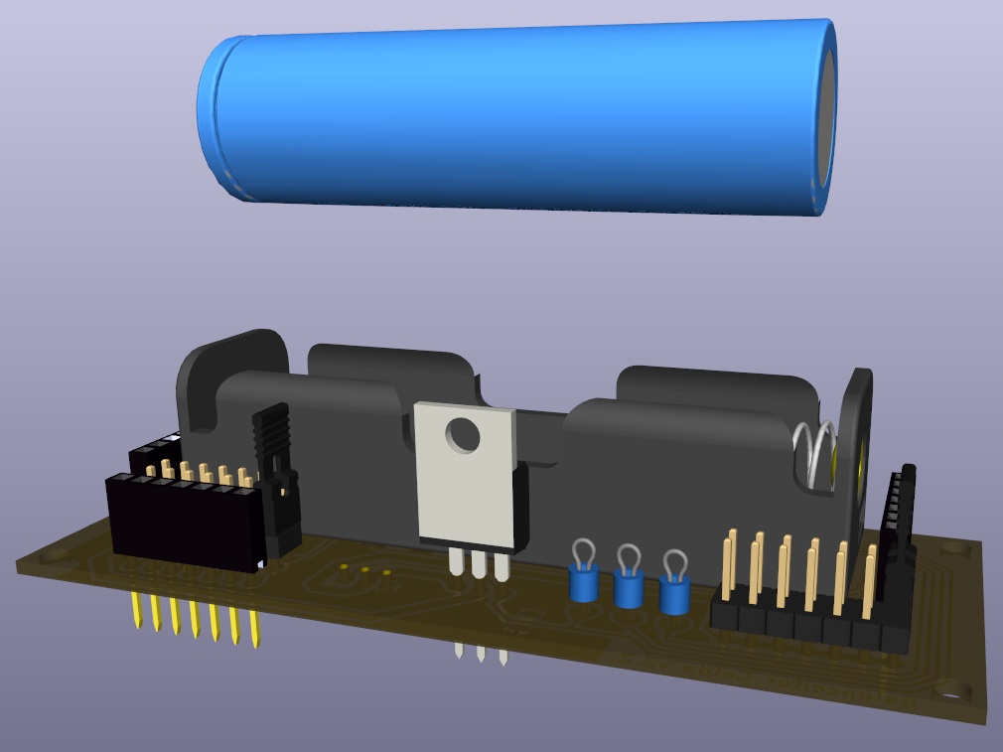
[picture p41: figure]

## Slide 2

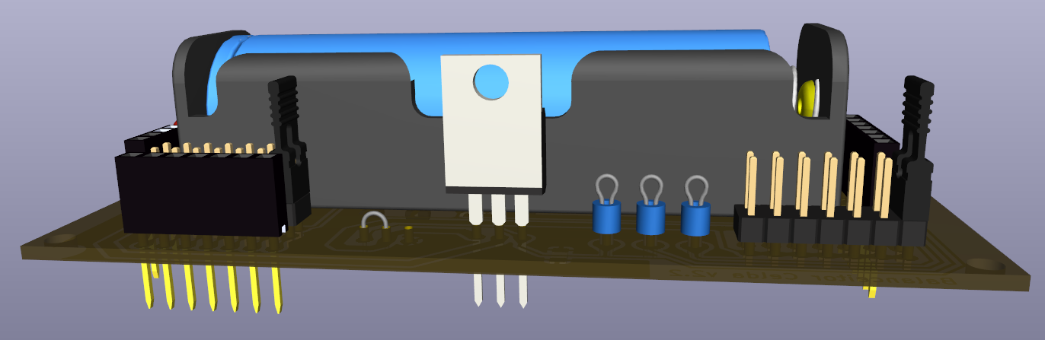
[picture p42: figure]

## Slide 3

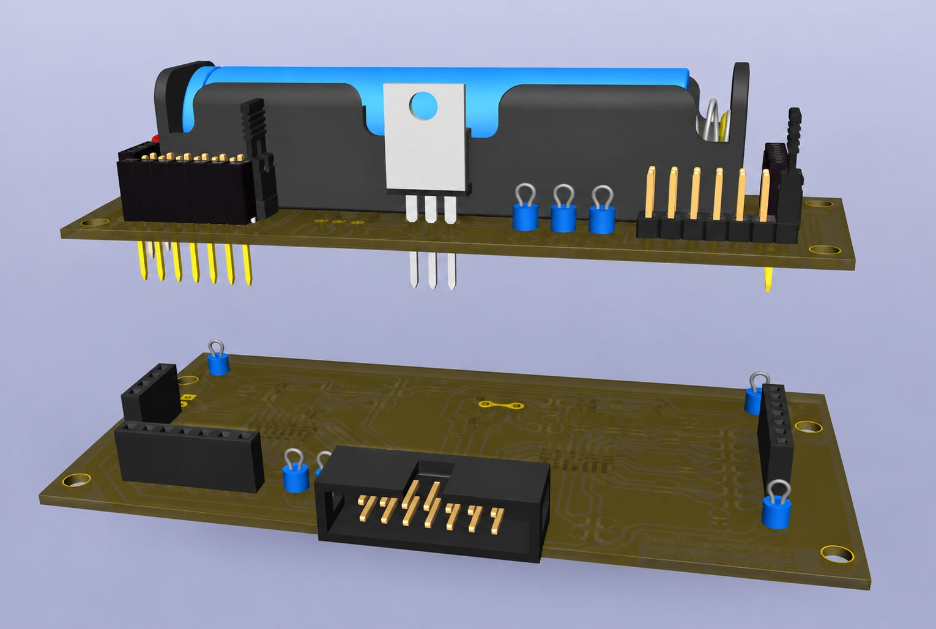
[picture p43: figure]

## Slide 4

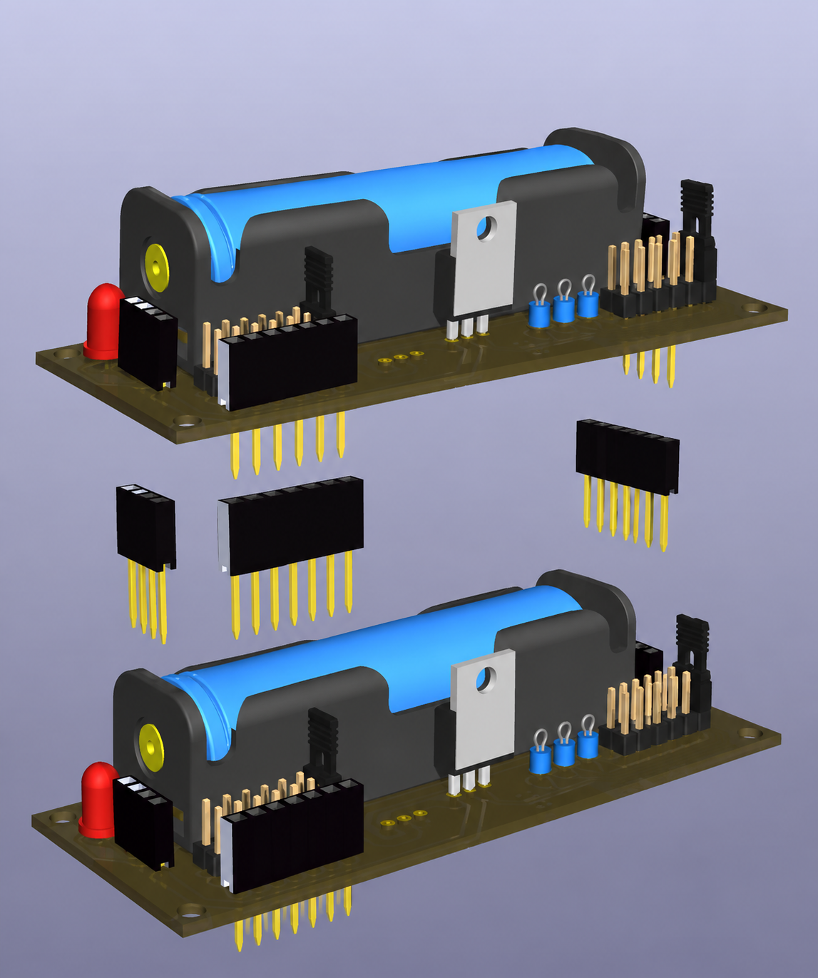
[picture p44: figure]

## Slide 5

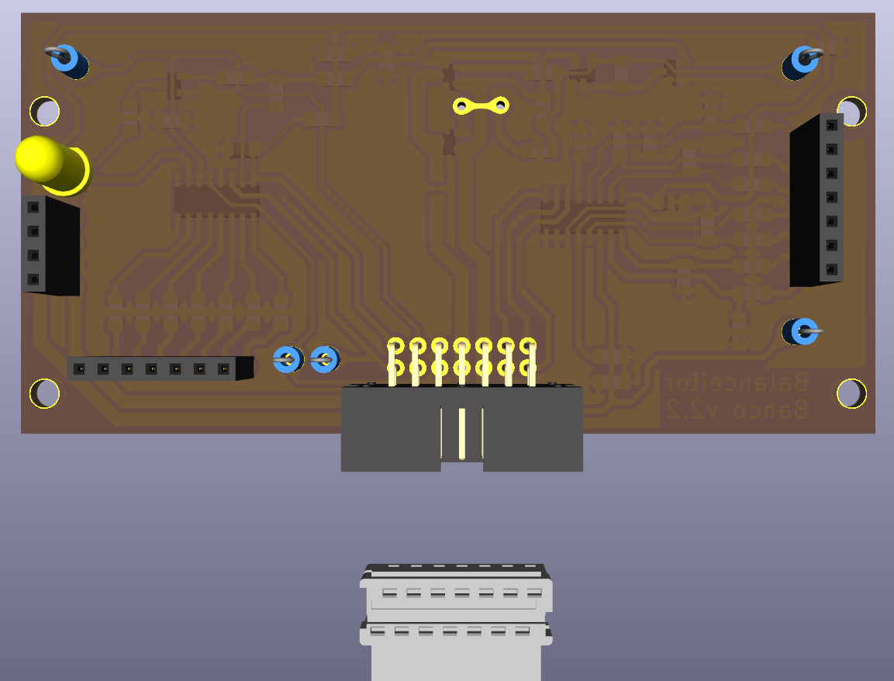
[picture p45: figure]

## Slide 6

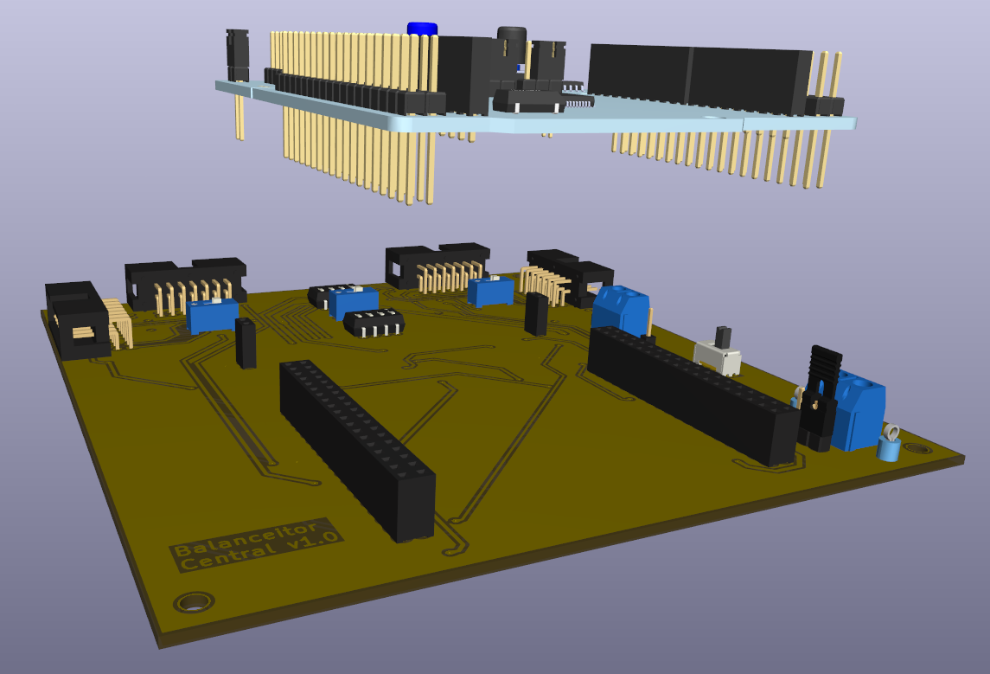
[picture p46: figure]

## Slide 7

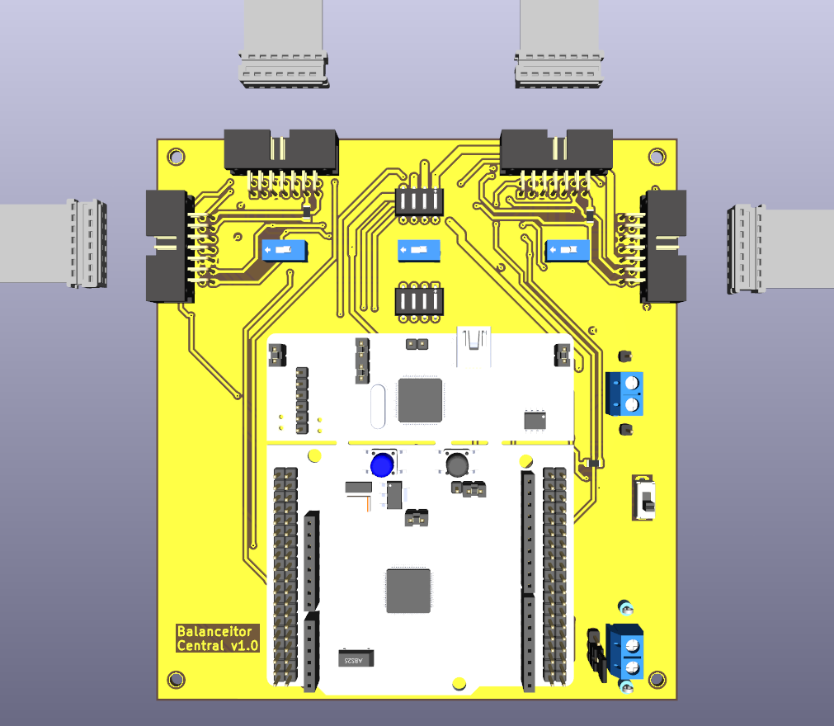
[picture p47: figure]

Banco 2

Banco 3

DIP switch
salida +

Banco 1

Banco 4

DIP switch
1 - 2

DIP switch
3 - 4

DIP switch
salida -

DIP switch
2 - 3

Salida

Switch
ON/OFF

Entrada Vcc

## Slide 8

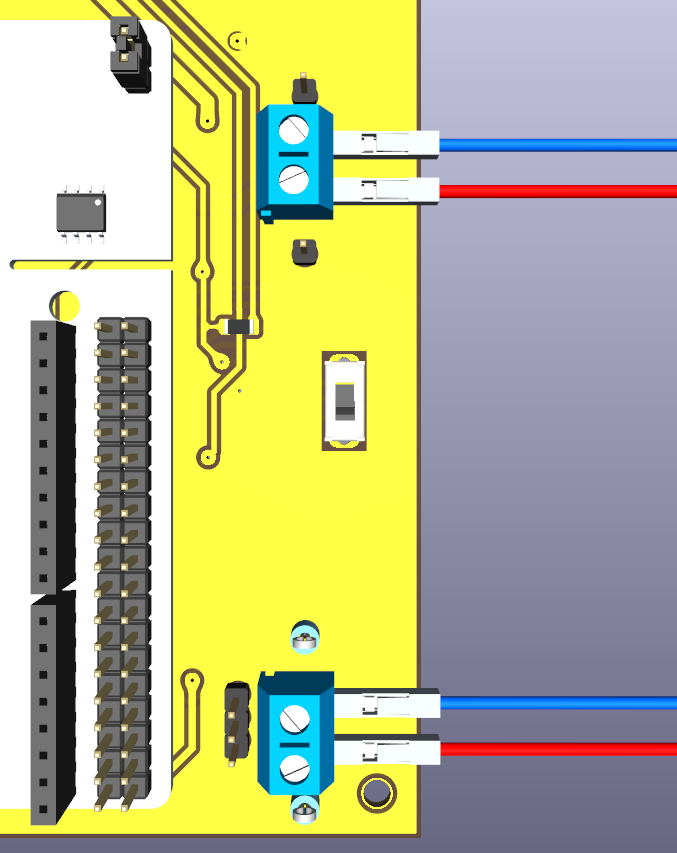
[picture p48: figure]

Salida -

Salida +

Entrada Vcc -

Entrada Vcc +

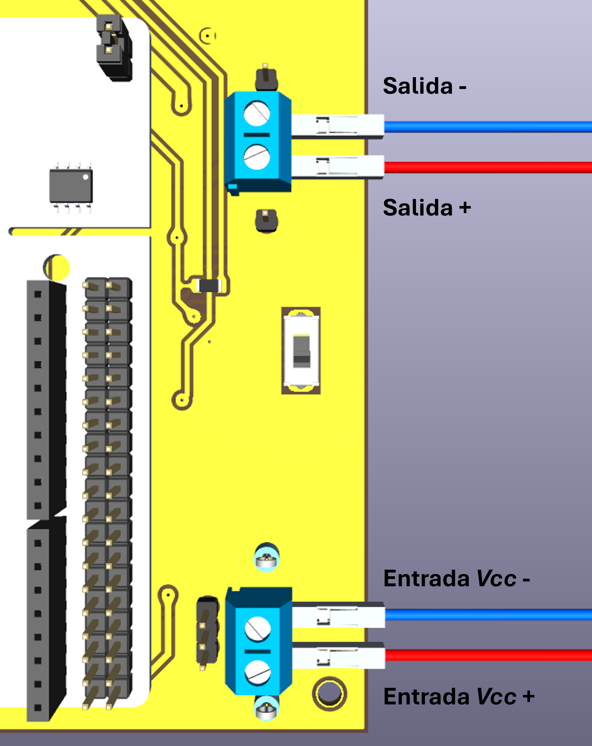
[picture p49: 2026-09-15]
media/Instrucciones de uso/Manual - Entradas y salidas.png

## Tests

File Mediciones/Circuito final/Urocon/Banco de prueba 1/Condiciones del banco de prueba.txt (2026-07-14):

Matriz de 2x1
Ambas celdas en 3.2V 
Módulo de banco + celda con mosfet como banco 1
Módulo de celda sin mosfet siempre encendida como banco 2 (banco virtual).

Frecuencia de 200 ms ->5hz
Resistencia de carga 47ohm

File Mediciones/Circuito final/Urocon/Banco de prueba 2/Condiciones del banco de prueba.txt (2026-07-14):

Matriz de 2x1.5
Ambas celdas del banco 2 en 3.2V (fuente)
1 celda de banco 1 (celda de verdad) ~3.23V
Módulo de banco + 2 celdas sin mosfet como banco 2
Módulo de celda con mosfet siempre encendida como banco 1 (banco virtual).

Frecuencia de 100 ms ->5hz
Resistencia de carga 47ohm

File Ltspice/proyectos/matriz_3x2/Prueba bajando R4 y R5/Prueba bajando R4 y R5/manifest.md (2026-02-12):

# Run: 06-02-2026 — prueba de celda 2

Ver si funciona la celda 2 del banco 1 en el pcb

## Esquemático base

version3.3.asc

## Parámetros

R11=10k (antes 10M)

R12=1k (antes 1M)

## Conclusiones rápidas

-Se conecta la rama del npn de on, Q12\_1, OK

-Se conecta la rama del pnp Q11\_3 y npn de off Q12\_3, OK

-Driver funciona OK

\_\_\_\_\_\_\_

-Se conecta el mosfet, el driver da bien, no esta cerrada la malla de potencia

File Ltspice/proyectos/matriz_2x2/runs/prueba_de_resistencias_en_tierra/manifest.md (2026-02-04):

# Run: 02-02-2026 — prueba de resistencias

## Objetivo
Ver como el valor de la resistencia en tierra
 afecta a la corriente en la celda y a la tension de salida

## Esquemático base
version2.0.asc

## Parámetros
Rg= [1k, 100k, 500k]
RL=1k

## Conclusiones rápidas

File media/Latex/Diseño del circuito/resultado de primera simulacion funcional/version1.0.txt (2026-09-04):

time	V(n001)	I(Cij)
0.000000000000000e+00	3.199983e+00	-3.199996e-03
9.999999939225290e-09	3.199982e+00	-3.208642e-03
1.015624993827569e-08	3.199982e+00	-3.208714e-03
1.109374993257806e-08	3.199982e+00	-3.209163e-03
1.205420372069988e-08	3.199982e+00	-3.209636e-03
1.310996458247755e-08	3.199982e+00	-3.210140e-03
1.487783036437070e-08	3.199982e+00	-3.210853e-03
1.830000762896943e-08	3.199982e+00	-3.211424e-03
2.165404897443914e-08	3.199982e+00	-3.210816e-03
2.437820597374223e-08	3.199982e+00	-3.209684e-03
2.669237572553164e-08	3.199982e+00	-3.208628e-03
2.923701626099428e-08	3.199983e+00	-3.207780e-03
3.228652622328083e-08	3.199983e+00	-3.207578e-03
3.558385051233418e-08	3.199983e+00	-3.208402e-03
3.807496801960970e-08	3.199982e+00	-3.209491e-03
4.050462255839289e-08	3.199982e+00	-3.210546e-03
4.344489616337075e-08	3.199982e+00	-3.211312e-03
4.662455490049445e-08	3.199982e+00	-3.211174e-03
5.094483471527908e-08	3.199982e+00	-3.209702e-03
5.363106801955986e-08	3.199983e+00	-3.208533e-03
5.614349997761065e-08	3.199983e+00	-3.207775e-03
5.931126605043356e-08	3.199983e+00	-3.207679e-03
6.266553322608105e-08	3.199983e+00	-3.208600e-03
6.511088677180122e-08	3.199982e+00	-3.209661e-03
6.758807413061275e-08	3.199982e+00	-3.210662e-03
7.068922327983915e-08	3.199982e+00	-3.211298e-03
7.393441503380567e-08	3.199982e+00	-3.210961e-03
7.785703426875851e-08	3.199982e+00	-3.209541e-03
8.056942420707633e-08	3.199983e+00	-3.208420e-03
8.321278127538955e-08	3.199983e+00	-3.207735e-03
8.635666933204827e-08	3.199983e+00	-3.207787e-03
9.004733521992609e-08	3.199982e+00	-3.208906e-03
9.243861464763889e-08	3.199982e+00	-3.209929e-03
9.497763951399729e-08	3.199982e+00	-3.210832e-03
9.837973343208989e-08	3.199982e+00	-3.211229e-03
1.017722954822427e-07	3.199982e+00	-3.210557e-03
1.044874274125567e-07	3.199982e+00	-3.209487e-03
1.068885393057292e-07	3.199983e+00	-3.208509e-03
1.096219973103680e-07	3.199983e+00	-3.207787e-03
1.127645309777396e-07	3.199983e+00	-3.207796e-03
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

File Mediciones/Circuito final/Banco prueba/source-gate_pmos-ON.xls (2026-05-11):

Save Time: | 2026-05-11 12:26:14
 | CH1 | CH2
Frequency: | ? | ?
Period: | ? | ?
SP: | 50.000 uS | 50.000 uS
PK-PK: | 680.000 mV | 2.600 V
Units:(mV)
1 | -680 | -640
2 | -680 | -640
3 | -40 | -640
4 | -680 | 0
5 | -680 | -640
6 | -680 | -640
7 | -40 | -640
8 | -680 | 0
9 | -680 | -640
10 | -680 | -640
11 | -40 | -640
12 | -680 | 0
13 | -680 | -640
14 | -680 | -640
15 | -40 | -640
16 | -680 | 0
17 | -680 | -640
18 | -680 | -640
19 | -40 | -640
20 | -680 | 0
21 | -680 | -640
22 | -680 | -640
23 | -40 | -640
24 | -680 | 0
25 | -680 | -640
26 | -680 | -640
27 | -40 | -640
28 | -680 | 0
29 | -680 | -640
30 | -680 | -640
31 | -40 | -640
32 | -680 | 0
33 | -680 | -640
34 | -680 | -640
35 | -40 | -640
36 | -680 | 0
37 | -680 | -640
38 | -680 | -640
39 | -40 | -640
40 | -680 | 0
41 | -680 | -640
42 | -680 | -640
43 | -40 | -640
44 | -680 | 0
45 | -680 | -640
46 | -680 | -640
47 | -40 | -640
48 | -680 | 0
49 | -680 | -640
50 | -680 | -640
51 | -40 | -640
52 | -680 | 0
53 | -680 | -640
54 | -680 | -640
55 | -40 | -640
56 | -680 | 0
57 | -680 | -640
58 | -680 | -640
59 | -40 | -640
60 | -680 | 0
61 | -680 | -640
62 | -680 | -640
63 | -40 | -640
64 | -680 | 0
65 | -680 | -640
66 | -680 | -640
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

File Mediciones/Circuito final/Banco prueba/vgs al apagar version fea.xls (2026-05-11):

Save Time: | 2026-05-11 12:51:10
 |  | CH1 | CH2
Frequency: |  | ? | 30.812 Hz
Period: |  | ? | 32.455 mS
SP: |  | 500.000 uS | 500.000 uS
PK-PK: |  | 3.720 V | 4.560 V
Units:(mV)
1 | 500.000us | 3000 | 920
2 | 1000.000us | 3040 | 1000
3 | 1500.000us | 2960 | 920
4 | 2000.000us | 3000 | 960
5 | 2500.000us | 3000 | 920
6 | 3000.000us | 3040 | 960
7 | 3500.000us | 3000 | 920
8 | 4000.000us | 3000 | 920
9 | 4500.000us | 3040 | 960
10 | 5000.000us | 3160 | 1000
11 | 5500.000us | 3040 | 920
12 | 6000.000us | 3160 | 1000
13 | 6500.000us | 3200 | 1080
14 | 7000.000us | 3520 | 1120
15 | 7500.000us | 3200 | 1000
16 | 8000.000us | 3520 | 1080
17 | 8500.000us | 3480 | 1120
18 | 9000.000us | 3520 | 1120
19 | 9500.000us | 3440 | 1040
20 | 10000.000us | 3440 | 1040
21 | 10500.000us | 3400 | 1040
22 | 11000.000us | 3400 | 1080
23 | 11500.000us | 3080 | 960
24 | 12000.000us | 3080 | 960
25 | 12500.000us | 3040 | 920
26 | 13000.000us | 3040 | 960
27 | 13500.000us | 2960 | 920
28 | 14000.000us | 3000 | 960
29 | 14500.000us | 2960 | 960
30 | 15000.000us | 3000 | 960
31 | 15500.000us | 2960 | 920
32 | 16000.000us | 2960 | 920
33 | 16500.000us | 2960 | 920
34 | 17000.000us | 2960 | 960
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

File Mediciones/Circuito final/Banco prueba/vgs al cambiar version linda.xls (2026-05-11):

Save Time: | 2026-05-11 12:52:02
 |  | CH1 | CH2
Frequency: |  | ? | ?
Period: |  | ? | ?
SP: |  | 500.000 uS | 500.000 uS
PK-PK: |  | 3.720 V | 3.960 V
Units:(mV) | Tiempo | S | G | VGS
2 | 500.000us | 3360 | 1080 | -2280
3 | 1000.000us | 3520 | 1120 | -2400
4 | 1500.000us | 3360 | 1080 | -2280
5 | 2000.000us | 3520 | 1120 | -2400
6 | 2500.000us | 3520 | 1120 | -2400
7 | 3000.000us | 3520 | 1120 | -2400
8 | 3500.000us | 3280 | 1000 | -2280
9 | 4000.000us | 3280 | 1000 | -2280
10 | 4500.000us | 3280 | 1000 | -2280
11 | 5000.000us | 3280 | 1000 | -2280
12 | 5500.000us | 3000 | 920 | -2080
13 | 6000.000us | 3000 | 920 | -2080
14 | 6500.000us | 3000 | 960 | -2040
15 | 7000.000us | 3040 | 1000 | -2040
16 | 7500.000us | 2960 | 920 | -2040
17 | 8000.000us | 3000 | 960 | -2040
18 | 8500.000us | 3000 | 960 | -2040
19 | 9000.000us | 3000 | 960 | -2040
20 | 9500.000us | 2960 | 920 | -2040
21 | 10000.000us | 3000 | 920 | -2080
22 | 10500.000us | 2960 | 960 | -2000
23 | 11000.000us | 3000 | 960 | -2040
24 | 11500.000us | 2960 | 920 | -2040
25 | 12000.000us | 2960 | 920 | -2040
26 | 12500.000us | 3040 | 960 | -2080
27 | 13000.000us | 3040 | 960 | -2080
28 | 13500.000us | 2960 | 920 | -2040
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

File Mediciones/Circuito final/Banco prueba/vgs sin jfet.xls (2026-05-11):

Save Time: | 2026-05-11 13:08:04
 |  | CH1 | CH2
Frequency: |  | ? | ?
Period: |  | ? | ?
SP: |  | 500.000 uS | 500.000 uS
PK-PK: |  | 3.840 V | 2.760 V
Units:(mV)
1 | 500.000us | 3320 | 1040 | -2280
2 | 1000.000us | 3360 | 1040 | -2320
3 | 1500.000us | 3040 | 920 | -2120
4 | 2000.000us | 3040 | 920 | -2120
5 | 2500.000us | 3000 | 920 | -2080
6 | 3000.000us | 3000 | 960 | -2040
7 | 3500.000us | 2960 | 880 | -2080
8 | 4000.000us | 3000 | 920 | -2080
9 | 4500.000us | 2960 | 920 | -2040
10 | 5000.000us | 3000 | 960 | -2040
11 | 5500.000us | 2960 | 880 | -2080
12 | 6000.000us | 2960 | 920 | -2040
13 | 6500.000us | 2960 | 880 | -2080
14 | 7000.000us | 3000 | 960 | -2040
15 | 7500.000us | 2960 | 880 | -2080
16 | 8000.000us | 3000 | 920 | -2080
17 | 8500.000us | 2920 | 920 | -2000
18 | 9000.000us | 3000 | 960 | -2040
19 | 9500.000us | 2920 | 920 | -2000
20 | 10000.000us | 3000 | 920 | -2080
21 | 10500.000us | 2960 | 920 | -2040
22 | 11000.000us | 3040 | 960 | -2080
23 | 11500.000us | 2960 | 880 | -2080
24 | 12000.000us | 3000 | 920 | -2080
25 | 12500.000us | 3040 | 920 | -2120
26 | 13000.000us | 3040 | 960 | -2080
27 | 13500.000us | 3000 | 920 | -2080
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

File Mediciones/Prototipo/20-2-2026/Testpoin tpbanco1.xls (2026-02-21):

Save Time: | 2026-02-20 15:45:16
 |  | CH1
Frequency: |  | ?
Period: |  | ?
SP: |  | 4000.000 uS
PK-PK: |  | 2.480 V
Units:(mV)
1 | 4000.000us | 2320
2 | 8000.000us | 2360
3 | 12000.000us | 2400
4 | 16000.000us | 2320
5 | 20000.000us | 2440
6 | 24000.000us | 2360
7 | 28000.000us | 2360
8 | 32000.000us | 2360
9 | 36000.000us | 2360
10 | 40000.000us | 2320
11 | 44000.000us | 2320
12 | 48000.000us | 2320
13 | 52000.000us | 2400
14 | 56000.000us | 2360
15 | 60000.000us | 2320
16 | 64000.000us | 2360
17 | 68000.000us | 2360
18 | 72000.000us | 2320
19 | 76000.000us | 2400
20 | 80000.000us | 2360
21 | 84000.000us | 2320
22 | 88000.000us | 2360
23 | 92000.000us | 2320
24 | 96000.000us | 2360
25 | 100000.000us | 2400
26 | 104000.000us | 2360
27 | 108000.000us | 2280
28 | 112000.000us | 2400
29 | 116000.000us | 2360
30 | 120000.000us | 2400
31 | 124000.000us | 2360
32 | 128000.000us | 2360
33 | 132000.000us | 2320
34 | 136000.000us | 2360
35 | 140000.000us | 2360
36 | 144000.000us | 2320
37 | 148000.000us | 2360
38 | 152000.000us | 2400
39 | 156000.000us | 2320
40 | 160000.000us | 2320
41 | 164000.000us | 2400
42 | 168000.000us | 2360
43 | 172000.000us | 2400
44 | 176000.000us | 2360
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

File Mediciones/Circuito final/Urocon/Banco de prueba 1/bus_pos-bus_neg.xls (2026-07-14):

Save Time: | 2026-07-14 12:49:07
 |  | CH1 | CH2
Frequency: |  | ? | ?
Period: |  | ? | ?
SP: |  | 1000.000 uS | 1000.000 uS
PK-PK: |  | 10.160 V ? | 5.600 V
 | tiempo | Bus Pos | Bus Neg | Vout
1 | 1000.000us | 5920 | 2720 | 3200
2 | 2000.000us | 5920 | 2800 | 3120
3 | 3000.000us | 5920 | 2720 | 3200
4 | 4000.000us | 5920 | 2800 | 3120
5 | 5000.000us | 5920 | 2800 | 3120
6 | 6000.000us | 5920 | 2880 | 3040
7 | 7000.000us | 5840 | 2800 | 3040
8 | 8000.000us | 5840 | 2800 | 3040
9 | 9000.000us | 5920 | 2800 | 3120
10 | 10000.000us | 6000 | 2800 | 3200
11 | 11000.000us | 5840 | 2720 | 3120
12 | 12000.000us | 5920 | 2800 | 3120
13 | 13000.000us | 5920 | 2800 | 3120
14 | 14000.000us | 5920 | 2800 | 3120
15 | 15000.000us | 5840 | 2720 | 3120
16 | 16000.000us | 5920 | 2720 | 3200
17 | 17000.000us | 5840 | 2800 | 3040
18 | 18000.000us | 5920 | 2800 | 3120
19 | 19000.000us | 5840 | 2720 | 3120
20 | 20000.000us | 5920 | 2800 | 3120
21 | 21000.000us | 5840 | 2720 | 3120
22 | 22000.000us | 6000 | 2800 | 3200
23 | 23000.000us | 5840 | 2720 | 3120
24 | 24000.000us | 5920 | 2720 | 3200
25 | 25000.000us | 5920 | 2800 | 3120
26 | 26000.000us | 6000 | 2800 | 3200
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

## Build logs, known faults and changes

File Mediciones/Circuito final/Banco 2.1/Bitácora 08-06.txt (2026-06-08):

Debido a la posibilidad de que haya algo quemado (recordar fin del episodio del 5 del 6 (capitulo 5, temporada 6)), se procede a revisar el funcionamiento de todo lo anterior.
Primero fueron las dos celdas completas: ambas funcionaban perfectamente por su cuenta.
Ahora queda el banco.

Se revisó continuidad para ver que no haya cortos raros (índice de componentes quemados) con éxito. Así que se siguió con la prueba del SR, cosa que no se hizo el capítulo pasado. Se usó la configuración de banco 1 con 1 celda y banco, y banco 2 con solo 1 celda (ideal, hecha con la fuente externa).
Funcionó perfectamente: se podían ver a la salida los 6.35V y 135mA.

Una segunda prueba fue colocar un modulo de celda en vez de la celda ideal, con la cual veiamos un corto en la fuente, luego de muchos intentos testeando nuevamente cada celda, concluimos que el problema fue usar un modulo de celda de banco 1, la cual tiene mosfet de tierra.

Cositas raras que vimos:
Cuando el banco 1 y celda 1 estan apagados con la celda virtual en bus pos, hay 54 mA en la salida.
Con todo apagado, sin VCC, los leds quedan prendidos por el controlador.

Prueba del MUX

Soldamos el mux junto a todos los divisores resistivos (aun falta los capacitores de este y el sr), intentamos una primer prueba de medición con el módulo celda, pero no se puede asegurar el funcionamiento correcto al tratarse del primer banco, ya que idealmente tendriamos 0V con la celda encendide e indefinido con la celda apagada. Probamos sacando la celda y conectando directamente diferentes tensiones en los pines hembra del modulo banco correspondientes a cell_neg. Comprobando de esta forma que funciona de manera exitosa el MUX. Pudimos comprobar que es posible reconstruir la tensión medida correcta del mux luego de pasar por el divisor resistivo, el cual tiene una escala de 1/5.

No se observaron comportamientos inesperados

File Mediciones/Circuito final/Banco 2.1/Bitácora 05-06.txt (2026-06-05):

Se soldó la parte del switch del banco y los pines de la placa 2.1 del PCB del banco. Se procedió a probarla para verificar el funcionamiento correcto del sistema de switcheo. La prueba consistió en un celda en paralelo con su banco y otra celda en serie a los dos anteriores. Ésta última está siempre encendida por lo que a la salida se deberían ver 6.6V o 3.3V. La carga es de 47ohm.

1ra prueba: fallida. Cuando el banco está apagado se observa una corriente de 120mA y una salida de unos 5.8V. Cuando se intenta apagar la celda que está en serie al banco, hay cortocircuito.

Se procede a volver a probar cada celda por separado. Ambas funcionan bien, por lo que el error probablemente sea el banco.

2do prueba: exitosa? Banco apagado y celda en serie virtual (hecha con la fuente externa en vez de la celda real).
V salida: 6.17V
I salida: 129mA
bus_pos - bus_neg: 3V ---> Medido en el banco
bus_pos: 3.09V
bus_neg: 70mV
Gate JFET: 2.99V
VGS PMOS: 0V

Banco prendido:
Gate PMOS: 1.06V
Source PMOS: 2.91V
=> VGS = -1.85V
Drain PMOS: 2.91V
Conclusión: EL P-MOSFET ANDA BIEN. Deducimos que cualquier diferencia de tensión a la salida respecto de la ideal es producto del cableado primitivo y la mala calidad de los cables dupont usados.

Se procede soldando el circuito del LED y el del SR.
Se eligió un LED amarillo para diferenciarlo del de las celdas y porque es el siguiente que menos tensión de encendido requiere.
Por último, para probar la estabilidad mecánica se enganchó una celda (con la pila puesta) al banco y pareció haber habido humo. Se revisará la próxima semana.

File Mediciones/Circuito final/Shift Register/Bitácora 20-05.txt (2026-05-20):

Pruebas del shift-register:

El lunes 18/05 se armaron plaquitas de prueba adaptadoras para los integrados del shift-register y del mux analógico al banco 2.0.

Tenemos soldados los pines de salida b-c-e-f-g.

Probamos la salida de data de la instrucción 10010001. Medimos en el osciloscopio y obtenemos los resultados esperados (resultados en Excels en esta carpeta).

Valores medidos:
Duración de un bit: ~6ms
Duración de un byte: ~48ms
Ambos son haciendo referencia a un bit de data. Los tiempos del clock del shift son ligeramente más cortos para asegurarse de registrar correctamente el valor enviado del controlador. A su vez, el clock del latch tiene igual duración que los anteriores pero es uno solo y se ubica luego de haber transmitido ocho pulsos de shift.

El problema ahora es que en una salida encendida del SR, se veían solamente 4V en lugar de los 5V necesarios para garantizar el funcionamiento del inversor de las celdas. Cabe destacar que se estaba usando el pin Vcc de 5V en el controlador. Así que se decidió probar conectando el Vcc a la fuente de continua de 5V.

Configuración de la fuente: 5V y 100mA.

El problema era que la fuente entró en corto. Se vio en el visor que se emitían unos 4V de tensión y se llegaba al tope de corriente. Se decidió retirar la plaquita adaptadora y probarla por fuera de la placa del banco para descartar que el problema sea el integrado en sí.

Hay altas chances que el integrado se haya quemado debido a que se aprecia un consumo de corriente de unos 30mA cuando está todo apagado. Vcc y GND conectados, clk_shift, clk_latch y Data a tierra, los demás pines abiertos. Se decidió armar otra plaquita de pruebas más robusta y proceder por el momento con otra celda.

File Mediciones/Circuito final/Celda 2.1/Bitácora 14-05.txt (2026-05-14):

Bitácora 14/05:

Prueba de la primera celda v2.1:
Primero se soldó e hicieron las mediciones de la etapa de control --> Dio todo bien
Se conectó un resistor de 47ohm a cell_neg para cerrar la malla con la celda. Esto fue porque los NMOS no estaban soldados todavía.
Los valores de los test-points (control = 5V): inv: 0.0V | base pnp: 2.75V | gate NMOS: 3.27V
Los valores de los test-points (control = 0V): inv: 4.98V | base pnp: 2.73V | gate NMOS: 16.9mV

El único rasgo a destacar es que el LED, a pesar de tener todos sus componentes soldados, enciende muy despacito.
Se procede a soldar el resto del módulo y rever nuevamente este tema cuando esté todo finalizado y funcionando correctamente

Update: Al investigar porque la base del pnp en apagado nos daba 2.73V en vez de 3.27V, encontramos a los culpables, los resistores 2 y 3, los resistores de base del pnp. Al ser de 10Meg y 1Meg, por más de que la corriente que circulara en esa rama sea casi despreciable, generaban una gran caida de tensión. Al parecer el sistema de alguna forma seguía funcionando bien, ya que en el gate veiamos la tensión correcta. De todas formas cambiamos a los valores de prototitpo, 10k y 1k, nos queda pendiente analizar si estos valores nos sirven a nivel de eficiencia, y si es posible utilizarlos en bancos con más tensión. Otro pendiente que viene de la mano, es probar otros resistores manteniendo la relación pero creciendo en resistencia.

Luego de arreglar el driver, continuamos con los N-MOSFET.
Con todo soldado, las mediciones dieron correctas y el funcionamiento se verificó.

Nos queda únicamente revisar:
- Los valores de R2 y R3 (queremos que sean lo más grande posibles sin afectar la tensión del nodo de base del pnp)
- Reemplazar el resistor de 0ohm por el fusible de 3A
- Ver por qué el LED enciende muy despacito (probablemente haya que cambiar el resistor de 1k)

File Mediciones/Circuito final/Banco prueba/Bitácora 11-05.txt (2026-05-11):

Bitácora 11/05:

Oficialmete prueba del nuevo P-MOSFET (IRLML6402):
Hacemos las pruebas con y sin jfet ahora con el pmos correcto.
Banco de pruebas, ponemos una tensión 13.2V como banco superior, y buscamos medir el vgs del pmos.

Primer prueba con el Jfet soldado, con resistencias de 470k y 220k en el banco. No llegamos medir tiempo, el cambio es despreciable para la precicios del osciloscopio, por lo tanto tarda en descargarse menos de 500us. Vemos, a pesar del ruido, que la tensión del source y el gate quedan supuerpuestas, obteniendo un vgs de aprox 0V al estabilizar. 
Segunda prueba sin Jfet, mismas resistencias. Se nos dificulta medir el tiempo exacto debido al ruido pero el tiempo de apagado si es aprecible sin el jfet. De todas formas se observa que el PMOS  no se llega a descargar, obteniendo un vgs promedio de apagado de aprox -1V.

En resumen si nos conviene el jfet.

Dato de color: estamos perdiendo unos 250mV en los cocos y solo unos 30mV en el PMOS => cuando tengamos el circuito posta la salida va a ser mucho más cercana a los 3.3V por celda como debería ser.

______________________

Análisis de bancos máximos posibles:

Como vamos a seguir usando la STM32, tenemos 16 pines ADC, de los cuales 2 son usados para la comunicación (PA2 y PA3). Entonces, nos quedan 14 pines ADC para usar en los bancos. Cada banco usa 3: bus_pos, bus_neg y salida_adc, por lo que podríamos poner 4 bancos. Si usamos uno de los jumpers soldados en la placa podemos aumentar ese número por lo que estaríamos cómodos con 5 bancos.

Por otro lado, tenemos 6 pines GPIO compartidos entre todos los bancos (clk_shift, clk_latch, reset, selector_0, sel_1, sel_2), y solamente 1 pin diferente para cada banco: el de control.

_____________________

Valores de los resistores R2 y R3 de las celdas:

Manteniendo los valores de 10M y 1M, tenemos 15uA circulando en la malla de control del transistor Q1 npn. La potencia disipada por el resistor de 1M es de 240uW, mientras que en el transistor es de 100nW (estos valores fueron de simulación). Todo esto fue simulado para una calda del banco número 5, el peor caso. Por esto consideramos que no es necesario tener valores diferentes de resistencia, y todas las celdas pueden usar perfectamente 10M y 1M.

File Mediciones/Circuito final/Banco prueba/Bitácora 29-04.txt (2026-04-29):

Bitácora 29/04:

Prueba del nuevo P-MOSFET (IRLML6402):
- El lunes 27/04 se probó el MOS encontrando cortocircuitos tanto en encendido como apagado. Cabe destacar que se implementó el circuito en una placa de pruebas.
- No se encontró el error por lo que se asumió que el problema era la placa y su poca facilidad para testear componentes SMD. Como consecuencia, se elaboró un mini PCB específico.

- Miércoles 29: ahora con el nuevo PCB, siguen habiendo cortocircuitos, igual que como con la placa de pruebas.
- Se probó la continuidad tanto en la placa como en el componente asilados y todo ok, por lo que se supuso que no había problemas de diseño del PCB ni que el componente esté dañado.
- Sin embargo, con el componente soldado, había una ligera circulación de corriente tanto entre drain-source como viceversa.
- Se probó con otro modelo de P-MOSFET, el AO3401 (usado en el inversor), y ahora sí todo ok. Suponemos que hubo un error del vendedor y nos dio N-MOSFETs. Como dato de color, el código escrito sobre los supuestos IRLML6402 no coincidían con ningún componente comercial, según Google. El código era N025P.

- Se repitieron las simulaciones en LTspice con el nuevo nuevo MOSFET y los resultados eran los esperados. Sin embargo, térmicamente no se cumple con la potencia máxima disipada, por lo que se decidió diseñar la placa con dos de estos transistores en paralelo.

- Por último se hicieron mediciones en la plaquita de prueba de todo el circuito para verificar el correcto funcionamiento circuital en todos los nodos.

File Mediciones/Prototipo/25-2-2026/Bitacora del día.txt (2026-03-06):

Repasamos las mediciones del día anterior, pero al ver distintas mediciones entre bus pos y el gate del pmos y el nmos (celda 2), decidimos probar sacando todos los diodos.

Medimos nuevamente la celda 2 y el gate efectivamente se descarga, cae 0V. Medimos esto en la celda 1, y sigue sin funcionar.

Desconectamos el portafusibles de la celda 1 para desconectar la celda, medidmos y encontramos que sigue habiendo 2.8V en el gate con el control de la celda en OFF, creemos que el responsable es el driver.

DATO DE COLOR: Al probar la celda 1, conectamos la fuente de tensión a la celda 1, pero el control seguia para la celda 2, al poner el control en ON, habia consumo de corriente e incluso caida de tension en la celda 2.

Desconectamos la rout de la celda 1, para aislarla completamente.

Colocamos la celda en el portapilas de la celda 2 y funciona todo como corresponde.

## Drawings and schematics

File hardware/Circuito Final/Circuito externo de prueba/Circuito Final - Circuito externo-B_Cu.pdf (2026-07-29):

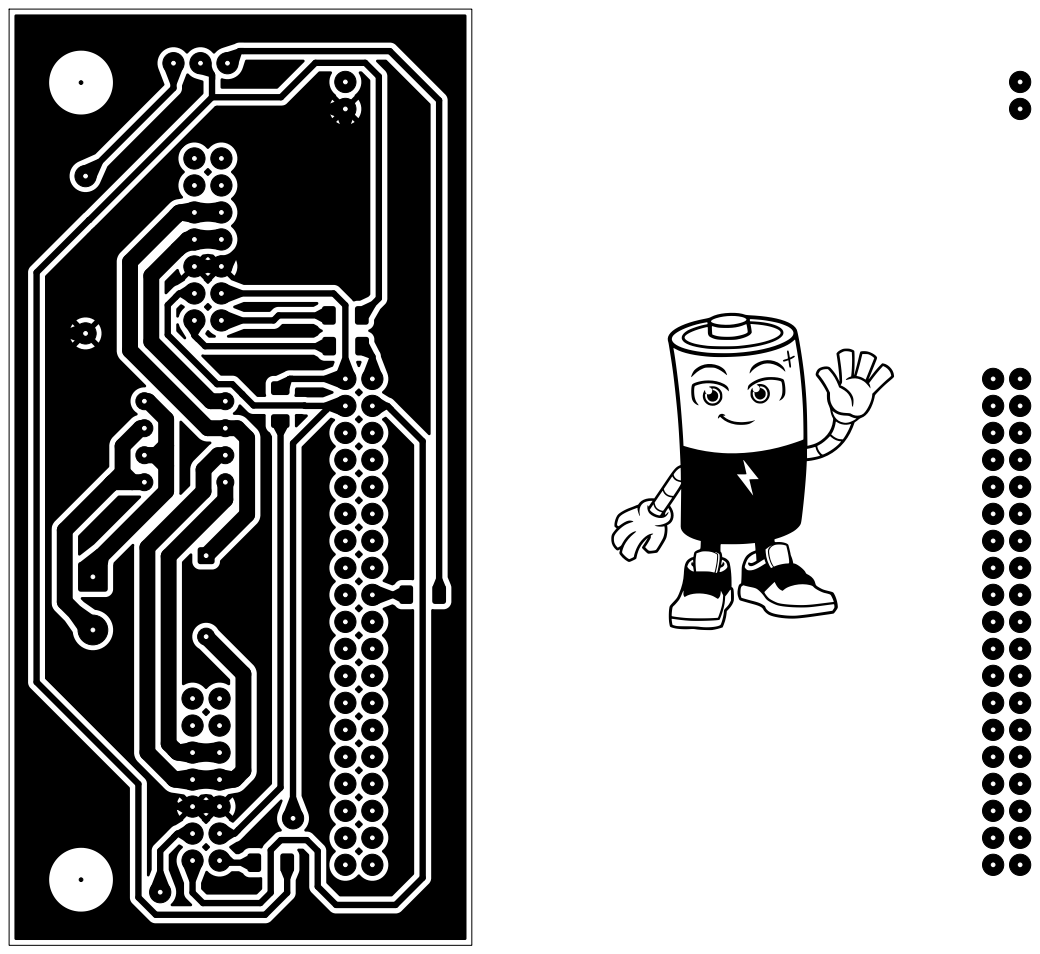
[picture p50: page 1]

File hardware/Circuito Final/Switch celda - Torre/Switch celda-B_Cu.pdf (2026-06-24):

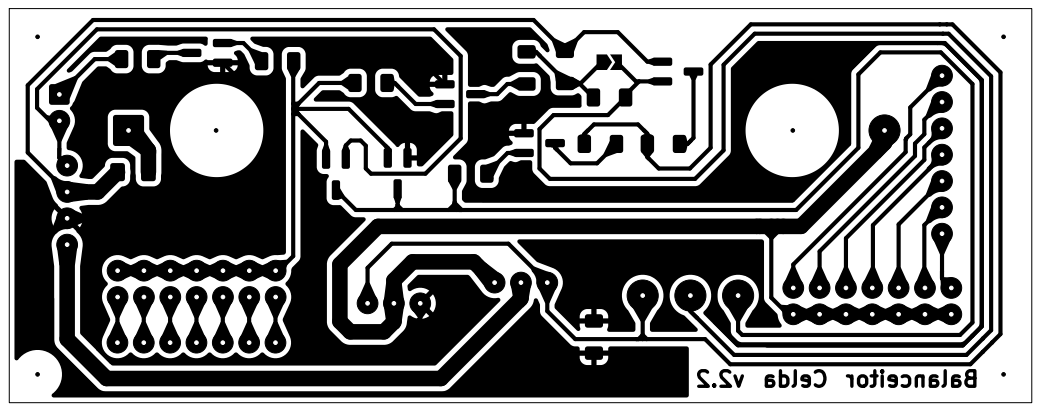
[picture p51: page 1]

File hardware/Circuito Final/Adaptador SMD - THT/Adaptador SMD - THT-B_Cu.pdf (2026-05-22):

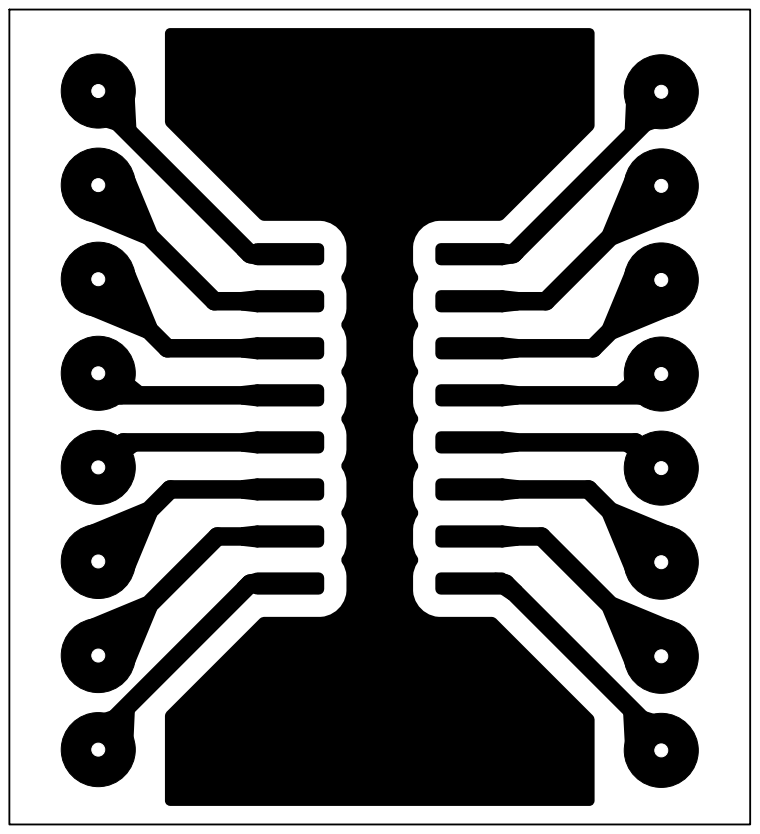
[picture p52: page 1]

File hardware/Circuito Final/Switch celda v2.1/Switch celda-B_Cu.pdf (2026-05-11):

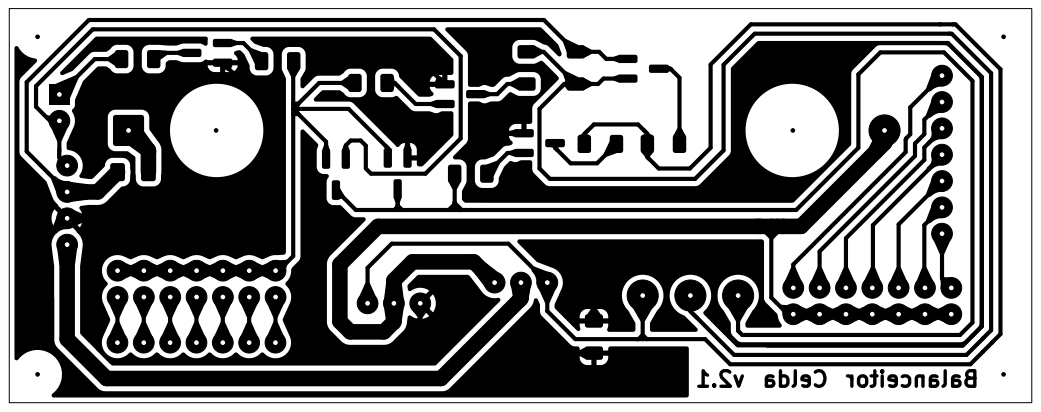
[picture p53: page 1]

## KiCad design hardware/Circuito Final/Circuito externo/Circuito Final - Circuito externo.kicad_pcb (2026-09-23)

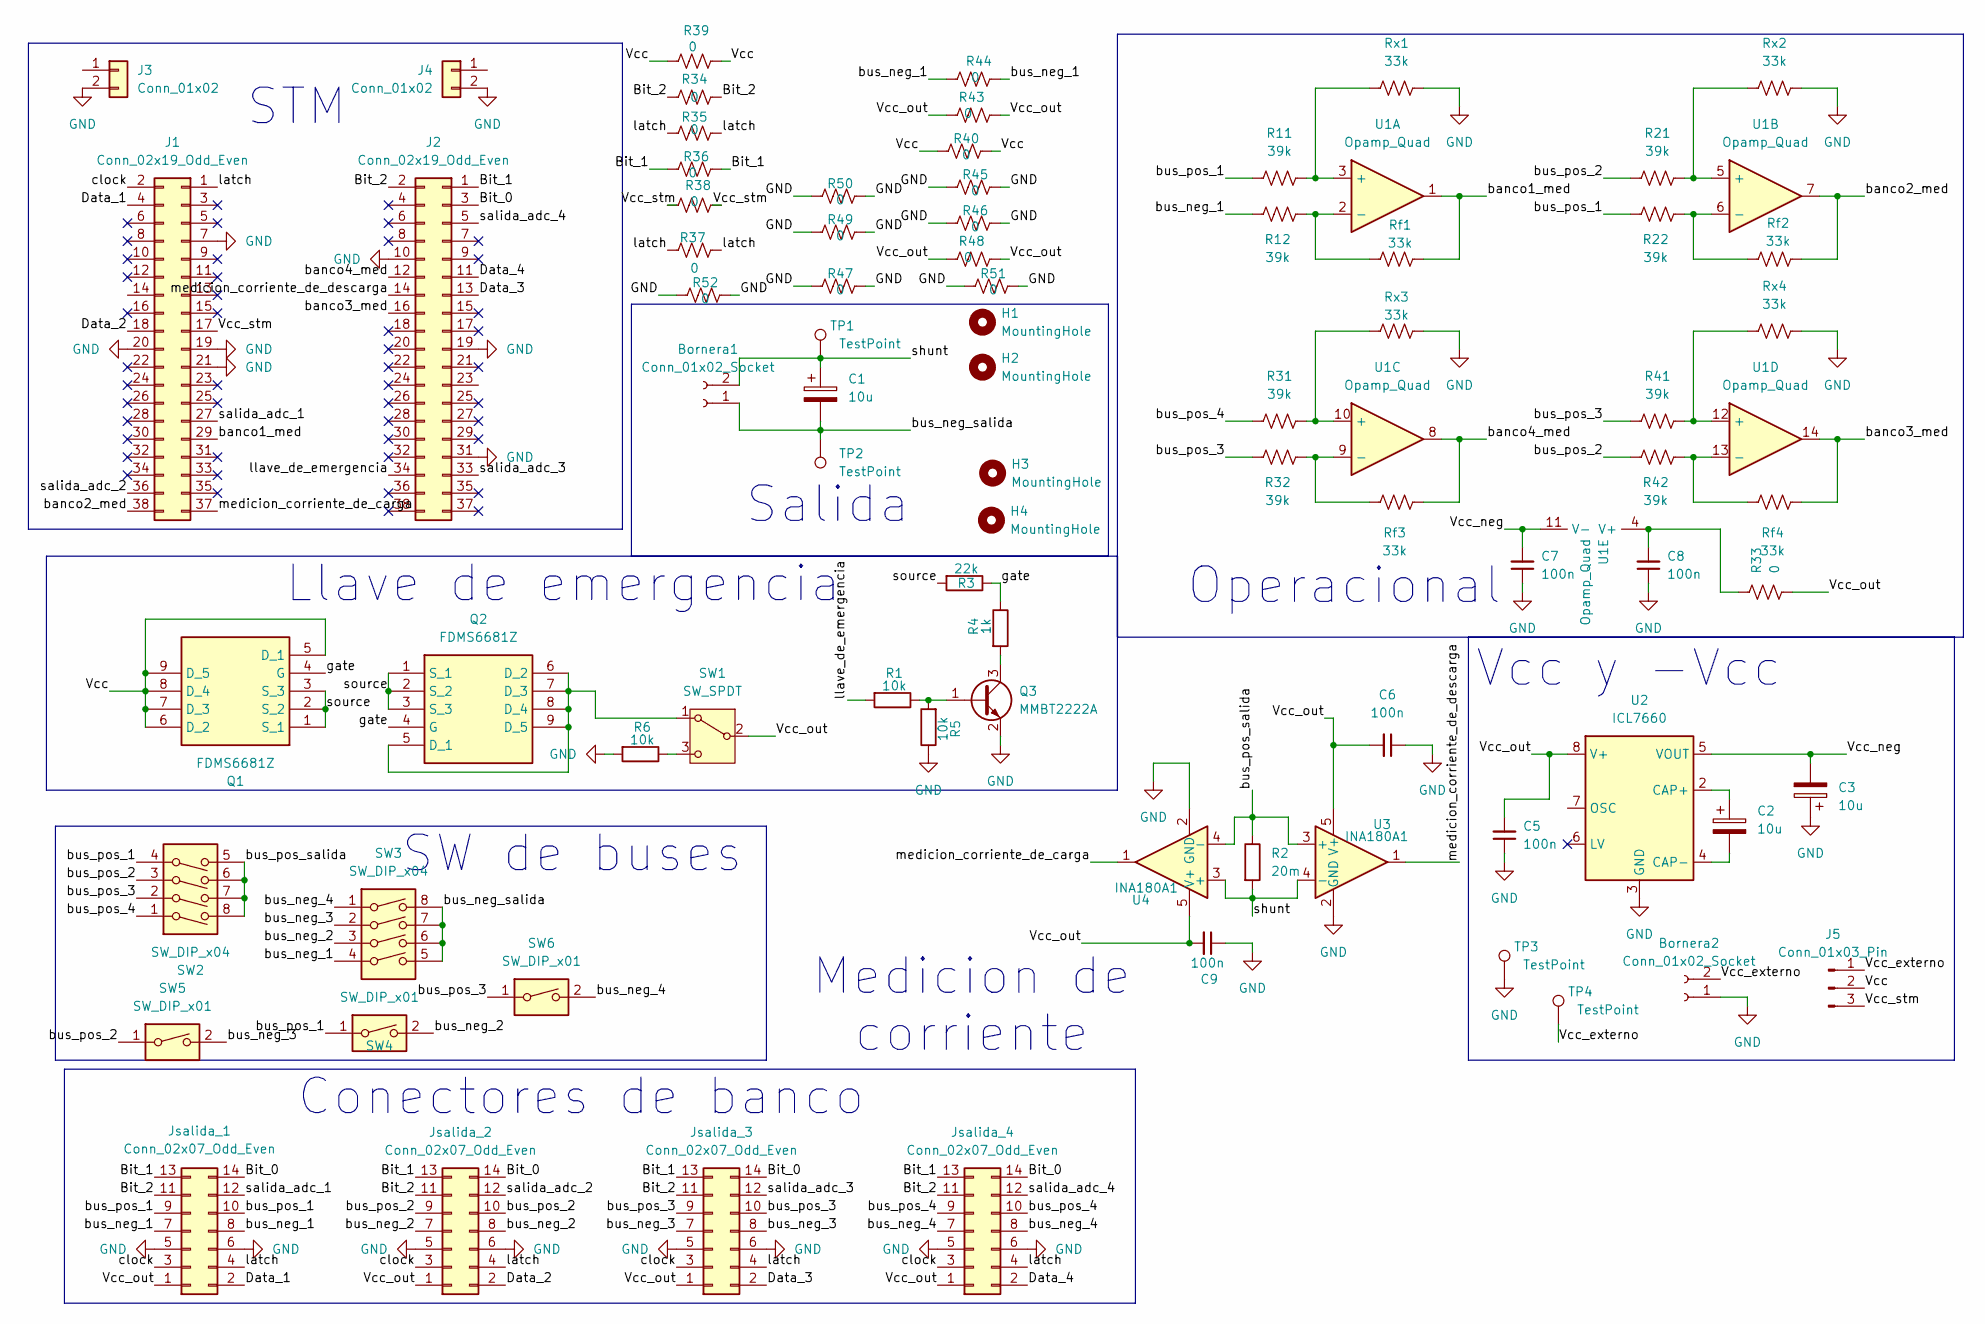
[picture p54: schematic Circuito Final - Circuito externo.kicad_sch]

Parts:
Bornera1, Bornera2: Conn_01x02_Socket; TerminalBlock_bornier-2_P5.08mm
C1, C2, C3: 10u; C_1206_3216Metric_Pad1.33x1.80mm_HandSolder
C5, C6, C7, C8, C9: 100n; C_1206_3216Metric_Pad1.33x1.80mm_HandSolder
H1, H2, H3, H4: MountingHole; MountingHole_3.5mm
J1, J2: Conn_02x19_Odd_Even; PinSocket_2x19_P2.54mm_Vertical
J3, J4: Conn_01x02; PinSocket_1x02_P2.54mm_Vertical
J5: Conn_01x03_Pin; PinHeader_1x03_P2.54mm_Vertical
Jsalida_1, Jsalida_2, Jsalida_3, Jsalida_4: Conn_02x07_Odd_Even; IDC-Header_2x07_P2.54mm_Horizontal
Q1, Q2: FDMS6681Z; Mouser Part Number 512-FDMS6681Z
Q3: MMBT2222A; SOT-23
R1, R5, R6: 10k; R_1206_3216Metric_Pad1.30x1.75mm_HandSolder
R2: 20m; R_2512_6332Metric_Pad1.40x3.35mm_HandSolder
R3: 22k; R_1206_3216Metric_Pad1.30x1.75mm_HandSolder
R4: 1k; R_1206_3216Metric_Pad1.30x1.75mm_HandSolder
R11, R12, R21, R22, R31, R32, R41, R42: 39k; R_1206_3216Metric_Pad1.30x1.75mm_HandSolder
R33, R34, R35, R36, R37, R38, R39, R40, R43, R44, R45, R46, R47, R48, R49, R50, R51, R52: 0; R_1206_3216Metric_Pad1.30x1.75mm_HandSolder
Rf1, Rf2, Rf3, Rf4: 33k; R_1206_3216Metric_Pad1.30x1.75mm_HandSolder
Rx1, Rx2, Rx3, Rx4: 33k; R_1206_3216Metric_Pad1.30x1.75mm_HandSolder
SW1: SW_SPDT; SW_Slide_SPDT_Straight_CK_OS102011MS2Q
SW2, SW3: SW_DIP_x04; SW_DIP_SPSTx04_Slide_6.7x11.72mm_W7.62mm_P2.54mm_LowProfile
SW4, SW5, SW6: SW_DIP_x01; SW_DIP_SPSTx01_Slide_9.78x4.72mm_W7.62mm_P2.54mm
TP1, TP2: TestPoint; PinHeader_1x01_P2.54mm_Vertical
TP3, TP4: TestPoint; TestPoint_Keystone_5005-5009_Compact
U1: Opamp_Quad; SO-14_3.9x8.65mm_P1.27mm
U2: ICL7660; SOIC-8_3.9x4.9mm_P1.27mm
U3, U4: INA180A1; SOT-23-5

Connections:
/Bit_0: J2.3, Jsalida_1.14, Jsalida_2.14, Jsalida_3.14, Jsalida_4.14
/Bit_1: J2.1, Jsalida_1.13, Jsalida_2.13, Jsalida_3.13, Jsalida_4.13, R36.1, R36.2
/Bit_2: J2.2, Jsalida_1.11, Jsalida_2.11, Jsalida_3.11, Jsalida_4.11, R34.1, R34.2
/Data_1: J1.4, Jsalida_1.2
/Data_2: J1.18, Jsalida_2.2
/Data_3: J2.13, Jsalida_3.2
/Data_4: J2.11, Jsalida_4.2
/Vcc: J5.2, Q1.5 (D_1), Q1.6 (D_2), Q1.7 (D_3), Q1.8 (D_4), Q1.9 (D_5), R39.1, R39.2, R40.1, R40.2
/Vcc_externo: Bornera2.2, J5.1, TP4.1 (1_1)
/Vcc_neg: C3.2, C7.2, U1.11 (V-), U2.5 (VOUT)
/Vcc_out: C5.2, C6.2, C9.2, Jsalida_1.1, Jsalida_2.1, Jsalida_3.1, Jsalida_4.1, R33.1, R43.1, R43.2, R48.1, R48.2, SW1.2 (B), U2.8 (V+), U3.5 (V+), U4.5 (V+)
/Vcc_stm: J1.17, J5.3, R38.1, R38.2
/banco1_med: J1.29, Rf1.2, U1.1
/banco2_med: J1.38, Rf2.2, U1.7
/banco3_med: J2.16, Rf4.2, U1.14
/banco4_med: J2.12, Rf3.2, U1.8
/bus_neg_1: Jsalida_1.7, Jsalida_1.8, R12.2, R44.1, R44.2, SW3.4
/bus_neg_2: Jsalida_2.7, Jsalida_2.8, SW3.3, SW4.2
/bus_neg_3: Jsalida_3.7, Jsalida_3.8, SW3.2, SW5.2
/bus_neg_4: Jsalida_4.7, Jsalida_4.8, SW3.1, SW6.2
/bus_neg_salida: Bornera1.1, C1.2, SW3.5, SW3.6, SW3.7, SW3.8, TP2.1 (1_1)
/bus_pos_1: Jsalida_1.9, Jsalida_1.10, R11.1, R22.2, SW2.4, SW4.1
/bus_pos_2: Jsalida_2.9, Jsalida_2.10, R21.1, R42.2, SW2.3, SW5.1
/bus_pos_3: Jsalida_3.9, Jsalida_3.10, R32.2, R41.1, SW2.2, SW6.1
/bus_pos_4: Jsalida_4.9, Jsalida_4.10, R31.1, SW2.1
/bus_pos_salida: R2.1, SW2.5, SW2.6, SW2.7, SW2.8, U3.3 (+), U4.4 (-)
/clock: J1.2, Jsalida_1.3, Jsalida_2.3, Jsalida_3.3, Jsalida_4.3
/gate: Q1.4 (G), Q2.4 (G), R3.1, R4.1
/latch: J1.1, Jsalida_1.4, Jsalida_2.4, Jsalida_3.4, Jsalida_4.4, R35.1, R35.2, R37.1, R37.2
/llave_de_emergencia: J2.34, R1.2
/medicion_corriente_de_carga: J1.37, U4.1
/medicion_corriente_de_descarga: J2.14, U3.1
/salida_adc_1: J1.27, Jsalida_1.12
/salida_adc_2: J1.36, Jsalida_2.12
/salida_adc_3: J2.33, Jsalida_3.12
/salida_adc_4: J2.5, Jsalida_4.12
/shunt: Bornera1.2, C1.1, R2.2, TP1.1 (1_1), U3.4 (-), U4.3 (+)
/source: Q1.1 (S_1), Q1.2 (S_2), Q1.3 (S_3), Q2.1 (S_1), Q2.2 (S_2), Q2.3 (S_3), R3.2
GND: Bornera2.1, C3.1, C5.1, C6.1, C7.1, C8.1, C9.1, J1.7, J1.19, J1.20, J1.21, J2.10, J2.19, J2.31, J3.2 (Pin_2_2), J4.2 (Pin_2_2), Jsalida_1.5, Jsalida_1.6, Jsalida_2.5, Jsalida_2.6, Jsalida_3.5, Jsalida_3.6, Jsalida_4.5, Jsalida_4.6, Q3.2 (E), R5.1, R6.2, R45.1, R45.2, R46.1, R46.2, R47.1, R47.2, R49.1, R49.2, R50.1, R50.2, R51.1, R51.2, R52.1, R52.2, Rx1.2, Rx2.2, Rx3.2, Rx4.2, TP3.1 (1_1), U2.3 (GND), U3.2 (GND), U4.2 (GND)
unnamed: Q2.5 (D_1), Q2.6 (D_2), Q2.7 (D_3), Q2.8 (D_4), Q2.9 (D_5), SW1.1 (A)
unnamed: Q3.1 (B), R1.1, R5.2
unnamed: Q3.3 (C), R4.2
unnamed: R6.1, SW1.3 (C)
unnamed: R11.2, Rx1.1, U1.3 (+)
unnamed: R12.1, Rf1.1, U1.2 (-)
unnamed: R21.2, Rx2.1, U1.5 (+)
unnamed: R22.1, Rf2.1, U1.6 (-)
unnamed: R31.2, Rx3.1, U1.10 (+)
unnamed: R32.1, Rf3.1, U1.9 (-)
unnamed: R41.2, Rx4.1, U1.12 (+)
unnamed: R42.1, Rf4.1, U1.13 (-)
unnamed: C8.2, R33.2, U1.4 (V+)
unnamed: C2.1, U2.2 (CAP+)
unnamed: C2.2, U2.4 (CAP-)

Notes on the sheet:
Conectores de banco
Llave de emergencia
Salida
STM
SW de buses
Medicion de corriente
Operacional
Vcc y -Vcc

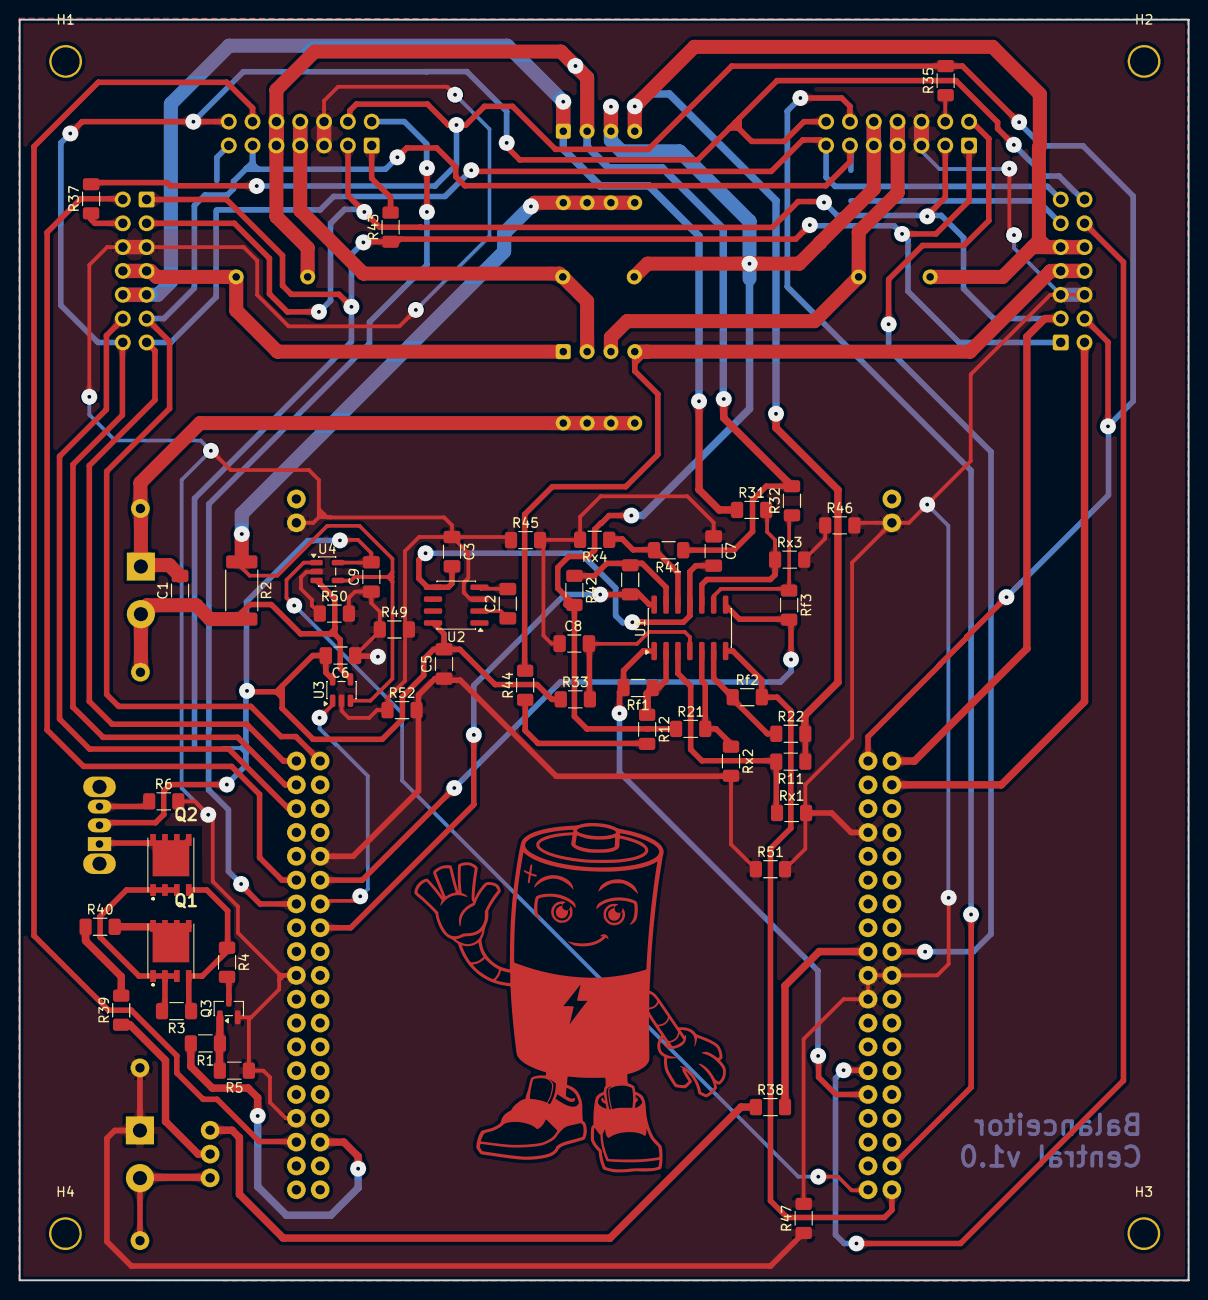
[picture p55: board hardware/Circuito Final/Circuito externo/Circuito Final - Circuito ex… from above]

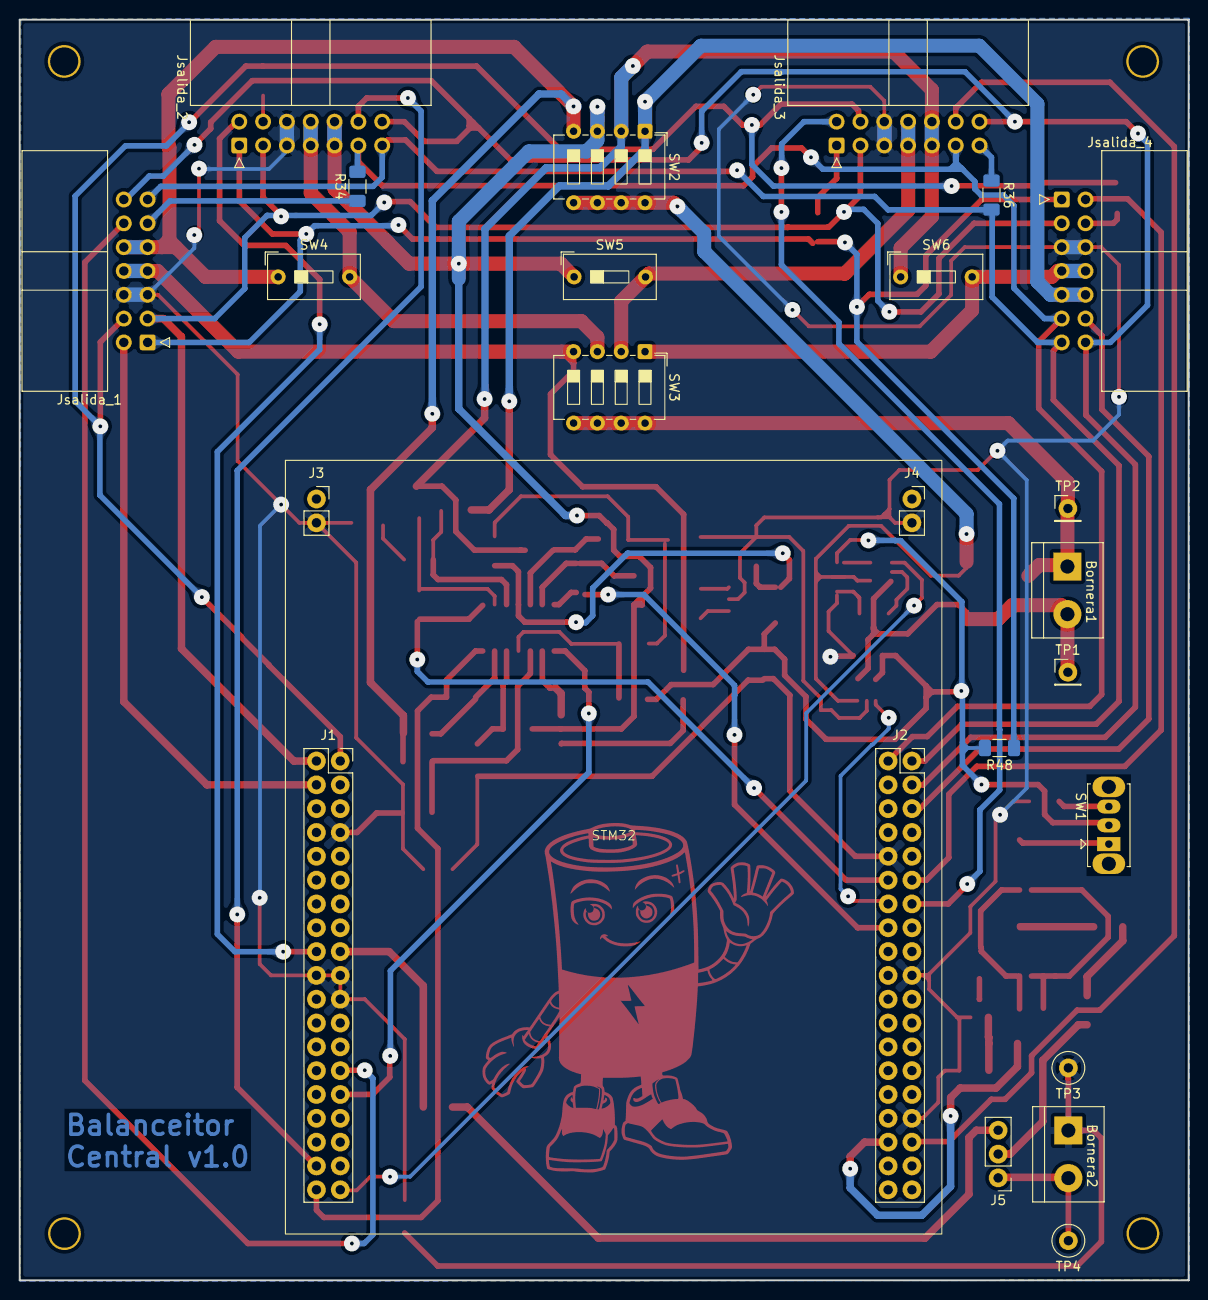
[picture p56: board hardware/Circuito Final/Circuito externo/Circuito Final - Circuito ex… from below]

Board: 2 copper layers, 124.6 x 134.4 mm, 81 parts (25 on the bottom side), 54 nets.

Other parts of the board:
STM32: STM32

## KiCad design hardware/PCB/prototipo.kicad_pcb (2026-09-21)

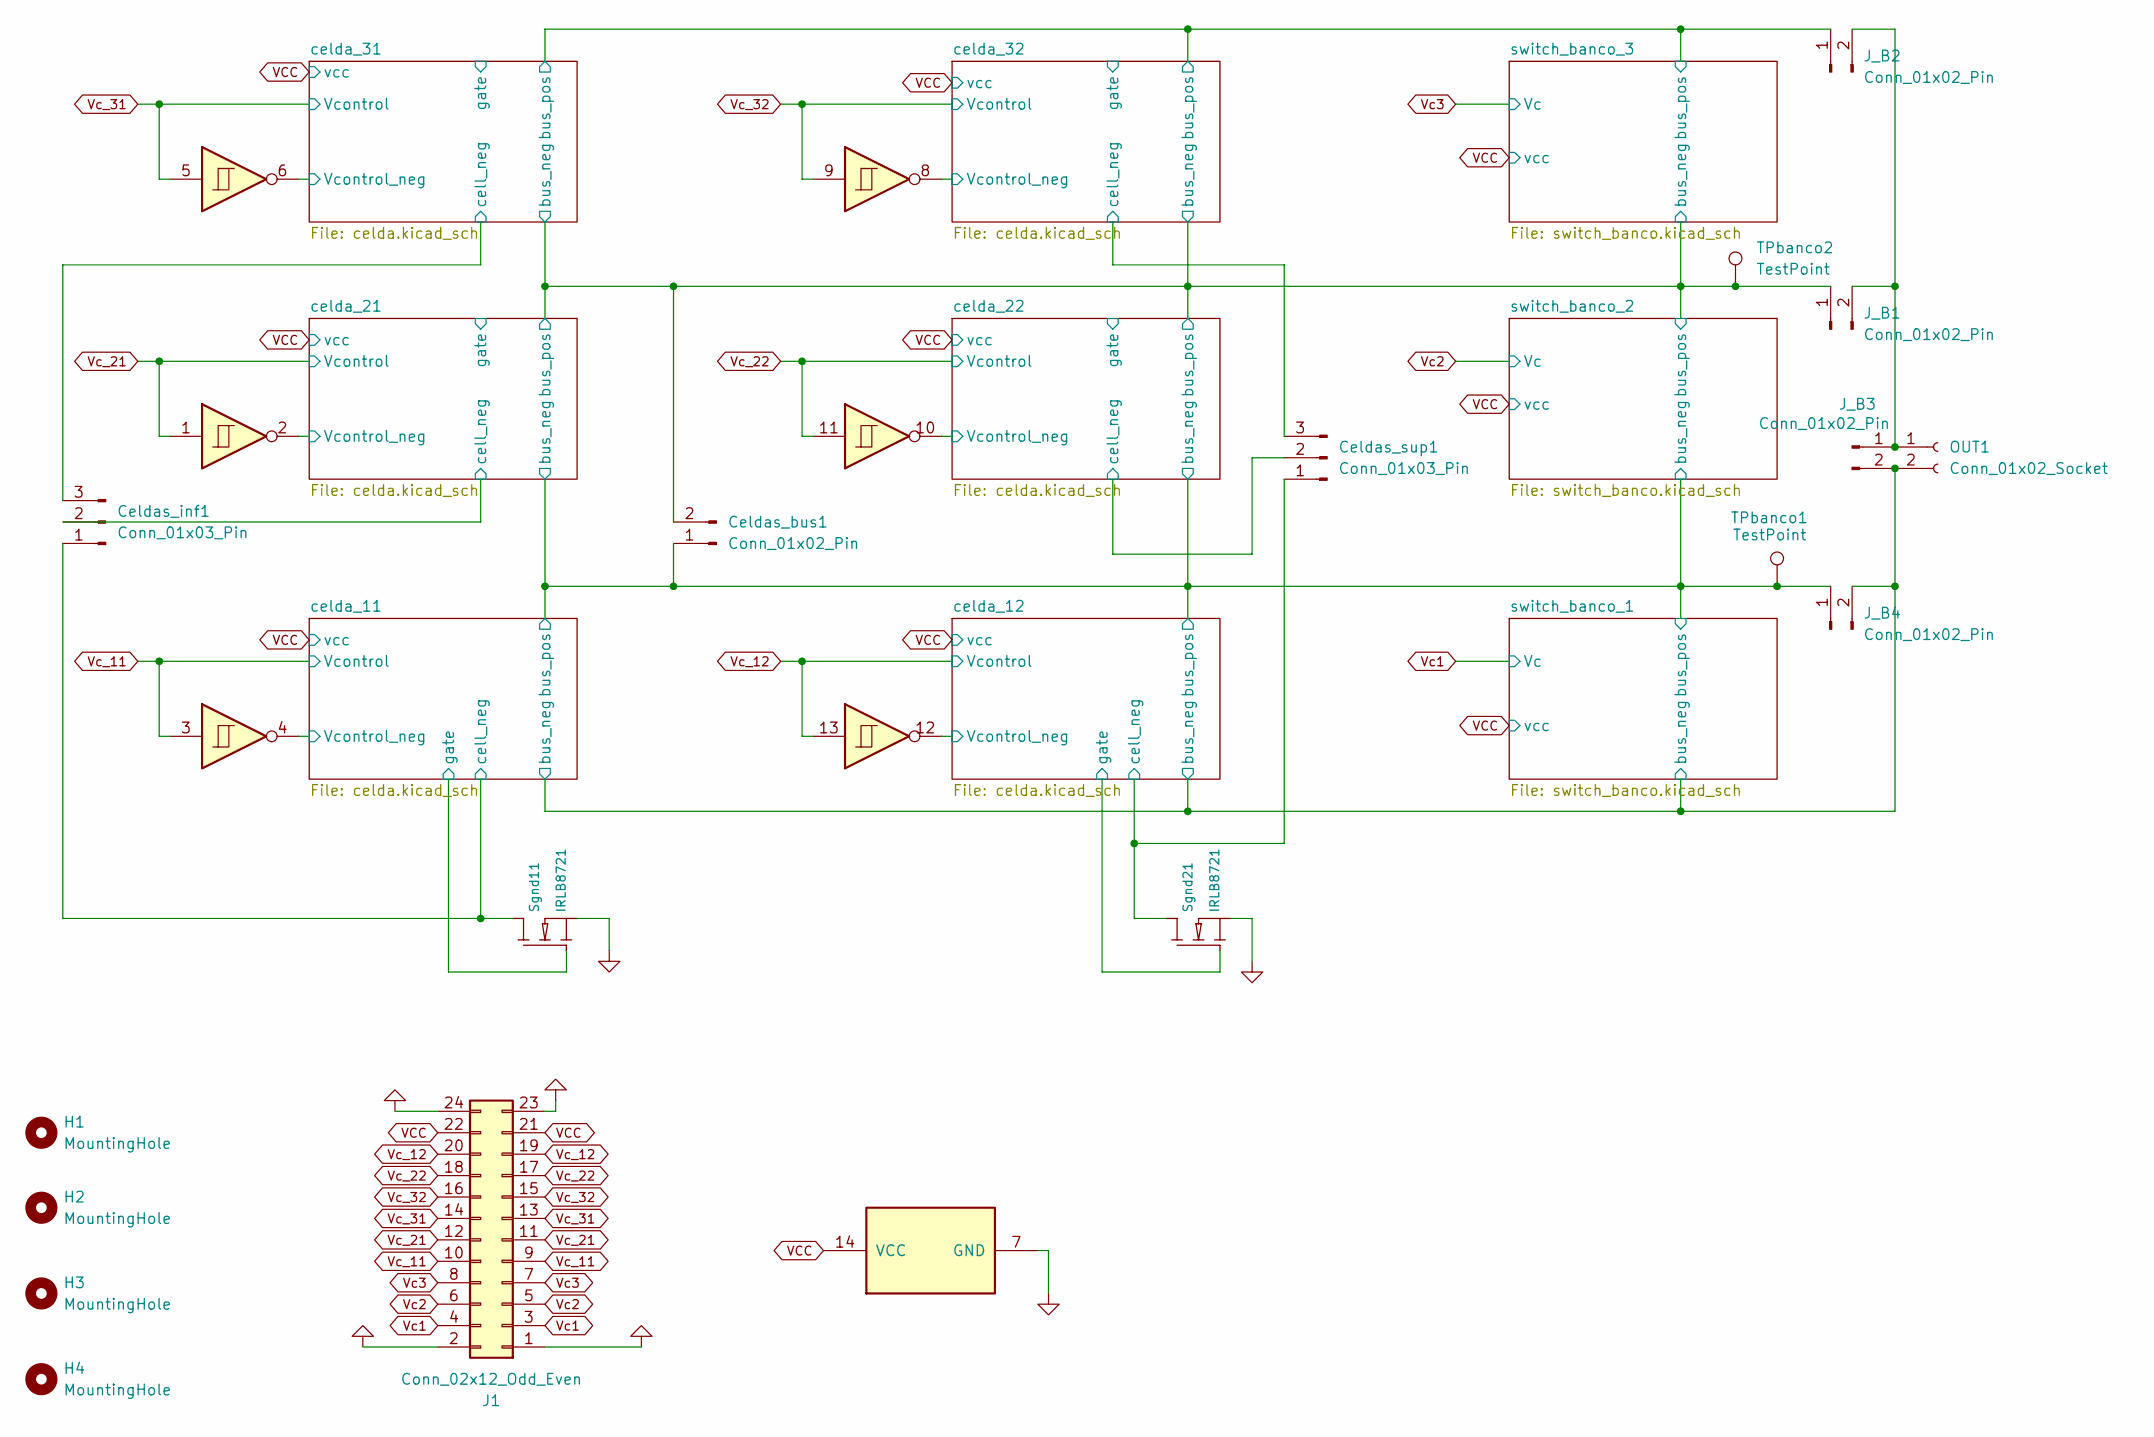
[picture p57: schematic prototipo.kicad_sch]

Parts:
A1: DIP-14_W7.62mm_LongPads
Celdas_bus1: Conn_01x02_Pin; PinHeader_1x02_P2.54mm_Vertical
Celdas_inf1: Conn_01x03_Pin; PinHeader_1x03_P2.54mm_Vertical
Celdas_sup1: Conn_01x03_Pin; PinHeader_1x03_P2.54mm_Vertical
H1, H2, H3, H4: MountingHole; MountingHole_3.2mm_M3
J1: Conn_02x12_Odd_Even; PinHeader_2x12_P2.54mm_Vertical
J_B1, J_B2, J_B3, J_B4: Conn_01x02_Pin; PinHeader_1x02_P2.54mm_Vertical
OUT1: Conn_01x02_Socket; TerminalBlock_bornier-2_P5.08mm
Sgnd11, Sgnd21: IRLB8721; TO-220-3_Vertical
TPbanco1, TPbanco2: TestPoint; TestPoint_Bridge_Pitch2.54mm_Drill1.0mm

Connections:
0: A1.7 (GND), J1.1, J1.2, J1.23, J1.24, Sgnd11.3 (S), Sgnd21.3 (S); also elsewhere on the board
/celda_11/Vcontrol_neg: A1.4; also elsewhere on the board
/celda_11/bus_neg: J_B3.2, J_B4.2, OUT1.2; also elsewhere on the board
/celda_11/bus_pos: Celdas_bus1.1, J_B4.1, TPbanco1.1; also elsewhere on the board
/celda_11/cell_neg: Celdas_inf1.1, Sgnd11.2 (D); also elsewhere on the board
/celda_11/gate: Sgnd11.1 (G); also elsewhere on the board
/celda_12/Vcontrol_neg: A1.12; also elsewhere on the board
/celda_12/cell_neg: Celdas_sup1.1, Sgnd21.2 (D); also elsewhere on the board
/celda_12/gate: Sgnd21.1 (G); also elsewhere on the board
/celda_21/Vcontrol_neg: A1.2; also elsewhere on the board
/celda_21/bus_pos: Celdas_bus1.2, J_B1.1, TPbanco2.1; also elsewhere on the board
/celda_21/cell_neg: Celdas_inf1.2; also elsewhere on the board
/celda_22/Vcontrol_neg: A1.10; also elsewhere on the board
/celda_22/cell_neg: Celdas_sup1.2; also elsewhere on the board
/celda_31/Vcontrol_neg: A1.6; also elsewhere on the board
/celda_31/bus_pos: J_B2.1; also elsewhere on the board
/celda_31/cell_neg: Celdas_inf1.3; also elsewhere on the board
/celda_32/Vcontrol_neg: A1.8; also elsewhere on the board
/celda_32/cell_neg: Celdas_sup1.3; also elsewhere on the board
unnamed: J_B1.2, J_B2.2, J_B3.1, OUT1.1
VCC: A1.14 (VCC), J1.21, J1.22; also elsewhere on the board
Vc1: J1.3, J1.4; also elsewhere on the board
Vc2: J1.5, J1.6; also elsewhere on the board
Vc3: J1.7, J1.8; also elsewhere on the board
Vc_11: A1.3, J1.9, J1.10; also elsewhere on the board
Vc_12: A1.13, J1.19, J1.20; also elsewhere on the board
Vc_21: A1.1, J1.11, J1.12; also elsewhere on the board
Vc_22: A1.11, J1.17, J1.18; also elsewhere on the board
Vc_31: A1.5, J1.13, J1.14; also elsewhere on the board
Vc_32: A1.9, J1.15, J1.16; also elsewhere on the board

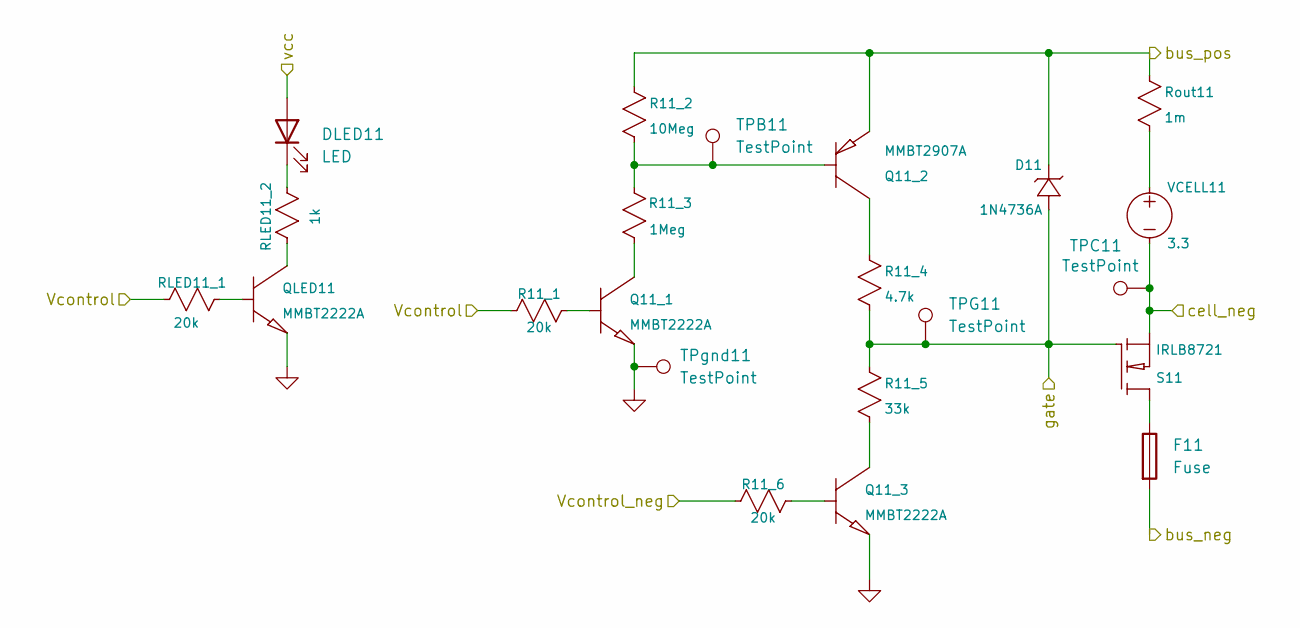
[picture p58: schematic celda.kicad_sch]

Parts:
D11: 1N4736A; D_DO-41_SOD81_P7.62mm_Horizontal
DLED11: LED; LED_D5.0mm
F11: Fuse; Fuseholder_Cylinder-5x20mm_Schurter_0031_8201_Horizontal_Op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
Q11_1, Q11_3: MMBT2222A; SOT-23-3
Q11_2: MMBT2907A; SOT-23-3
QLED11: MMBT2222A; SOT-23-3
R11_1, R11_6: 20k; R_Axial_DIN0207_L6.3mm_D2.5mm_P7.62mm_Horizontal
R11_2: 10Meg; R_Axial_DIN0207_L6.3mm_D2.5mm_P7.62mm_Horizontal
R11_3: 1Meg; R_Axial_DIN0207_L6.3mm_D2.5mm_P7.62mm_Horizontal
R11_4: 4.7k; R_Axial_DIN0207_L6.3mm_D2.5mm_P7.62mm_Horizontal
R11_5: 33k; R_Axial_DIN0207_L6.3mm_D2.5mm_P7.62mm_Horizontal
RLED11_1: 20k; R_Axial_DIN0207_L6.3mm_D2.5mm_P7.62mm_Horizontal
RLED11_2: 1k; R_Axial_DIN0207_L6.3mm_D2.5mm_P7.62mm_Horizontal
Rout11: 1m; R_Axial_DIN0207_L6.3mm_D2.5mm_P7.62mm_Horizontal
S11: IRLB8721; TO-220-3_Vertical
TPB11: TestPoint; TestPoint_Bridge_Pitch2.54mm_Drill1.0mm
TPC11: TestPoint; TestPoint_Bridge_Pitch2.54mm_Drill1.0mm
TPG11: TestPoint; TestPoint_Bridge_Pitch2.54mm_Drill1.0mm
TPgnd11: TestPoint; TestPoint_Bridge_Pitch2.54mm_Drill1.0mm
VCELL11: 3.3; BatteryHolder_MPD_BK-18650-PC2

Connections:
0: Q11_1.2 (E), Q11_3.2 (E), QLED11.2 (E), TPgnd11.1; also elsewhere on the board
/celda_11/Vcontrol_neg: R11_6.2; also elsewhere on the board
/celda_11/bus_neg: F11.2; also elsewhere on the board
/celda_11/bus_pos: D11.2 (-), Q11_2.2 (E), R11_2.1, Rout11.1; also elsewhere on the board
/celda_11/cell_neg: S11.3 (S), TPC11.1, VCELL11.2 (-); also elsewhere on the board
/celda_11/gate: D11.1 (+), R11_4.2, R11_5.1, S11.1 (G), TPG11.1; also elsewhere on the board
unnamed: DLED11.1 (K), RLED11_2.1
unnamed: Q11_1.1 (B), R11_1.1
unnamed: Q11_1.3 (C), R11_3.2
unnamed: Q11_2.1 (B), R11_2.2, R11_3.1, TPB11.1
unnamed: Q11_2.3 (C), R11_4.1
unnamed: Q11_3.1 (B), R11_6.1
unnamed: Q11_3.3 (C), R11_5.2
unnamed: QLED11.1 (B), RLED11_1.1
unnamed: QLED11.3 (C), RLED11_2.2
unnamed: F11.1, S11.2 (D)
unnamed: Rout11.2, VCELL11.1 (+)
VCC: DLED11.2 (A); also elsewhere on the board
Vc_11: R11_1.2, RLED11_1.2; also elsewhere on the board

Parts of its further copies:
D12, D21, D22, D31, D32: 1N4736A; D_DO-41_SOD81_P7.62mm_Horizontal
DLED12, DLED21, DLED22, DLED31, DLED32: LED; LED_D5.0mm
F12, F21, F22, F31, F32: Fuse; Fuseholder_Cylinder-5x20mm_Schurter_0031_8201_Horizontal_Op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
Q12_1, Q12_3, Q21_1, Q21_3, Q22_1, Q22_3, Q31_1, Q31_3, Q32_1, Q32_3: MMBT2222A; SOT-23-3
Q12_2, Q21_2, Q22_2, Q31_2, Q32_2: MMBT2907A; SOT-23-3
QLED21, QLED22, QLED31, QLED32: MMBT2222A; SOT-23-3
QLED_12: MMBT2222A; SOT-23-3
R12_1, R12_6, R21_1, R21_6, R22_1, R22_6, R31_1, R31_6, R32_1, R32_6: 20k; R_Axial_DIN0207_L6.3mm_D2.5mm_P7.62mm_Horizontal
R12_2, R21_2, R22_2, R31_2, R32_2: 10Meg; R_Axial_DIN0207_L6.3mm_D2.5mm_P7.62mm_Horizontal
R12_3, R21_3, R22_3, R31_3, R32_3: 1Meg; R_Axial_DIN0207_L6.3mm_D2.5mm_P7.62mm_Horizontal
R12_4, R21_4, R22_4, R31_4, R32_4: 4.7k; R_Axial_DIN0207_L6.3mm_D2.5mm_P7.62mm_Horizontal
R12_5, R21_5, R22_5, R31_5, R32_5: 33k; R_Axial_DIN0207_L6.3mm_D2.5mm_P7.62mm_Horizontal
RLED12_1, RLED21_1, RLED22_1, RLED31_1, RLED32_1: 20k; R_Axial_DIN0207_L6.3mm_D2.5mm_P7.62mm_Horizontal
RLED12_2, RLED21_2, RLED22_2, RLED31_2, RLED32_2: 1k; R_Axial_DIN0207_L6.3mm_D2.5mm_P7.62mm_Horizontal
Rout12, Rout21, Rout22, Rout31, Rout32: 1m; R_Axial_DIN0207_L6.3mm_D2.5mm_P7.62mm_Horizontal
S12, S21, S22, S31, S32: IRLB8721; TO-220-3_Vertical
TPB12, TPB21, TPB22, TPB31, TPB32: TestPoint; TestPoint_Bridge_Pitch2.54mm_Drill1.0mm
TPC12, TPC21, TPC22, TPC31, TPC32: TestPoint; TestPoint_Bridge_Pitch2.54mm_Drill1.0mm
TPG12, TPG21, TPG22, TPG31, TPG32: TestPoint; TestPoint_Bridge_Pitch2.54mm_Drill1.0mm
TPgnd12, TPgnd21, TPgnd22, TPgnd31, TPgnd32: TestPoint; TestPoint_Bridge_Pitch2.54mm_Drill1.0mm
VCELL12, VCELL21, VCELL22, VCELL31, VCELL32: 3.3; BatteryHolder_MPD_BK-18650-PC2

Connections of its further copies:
0: Q12_1.2 (E), Q12_3.2 (E), Q21_1.2 (E), Q21_3.2 (E), Q22_1.2 (E), Q22_3.2 (E), Q31_1.2 (E), Q31_3.2 (E), Q32_1.2 (E), Q32_3.2 (E), QLED21.2 (E), QLED22.2 (E), QLED31.2 (E), QLED32.2 (E), QLED_12.2 (E), TPgnd12.1, TPgnd21.1, TPgnd22.1, TPgnd31.1, TPgnd32.1; also elsewhere on the board
/celda_11/bus_neg: F12.2; also elsewhere on the board
/celda_11/bus_pos: D12.2 (-), F21.2, F22.2, Q12_2.2 (E), R12_2.1, Rout12.1; also elsewhere on the board
/celda_12/Vcontrol_neg: R12_6.2; also elsewhere on the board
/celda_12/cell_neg: S12.3 (S), TPC12.1, VCELL12.2 (-); also elsewhere on the board
/celda_12/gate: D12.1 (+), R12_4.2, R12_5.1, S12.1 (G), TPG12.1; also elsewhere on the board
/celda_21/Vcontrol_neg: R21_6.2; also elsewhere on the board
/celda_21/bus_pos: D21.2 (-), D22.2 (-), F31.2, F32.2, Q21_2.2 (E), Q22_2.2 (E), R21_2.1, R22_2.1, Rout21.1, Rout22.1; also elsewhere on the board
/celda_21/cell_neg: S21.3 (S), TPC21.1, VCELL21.2 (-); also elsewhere on the board
/celda_21/gate: D21.1 (+), R21_4.2, R21_5.1, S21.1 (G), TPG21.1
/celda_22/Vcontrol_neg: R22_6.2; also elsewhere on the board
/celda_22/cell_neg: S22.3 (S), TPC22.1, VCELL22.2 (-); also elsewhere on the board
/celda_22/gate: D22.1 (+), R22_4.2, R22_5.1, S22.1 (G), TPG22.1
/celda_31/Vcontrol_neg: R31_6.2; also elsewhere on the board
/celda_31/bus_pos: D31.2 (-), D32.2 (-), Q31_2.2 (E), Q32_2.2 (E), R31_2.1, R32_2.1, Rout31.1, Rout32.1; also elsewhere on the board
/celda_31/cell_neg: S31.3 (S), TPC31.1, VCELL31.2 (-); also elsewhere on the board
/celda_31/gate: D31.1 (+), R31_4.2, R31_5.1, S31.1 (G), TPG31.1
/celda_32/Vcontrol_neg: R32_6.2; also elsewhere on the board
/celda_32/cell_neg: S32.3 (S), TPC32.1, VCELL32.2 (-); also elsewhere on the board
/celda_32/gate: D32.1 (+), R32_4.2, R32_5.1, S32.1 (G), TPG32.1
unnamed: DLED12.1 (K), RLED12_2.1
unnamed: DLED21.1 (K), RLED21_2.1
unnamed: DLED22.1 (K), RLED22_2.1
unnamed: DLED31.1 (K), RLED31_2.1
unnamed: DLED32.1 (K), RLED32_2.1
unnamed: Q12_1.1 (B), R12_1.1
unnamed: Q12_1.3 (C), R12_3.2
unnamed: Q12_2.1 (B), R12_2.2, R12_3.1, TPB12.1
unnamed: Q12_2.3 (C), R12_4.1
unnamed: Q12_3.1 (B), R12_6.1
unnamed: Q12_3.3 (C), R12_5.2
unnamed: Q21_1.1 (B), R21_1.1
unnamed: Q21_1.3 (C), R21_3.2
unnamed: Q21_2.1 (B), R21_2.2, R21_3.1, TPB21.1
unnamed: Q21_2.3 (C), R21_4.1
unnamed: Q21_3.1 (B), R21_6.1
unnamed: Q21_3.3 (C), R21_5.2
unnamed: Q22_1.1 (B), R22_1.1
unnamed: Q22_1.3 (C), R22_3.2
unnamed: Q22_2.1 (B), R22_2.2, R22_3.1, TPB22.1
unnamed: Q22_2.3 (C), R22_4.1
unnamed: Q22_3.1 (B), R22_6.1
unnamed: Q22_3.3 (C), R22_5.2
unnamed: Q31_1.1 (B), R31_1.1
unnamed: Q31_1.3 (C), R31_3.2
unnamed: Q31_2.1 (B), R31_2.2, R31_3.1, TPB31.1
unnamed: Q31_2.3 (C), R31_4.1
unnamed: Q31_3.1 (B), R31_6.1
unnamed: Q31_3.3 (C), R31_5.2
unnamed: Q32_1.1 (B), R32_1.1
unnamed: Q32_1.3 (C), R32_3.2
unnamed: Q32_2.1 (B), R32_2.2, R32_3.1, TPB32.1
unnamed: Q32_2.3 (C), R32_4.1
unnamed: Q32_3.1 (B), R32_6.1
unnamed: Q32_3.3 (C), R32_5.2
unnamed: QLED21.1 (B), RLED21_1.1
unnamed: QLED21.3 (C), RLED21_2.2
unnamed: QLED22.1 (B), RLED22_1.1
unnamed: QLED22.3 (C), RLED22_2.2
unnamed: QLED31.1 (B), RLED31_1.1
unnamed: QLED31.3 (C), RLED31_2.2
unnamed: QLED32.1 (B), RLED32_1.1
unnamed: QLED32.3 (C), RLED32_2.2
unnamed: QLED_12.1 (B), RLED12_1.1
unnamed: QLED_12.3 (C), RLED12_2.2
unnamed: F12.1, S12.2 (D)
unnamed: F21.1, S21.2 (D)
unnamed: F22.1, S22.2 (D)
unnamed: F31.1, S31.2 (D)
unnamed: F32.1, S32.2 (D)
unnamed: Rout12.2, VCELL12.1 (+)
unnamed: Rout21.2, VCELL21.1 (+)
unnamed: Rout22.2, VCELL22.1 (+)
unnamed: Rout31.2, VCELL31.1 (+)
unnamed: Rout32.2, VCELL32.1 (+)
VCC: DLED12.2 (A), DLED21.2 (A), DLED22.2 (A), DLED31.2 (A), DLED32.2 (A); also elsewhere on the board
Vc_12: R12_1.2, RLED12_1.2; also elsewhere on the board
Vc_21: R21_1.2, RLED21_1.2; also elsewhere on the board
Vc_22: R22_1.2, RLED22_1.2; also elsewhere on the board
Vc_31: R31_1.2, RLED31_1.2; also elsewhere on the board
Vc_32: R32_1.2, RLED32_1.2; also elsewhere on the board

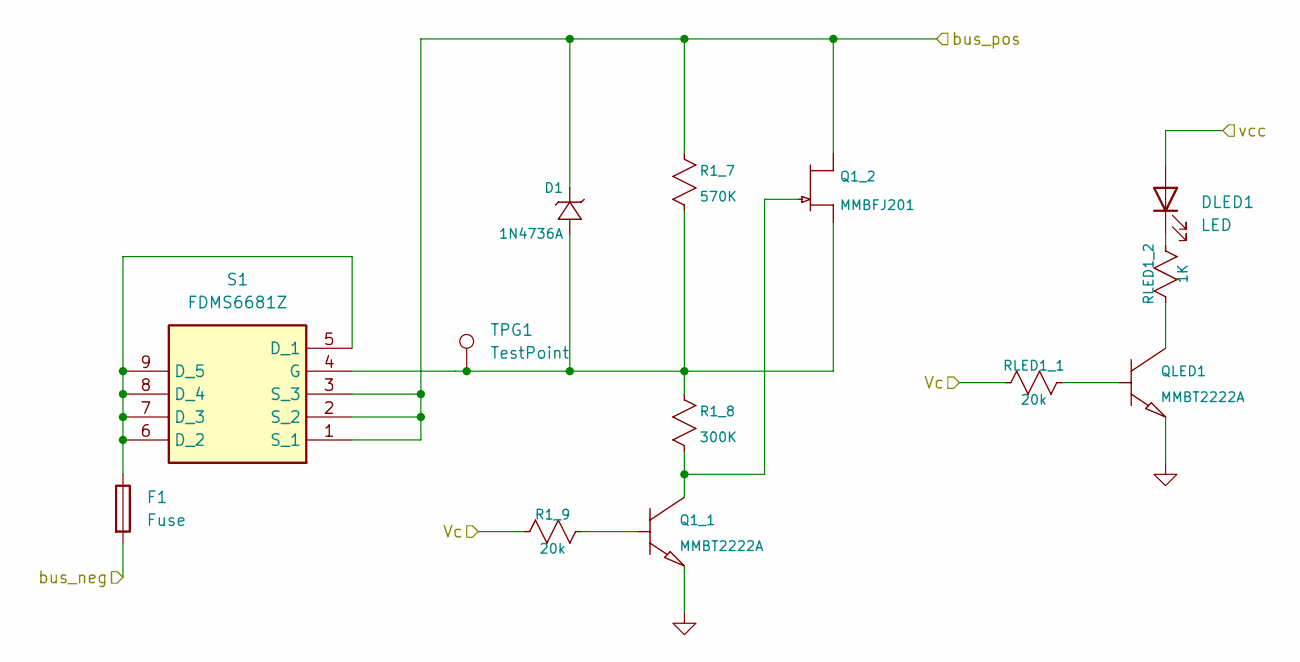
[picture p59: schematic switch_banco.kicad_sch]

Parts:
D1: 1N4736A; D_DO-41_SOD81_P7.62mm_Horizontal
DLED1: LED; LED_D5.0mm
F1: Fuse; Fuseholder_Cylinder-5x20mm_Schurter_0031_8201_Horizontal_Op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
Q1_1: MMBT2222A; SOT-23-3
Q1_2: MMBFJ201; SOT-23-3
QLED1: MMBT2222A; SOT-23-3
R1_7: 570K; R_Axial_DIN0207_L6.3mm_D2.5mm_P7.62mm_Horizontal
R1_8: 300K; R_Axial_DIN0207_L6.3mm_D2.5mm_P7.62mm_Horizontal
R1_9: 20k; R_Axial_DIN0207_L6.3mm_D2.5mm_P7.62mm_Horizontal
RLED1_1: 20k; R_Axial_DIN0207_L6.3mm_D2.5mm_P7.62mm_Horizontal
RLED1_2: 1K; R_Axial_DIN0207_L6.3mm_D2.5mm_P7.62mm_Horizontal
S1: FDMS6681Z; Mouser Part Number 512-FDMS6681Z
TPG1: TestPoint; TestPoint_Bridge_Pitch2.54mm_Drill1.0mm

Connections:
0: Q1_1.2 (E), QLED1.2 (E); also elsewhere on the board
/celda_11/bus_neg: F1.2; also elsewhere on the board
/celda_11/bus_pos: D1.2 (-), Q1_2.1 (D), R1_7.1, S1.1 (S_1), S1.2 (S_2), S1.3 (S_3); also elsewhere on the board
unnamed: D1.1 (+), Q1_2.3 (S), R1_7.2, R1_8.1, S1.4 (G), TPG1.1
unnamed: DLED1.1 (K), RLED1_2.1
unnamed: Q1_1.1 (B), R1_9.1
unnamed: Q1_1.3 (C), Q1_2.2 (G), R1_8.2
unnamed: QLED1.1 (B), RLED1_1.1
unnamed: QLED1.3 (C), RLED1_2.2
unnamed: F1.1, S1.5 (D_1), S1.6 (D_2), S1.7 (D_3), S1.8 (D_4), S1.9 (D_5)
VCC: DLED1.2 (A); also elsewhere on the board
Vc1: R1_9.2, RLED1_1.2; also elsewhere on the board

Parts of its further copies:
D2, D3: 1N4736A; D_DO-41_SOD81_P7.62mm_Horizontal
DLED2, DLED3: LED; LED_D5.0mm
F2, F3: Fuse; Fuseholder_Cylinder-5x20mm_Schurter_0031_8201_Horizontal_Op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
Q2_1, Q3_1: MMBT2222A; SOT-23-3
Q2_2, Q3_2: MMBFJ201; SOT-23-3
QLED2, QLED3: MMBT2222A; SOT-23-3
R2_7, R3_7: 570K; R_Axial_DIN0207_L6.3mm_D2.5mm_P7.62mm_Horizontal
R2_8, R3_8: 300K; R_Axial_DIN0207_L6.3mm_D2.5mm_P7.62mm_Horizontal
R2_9, R3_9: 20k; R_Axial_DIN0207_L6.3mm_D2.5mm_P7.62mm_Horizontal
RLED2_1, RLED3_1: 20k; R_Axial_DIN0207_L6.3mm_D2.5mm_P7.62mm_Horizontal
RLED2_2, RLED3_2: 1K; R_Axial_DIN0207_L6.3mm_D2.5mm_P7.62mm_Horizontal
S2, S3: FDMS6681Z; Mouser Part Number 512-FDMS6681Z
TPG2, TPG3: TestPoint; TestPoint_Bridge_Pitch2.54mm_Drill1.0mm

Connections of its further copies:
0: Q2_1.2 (E), Q3_1.2 (E), QLED2.2 (E), QLED3.2 (E); also elsewhere on the board
/celda_11/bus_pos: F2.2; also elsewhere on the board
/celda_21/bus_pos: D2.2 (-), F3.2, Q2_2.1 (D), R2_7.1, S2.1 (S_1), S2.2 (S_2), S2.3 (S_3); also elsewhere on the board
/celda_31/bus_pos: D3.2 (-), Q3_2.1 (D), R3_7.1, S3.1 (S_1), S3.2 (S_2), S3.3 (S_3); also elsewhere on the board
unnamed: D2.1 (+), Q2_2.3 (S), R2_7.2, R2_8.1, S2.4 (G), TPG2.1
unnamed: D3.1 (+), Q3_2.3 (S), R3_7.2, R3_8.1, S3.4 (G), TPG3.1
unnamed: DLED2.1 (K), RLED2_2.1
unnamed: DLED3.1 (K), RLED3_2.1
unnamed: Q2_1.1 (B), R2_9.1
unnamed: Q2_1.3 (C), Q2_2.2 (G), R2_8.2
unnamed: Q3_1.1 (B), R3_9.1
unnamed: Q3_1.3 (C), Q3_2.2 (G), R3_8.2
unnamed: QLED2.1 (B), RLED2_1.1
unnamed: QLED2.3 (C), RLED2_2.2
unnamed: QLED3.1 (B), RLED3_1.1
unnamed: QLED3.3 (C), RLED3_2.2
unnamed: F2.1, S2.5 (D_1), S2.6 (D_2), S2.7 (D_3), S2.8 (D_4), S2.9 (D_5)
unnamed: F3.1, S3.5 (D_1), S3.6 (D_2), S3.7 (D_3), S3.8 (D_4), S3.9 (D_5)
VCC: DLED2.2 (A), DLED3.2 (A); also elsewhere on the board
Vc2: R2_9.2, RLED2_1.2; also elsewhere on the board
Vc3: R3_9.2, RLED3_1.2; also elsewhere on the board

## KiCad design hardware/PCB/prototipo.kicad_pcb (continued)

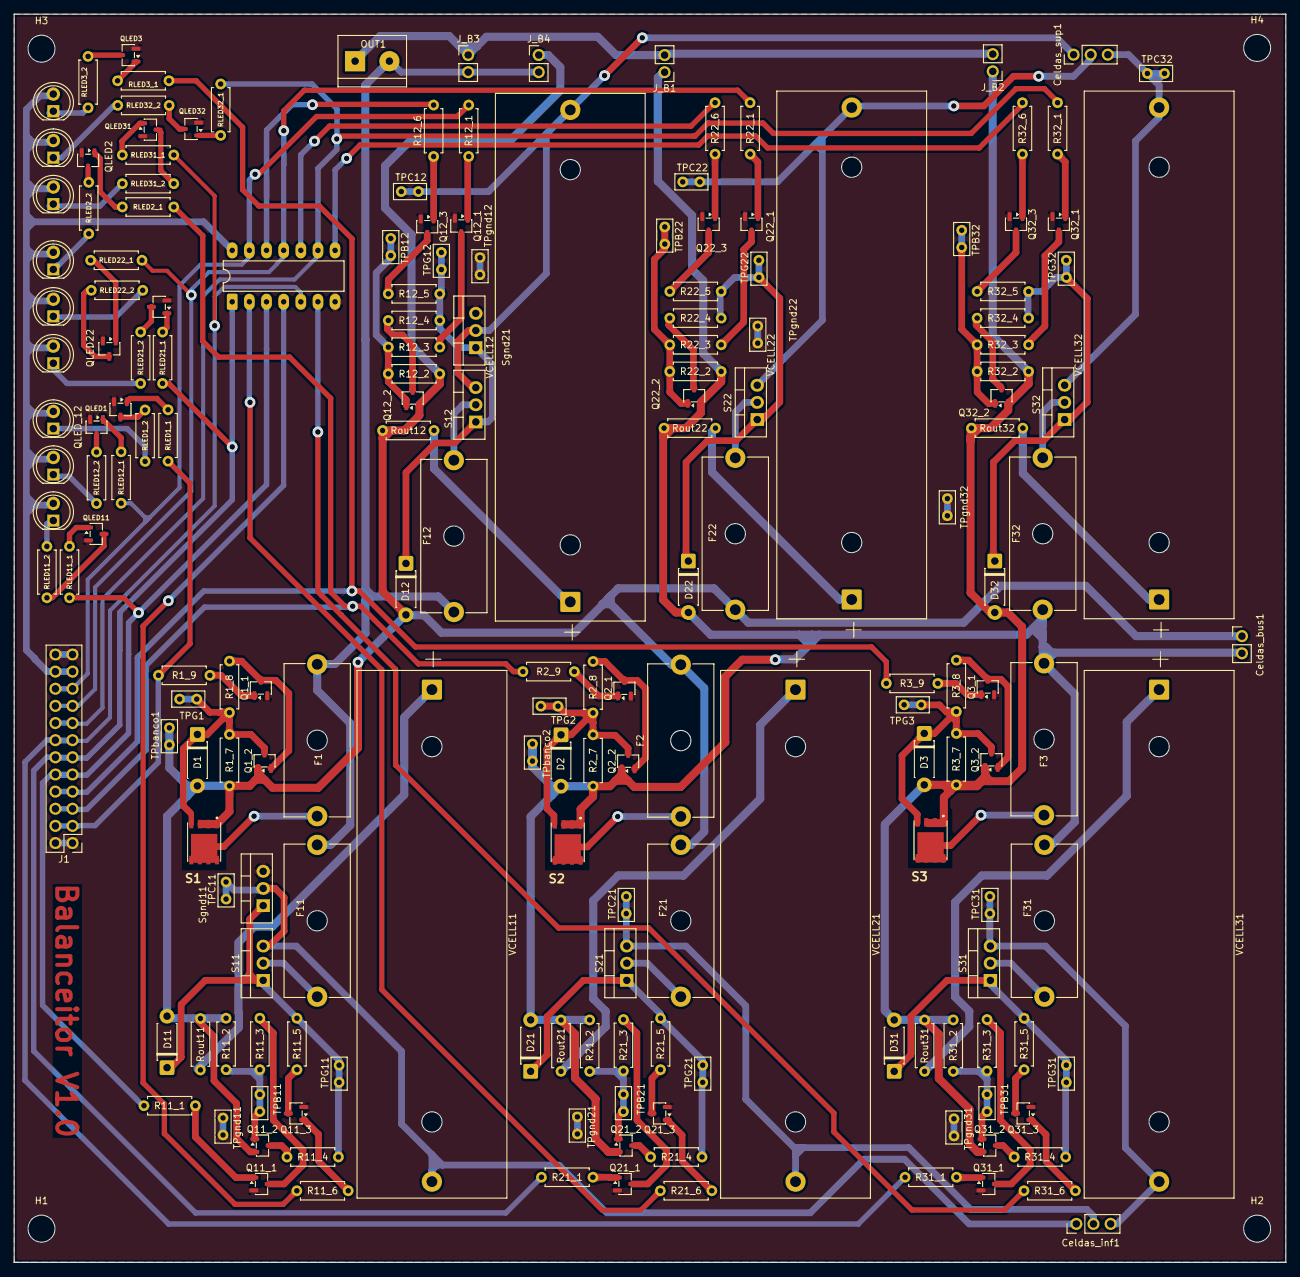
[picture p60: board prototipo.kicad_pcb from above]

Board: 2 copper layers, 188.4 x 185.0 mm, 189 parts (0 on the bottom side), 121 nets.

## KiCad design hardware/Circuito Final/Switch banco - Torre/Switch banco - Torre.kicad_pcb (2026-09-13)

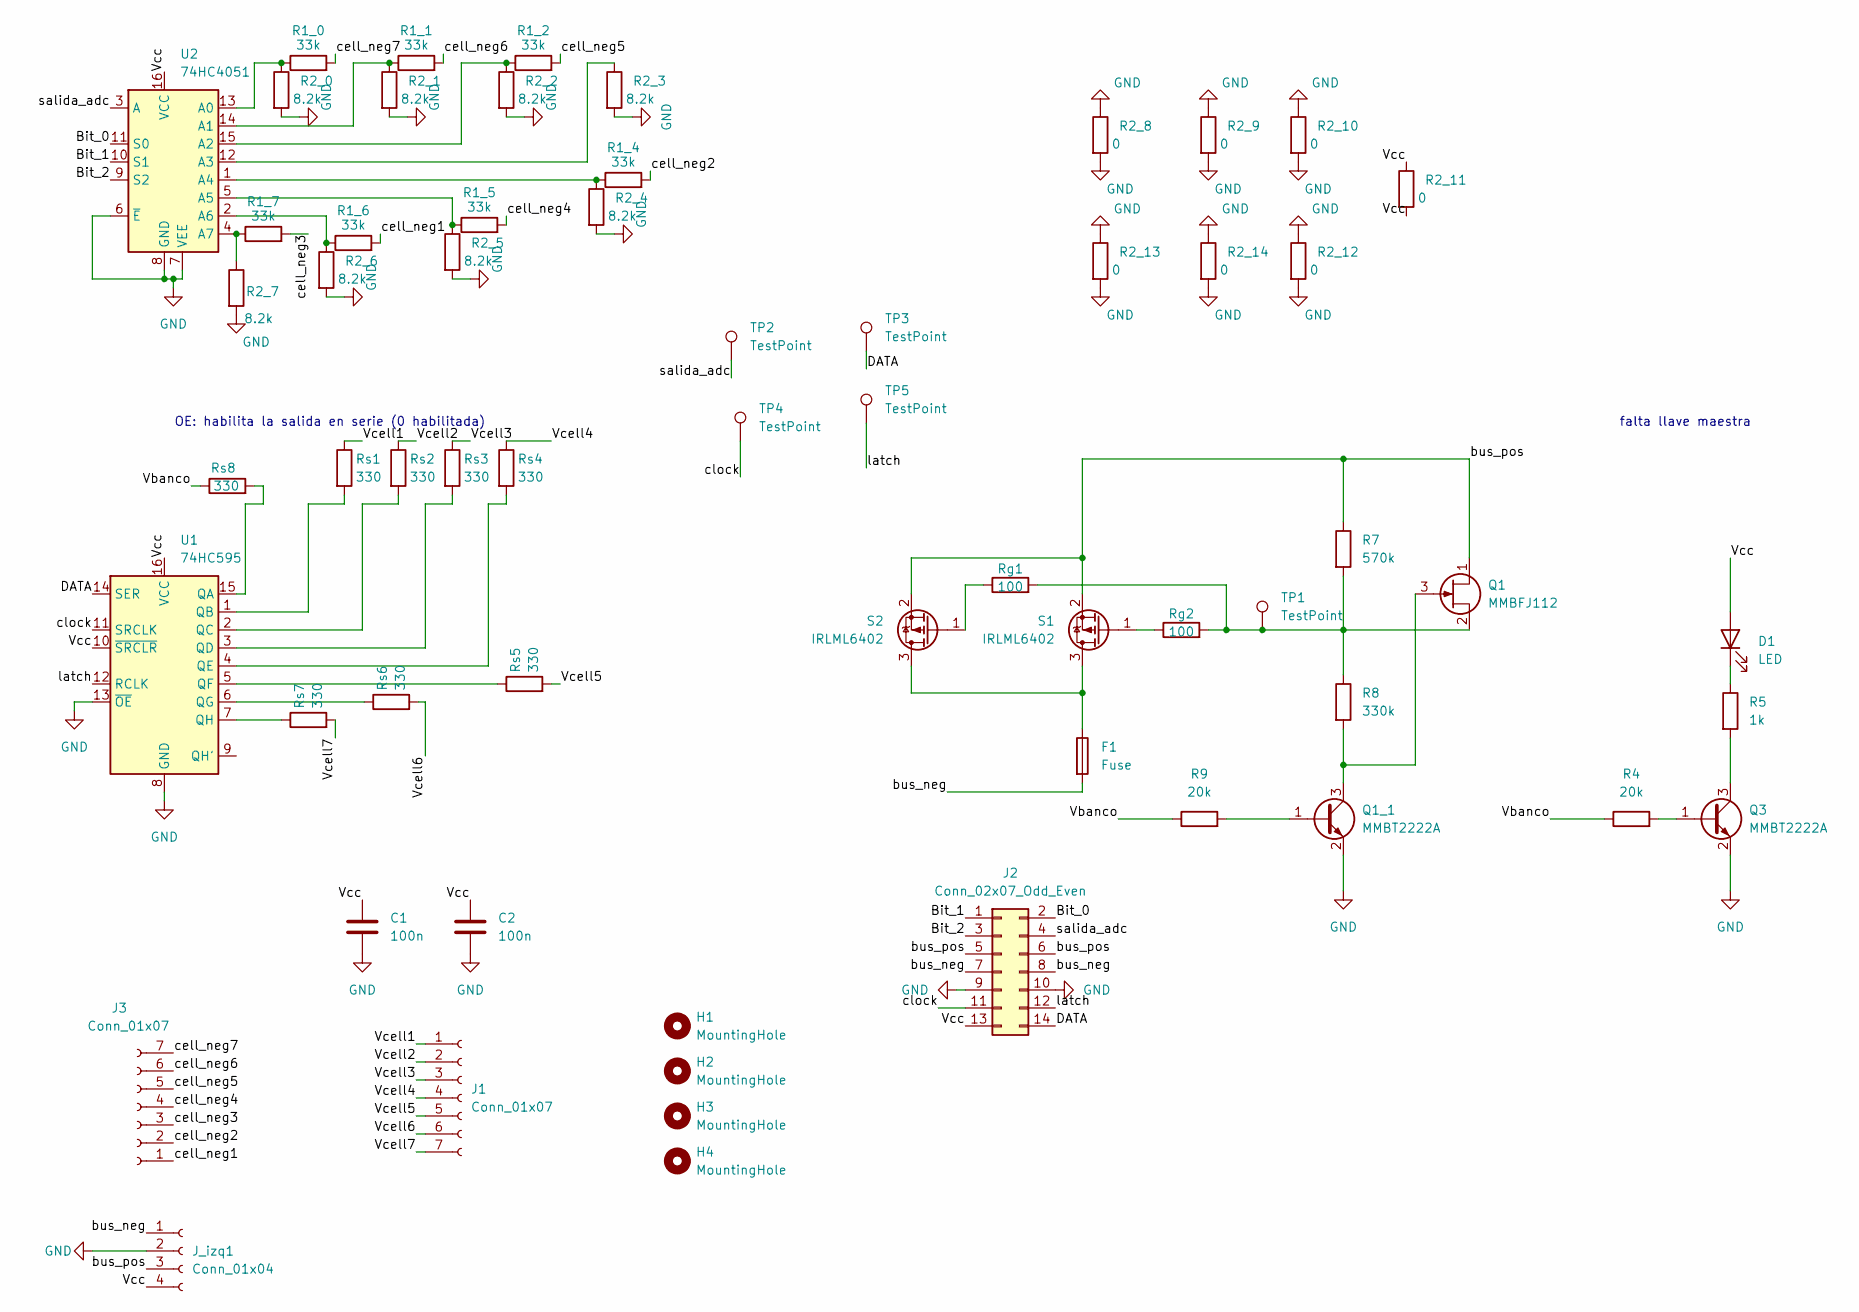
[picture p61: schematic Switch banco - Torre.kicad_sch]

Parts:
C1, C2: 100n; C_1206_3216Metric_Pad1.33x1.80mm_HandSolder
D1: LED; LED_D5.0mm
F1: Fuse; Fuse_1206_3216Metric_Pad1.42x1.75mm_HandSolder
H1, H2, H3, H4: MountingHole; MountingHole_3.5mm
J1, J3: Conn_01x07; PinSocket_1x07_P2.54mm_Vertical
J2: Conn_02x07_Odd_Even; IDC-Header_2x07_P2.54mm_Horizontal
J_izq1: Conn_01x04; PinSocket_1x04_P2.54mm_Vertical
Q1: MMBFJ112; SOT-23_Handsoldering
Q1_1, Q3: MMBT2222A; SOT-23_Handsoldering
R1_0, R1_1, R1_2, R1_4, R1_5, R1_6, R1_7: 33k; R_1206_3216Metric_Pad1.30x1.75mm_HandSolder
R2_0, R2_1, R2_2, R2_3, R2_4, R2_5, R2_6, R2_7: 8.2k; R_1206_3216Metric_Pad1.30x1.75mm_HandSolder
R2_8, R2_9, R2_10, R2_11, R2_12, R2_13, R2_14: 0; R_1206_3216Metric_Pad1.30x1.75mm_HandSolder
R4, R9: 20k; R_1206_3216Metric_Pad1.30x1.75mm_HandSolder
R5: 1k; R_1206_3216Metric_Pad1.30x1.75mm_HandSolder
R7: 570k; R_1206_3216Metric_Pad1.30x1.75mm_HandSolder
R8: 330k; R_1206_3216Metric_Pad1.30x1.75mm_HandSolder
Rg1, Rg2: 100; R_1206_3216Metric_Pad1.30x1.75mm_HandSolder
Rs1, Rs2, Rs3, Rs4, Rs5, Rs6, Rs7, Rs8: 330; R_1206_3216Metric_Pad1.30x1.75mm_HandSolder
S1, S2: IRLML6402; SOT-23_Handsoldering
TP1, TP2, TP3, TP4, TP5: TestPoint; TestPoint_Loop_D2.54mm_Drill1.5mm_Beaded
U1: 74HC595; SOIC-16_3.9x9.9mm_P1.27mm
U2: 74HC4051; SOIC-16_3.9x9.9mm_P1.27mm

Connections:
/Bit_0: J2.2, U2.11 (S0)
/Bit_1: J2.1, U2.10 (S1)
/Bit_2: J2.3, U2.9 (S2)
/DATA: J2.14, TP3.1 (1_1), U1.14 (SER)
/Vbanco: R4.1, R9.1, Rs8.1
/Vcc: C1.1, C2.1, D1.2 (A), J2.13, J_izq1.4, R2_11.1, R2_11.2, U1.10 (~SRCLR), U1.16 (VCC), U2.16 (VCC)
/Vcell1: J1.1, Rs1.1
/Vcell2: J1.2, Rs2.1
/Vcell3: J1.3, Rs3.1
/Vcell4: J1.4, Rs4.1
/Vcell5: J1.5, Rs5.2
/Vcell6: J1.6, Rs6.2
/Vcell7: J1.7, Rs7.2
/bus_neg: F1.2, J2.7, J2.8, J_izq1.1
/bus_pos: J2.5, J2.6, J_izq1.3, Q1.1 (D), R7.1, S1.2 (S), S2.2 (S)
/cell_neg1: J3.1, R1_6.2
/cell_neg2: J3.2, R1_4.2
/cell_neg3: J3.3, R1_7.2
/cell_neg4: J3.4, R1_5.2
/cell_neg5: J3.5, R1_2.2
/cell_neg6: J3.6, R1_1.2
/cell_neg7: J3.7, R1_0.2
/clock: J2.11, TP4.1 (1_1), U1.11 (SRCLK)
/latch: J2.12, TP5.1 (1_1), U1.12 (RCLK)
/salida_adc: J2.4, TP2.1 (1_1), U2.3 (A)
GND: C1.2, C2.2, J2.9, J2.10, J_izq1.2, Q1_1.2 (E), Q3.2 (E), R2_0.2, R2_1.2, R2_2.2, R2_3.2, R2_4.2, R2_5.2, R2_6.2, R2_7.2, R2_8.1, R2_8.2, R2_9.1, R2_9.2, R2_10.1, R2_10.2, R2_12.1, R2_12.2, R2_13.1, R2_13.2, R2_14.1, R2_14.2, U1.8 (GND), U1.13 (~OE), U2.6 (~E), U2.7 (VEE), U2.8 (GND)
unnamed: D1.1 (K), R5.1
unnamed: Q1.3 (G), Q1_1.3 (C), R8.2
unnamed: Q1.2 (S), R7.2, R8.1, Rg1.2, Rg2.2, TP1.1 (1_1)
unnamed: Q1_1.1 (B), R9.2
unnamed: Q3.1 (B), R4.2
unnamed: Q3.3 (C), R5.2
unnamed: F1.1, S1.3 (D), S2.3 (D)
unnamed: Rg2.1, S1.1 (G)
unnamed: Rg1.1, S2.1 (G)
unnamed: Rs8.2, U1.15 (QA)
unnamed: Rs1.2, U1.1 (QB)
unnamed: Rs2.2, U1.2 (QC)
unnamed: Rs3.2, U1.3 (QD)
unnamed: Rs4.2, U1.4 (QE)
unnamed: Rs5.1, U1.5 (QF)
unnamed: Rs6.1, U1.6 (QG)
unnamed: Rs7.1, U1.7 (QH)
unnamed: R1_0.1, R2_0.1, U2.13 (A0)
unnamed: R1_1.1, R2_1.1, U2.14 (A1)
unnamed: R1_2.1, R2_2.1, U2.15 (A2)
unnamed: R2_3.1, U2.12 (A3)
unnamed: R1_4.1, R2_4.1, U2.1 (A4)
unnamed: R1_5.1, R2_5.1, U2.5 (A5)
unnamed: R1_6.1, R2_6.1, U2.2 (A6)
unnamed: R1_7.1, R2_7.1, U2.4 (A7)

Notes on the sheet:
falta llave maestra
OE: habilita la salida en serie (0 habilitada)

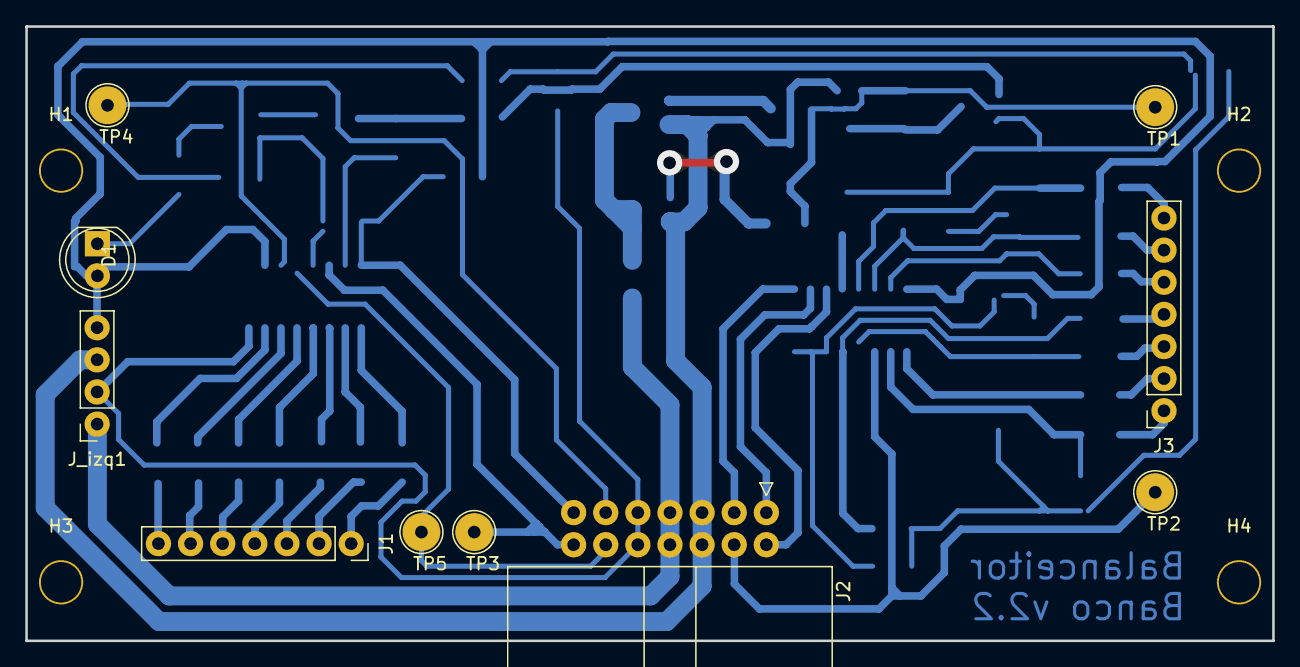
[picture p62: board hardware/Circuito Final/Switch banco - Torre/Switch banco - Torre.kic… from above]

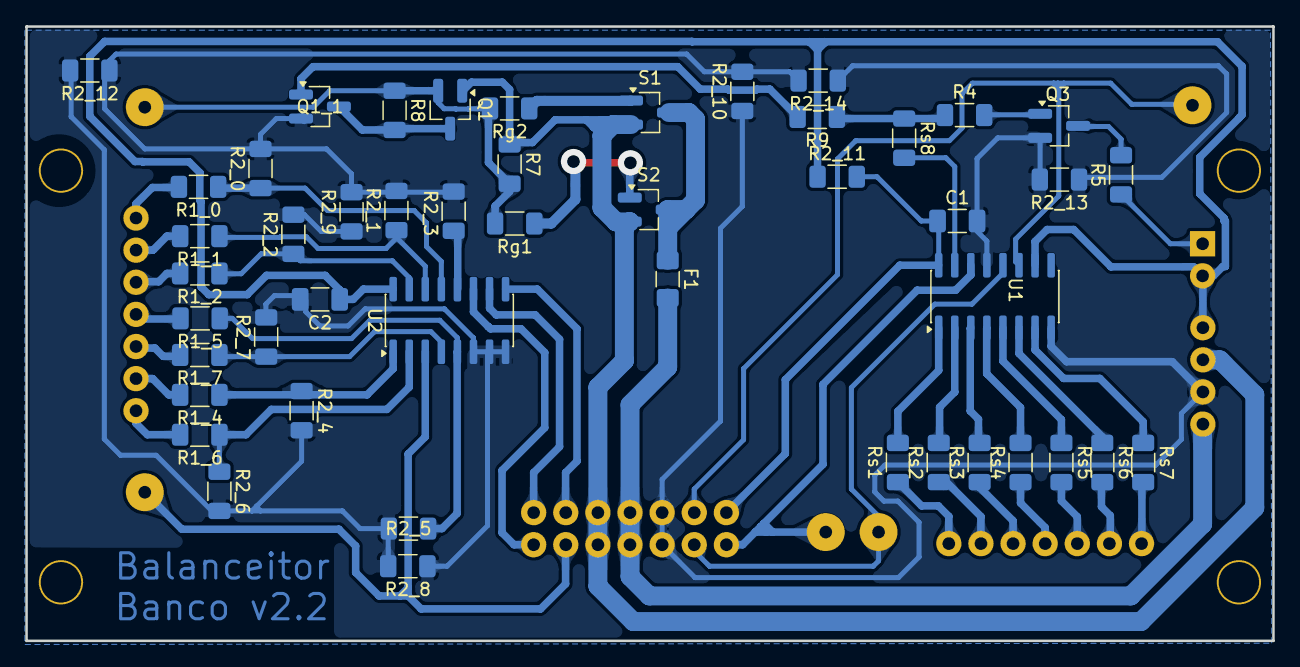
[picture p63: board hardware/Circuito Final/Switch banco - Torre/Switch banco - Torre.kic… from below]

Board: 2 copper layers, 98.6 x 48.6 mm, 61 parts (47 on the bottom side), 51 nets.

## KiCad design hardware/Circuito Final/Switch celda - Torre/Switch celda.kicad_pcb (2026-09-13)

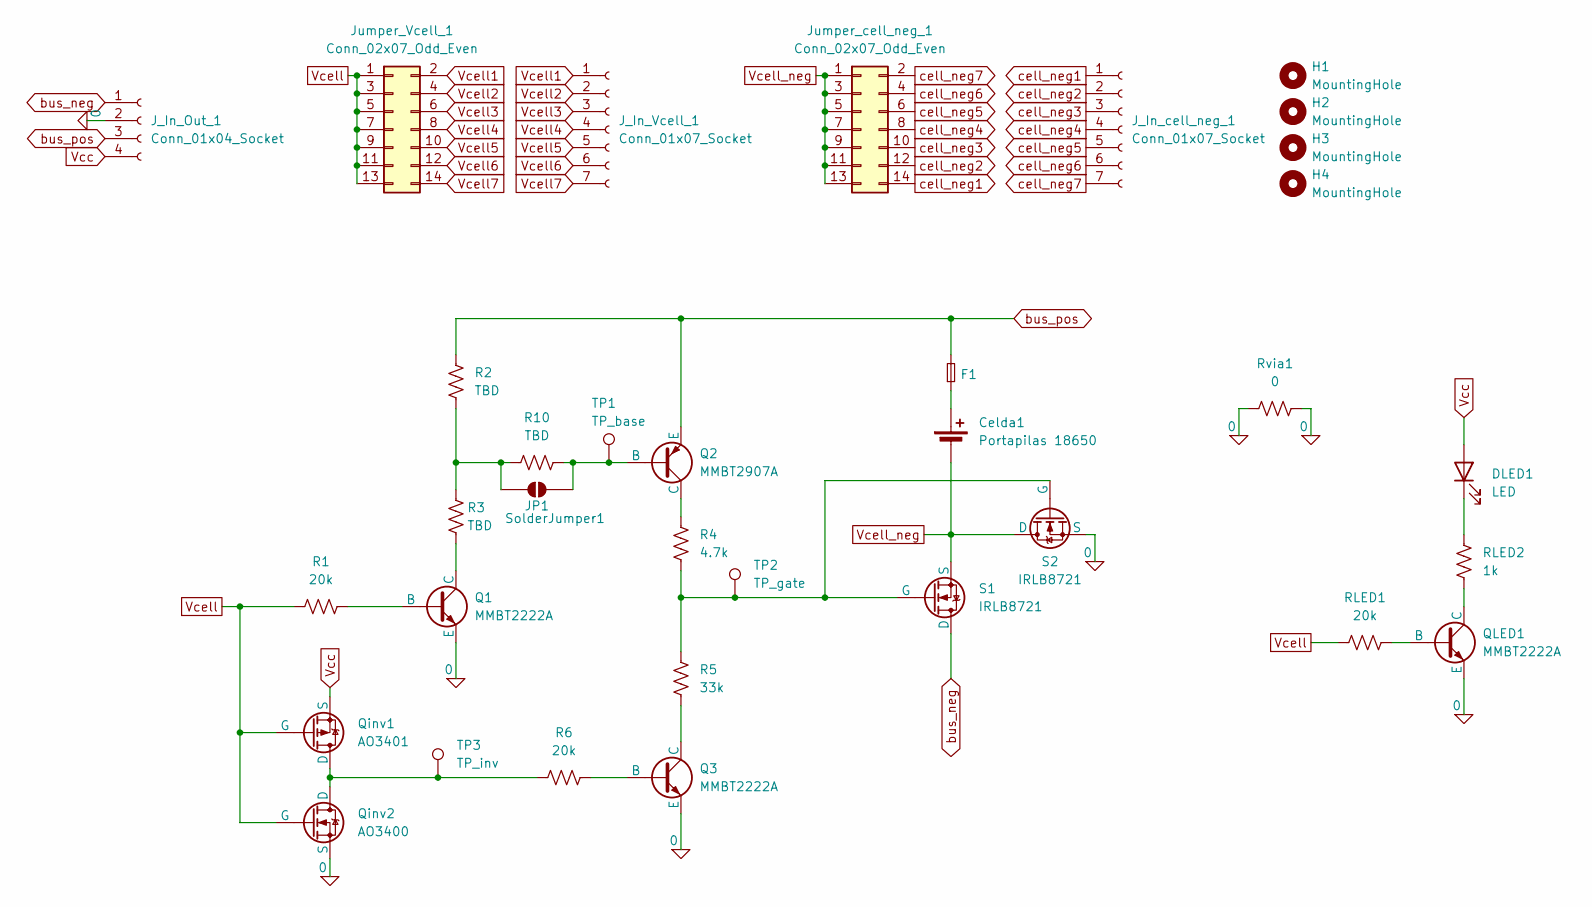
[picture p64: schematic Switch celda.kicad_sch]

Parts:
Celda1: Portapilas 18650; BatteryHolder_MPD_BK-18650-PC2
DLED1: LED; LED_D5.0mm
F1: Fuse_1206_3216Metric_Pad1.42x1.75mm_HandSolder
H1, H2, H3, H4: MountingHole; MountingHole_3.5mm
JP1: SolderJumper1; SolderJumper-2_P1.3mm_Open_TrianglePad1.0x1.5mm
J_In_Out_1: Conn_01x04_Socket; PinSocket_1x04_P2.54mm_Vertical
J_In_Vcell_1: Conn_01x07_Socket; PinSocket_1x07_P2.54mm_Vertical
J_In_cell_neg_1: Conn_01x07_Socket; PinSocket_1x07_P2.54mm_Vertical
Jumper_Vcell_1: Conn_02x07_Odd_Even; PinHeader_2x07_P2.54mm_Vertical
Jumper_cell_neg_1: Conn_02x07_Odd_Even; PinHeader_2x07_P2.54mm_Vertical
Q1, Q3: MMBT2222A; SOT-23_Handsoldering
Q2: MMBT2907A; SOT-23_Handsoldering
QLED1: MMBT2222A; SOT-23_Handsoldering
Qinv1: AO3401; SOT-23_Handsoldering
Qinv2: AO3400; SOT-23_Handsoldering
R1, R6: 20k; R_1206_3216Metric_Pad1.30x1.75mm_HandSolder
R2, R3, R10: TBD; R_1206_3216Metric_Pad1.30x1.75mm_HandSolder
R4: 4.7k; R_1206_3216Metric_Pad1.30x1.75mm_HandSolder
R5: 33k; R_1206_3216Metric_Pad1.30x1.75mm_HandSolder
RLED1: 20k; R_1206_3216Metric_Pad1.30x1.75mm_HandSolder
RLED2: 1k; R_1206_3216Metric_Pad1.30x1.75mm_HandSolder
Rvia1: 0; R_1206_3216Metric_Pad1.30x1.75mm_HandSolder
S1, S2: IRLB8721; TO-220-3_Vertical
TP1: TP_base; TestPoint_Loop_D2.54mm_Drill1.5mm_Beaded
TP2: TP_gate; TestPoint_Loop_D2.54mm_Drill1.5mm_Beaded
TP3: TP_inv; TestPoint_Loop_D2.54mm_Drill1.5mm_Beaded

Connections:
0: J_In_Out_1.2, Q1.3 (E), Q3.3 (E), QLED1.3 (E), Qinv2.3 (S), Rvia1.1, Rvia1.2, S2.3 (S)
unnamed: Celda1.1 (+), F1.1
unnamed: DLED1.1 (K), RLED2.2
unnamed: JP1.1 (A), R2.1, R3.2, R10.1
unnamed: JP1.2 (B), Q2.2 (B), R10.2, TP1.1 (1_1)
unnamed: Q1.2 (B), R1.2
unnamed: Q1.1 (C), R3.1
unnamed: Q2.1 (C), R4.2
unnamed: Q3.2 (B), R6.2
unnamed: Q3.1 (C), R5.1
unnamed: QLED1.2 (B), RLED1.2
unnamed: QLED1.1 (C), RLED2.1
unnamed: Qinv1.1 (D), Qinv2.1 (D), R6.1, TP3.1 (1_1)
unnamed: R4.1, R5.2, S1.2 (G), S2.2 (G), TP2.1 (1_1)
Vcc: DLED1.2 (A), J_In_Out_1.4, Qinv1.3 (S)
Vcell: Jumper_Vcell_1.1, Jumper_Vcell_1.3, Jumper_Vcell_1.5, Jumper_Vcell_1.7, Jumper_Vcell_1.9, Jumper_Vcell_1.11, Jumper_Vcell_1.13, Qinv1.2 (G), Qinv2.2 (G), R1.1, RLED1.1
Vcell1: J_In_Vcell_1.1, Jumper_Vcell_1.2
Vcell2: J_In_Vcell_1.2, Jumper_Vcell_1.4
Vcell3: J_In_Vcell_1.3, Jumper_Vcell_1.6
Vcell4: J_In_Vcell_1.4, Jumper_Vcell_1.8
Vcell5: J_In_Vcell_1.5, Jumper_Vcell_1.10
Vcell6: J_In_Vcell_1.6, Jumper_Vcell_1.12
Vcell7: J_In_Vcell_1.7, Jumper_Vcell_1.14
Vcell_neg: Celda1.2 (-), Jumper_cell_neg_1.1, Jumper_cell_neg_1.3, Jumper_cell_neg_1.5, Jumper_cell_neg_1.7, Jumper_cell_neg_1.9, Jumper_cell_neg_1.11, Jumper_cell_neg_1.13, S1.3 (S), S2.1 (D)
bus_neg: J_In_Out_1.1, S1.1 (D)
bus_pos: F1.2, J_In_Out_1.3, Q2.3 (E), R2.2
cell_neg1: J_In_cell_neg_1.1, Jumper_cell_neg_1.14
cell_neg2: J_In_cell_neg_1.2, Jumper_cell_neg_1.12
cell_neg3: J_In_cell_neg_1.3, Jumper_cell_neg_1.10
cell_neg4: J_In_cell_neg_1.4, Jumper_cell_neg_1.8
cell_neg5: J_In_cell_neg_1.5, Jumper_cell_neg_1.6
cell_neg6: J_In_cell_neg_1.6, Jumper_cell_neg_1.4
cell_neg7: J_In_cell_neg_1.7, Jumper_cell_neg_1.2

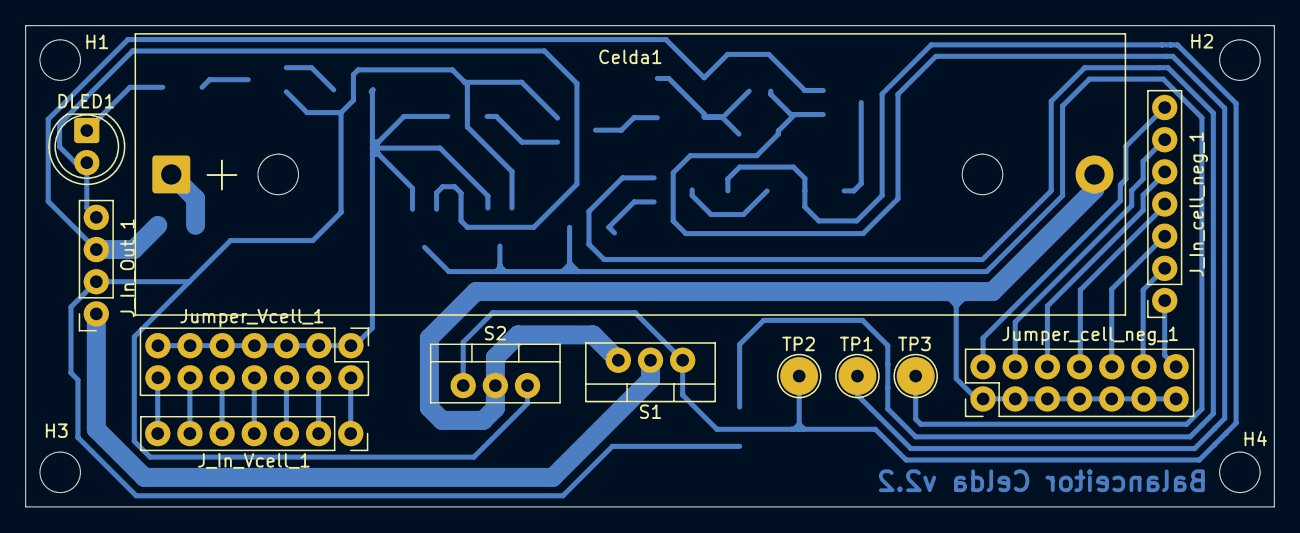
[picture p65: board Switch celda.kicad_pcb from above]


Board: 2 copper layers, 98.6 x 38.0 mm, 34 parts (18 on the bottom side), 33 nets.

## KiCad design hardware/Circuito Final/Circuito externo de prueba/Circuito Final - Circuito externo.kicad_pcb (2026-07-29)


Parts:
H1, H2: MountingHole; MountingHole_3mm
J1, J2: Conn_02x19_Odd_Even; PinSocket_2x19_P2.54mm_Vertical
J3, J4: Conn_01x02; PinSocket_1x02_P2.54mm_Vertical
J5: Conn_01x02_Socket; TerminalBlock_MaiXu_MX126-5.0-02P_1x02_P5.00mm
J6: Conn_01x03_Pin; PinHeader_1x03_P2.54mm_Vertical
J7, J8: Conn_01x01; PinHeader_1x01_P2.54mm_Vertical
Jsalida_1, Jsalida_2: Conn_02x07_Odd_Even; PinHeader_2x07_P2.54mm_Vertical
R1, R2, R3, R4, R5: 0; R_1206_3216Metric_Pad1.30x1.75mm_HandSolder
SW1: SW_DIP_x04; SW_DIP_SPSTx04_Slide_9.78x12.34mm_W7.62mm_P2.54mm
SW4: SW_DIP_x01; SW_DIP_SPSTx01_Slide_9.78x4.72mm_W7.62mm_P2.54mm

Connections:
/Data_1: J1.1, Jsalida_1.13, R2.1, R2.2
/Data_2: J1.3, Jsalida_2.13
/Vcc: J6.2, Jsalida_1.14, Jsalida_2.14, R3.1, R3.2, R5.1, R5.2
/Vcc_externo: J6.1, J7.1 (Pin_1_1)
/Vcc_placa: J1.17, J6.3, R4.1, R4.2
/bus_neg_1: Jsalida_1.7, Jsalida_1.8, SW1.4
/bus_neg_2: Jsalida_2.7, Jsalida_2.8, SW1.2, SW4.2
/bus_neg_salida: J5.1, SW1.5, SW1.7
/bus_pos_1: Jsalida_1.5, Jsalida_1.6, SW1.3, SW4.1
/bus_pos_2: Jsalida_2.5, Jsalida_2.6, SW1.1
/bus_pos_salida: J5.2, SW1.6, SW1.8
/clk_latch: J1.4, Jsalida_1.11, Jsalida_2.11
/clk_shift: J1.2, Jsalida_1.12, Jsalida_2.12, R1.1, R1.2
GND: J3.2 (Pin_2_2), J8.1 (Pin_1_1), Jsalida_1.9, Jsalida_1.10, Jsalida_2.9, Jsalida_2.10



Board: 2 copper layers, 43.5 x 88.1 mm, 20 parts (5 on the bottom side), 14 nets.

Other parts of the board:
STM32: STM32

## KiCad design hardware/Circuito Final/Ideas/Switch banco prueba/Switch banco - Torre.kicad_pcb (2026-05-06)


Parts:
J1: Conn_01x04_Socket; PinSocket_1x04_P2.54mm_Vertical
Q1: MMBFJ112; SOT-23
Q1_1: MMBT2222A; SOT-23
R1_7: 570k; R_1206_3216Metric_Pad1.30x1.75mm_HandSolder
R1_8: 330k; R_1206_3216Metric_Pad1.30x1.75mm_HandSolder
R1_9: 20k; R_1206_3216Metric_Pad1.30x1.75mm_HandSolder
R1_10: 0; R_1206_3216Metric_Pad1.30x1.75mm_HandSolder
S1, S2: IRLML6402; SOT-23

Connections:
/bus_neg: J1.2, S1.3 (D), S2.3 (D)
/bus_pos: J1.1, Q1.1 (D), R1_7.1, S1.2 (S), S2.2 (S)
/gate: Q1.2 (S), R1_7.2, R1_8.1, R1_10.1, R1_10.2, S1.1 (G), S2.1 (G)
/v_control: J1.3, R1_9.1
GND: J1.4, Q1_1.2 (E)
unnamed: Q1.3 (G), Q1_1.3 (C), R1_8.2
unnamed: Q1_1.1 (B), R1_9.2



Board: 2 copper layers, 24.5 x 20.0 mm, 9 parts (8 on the bottom side), 7 nets.

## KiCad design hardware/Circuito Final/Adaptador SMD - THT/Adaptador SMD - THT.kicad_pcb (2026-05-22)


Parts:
J1, J2: Conn_01x08_Pin; PinHeader_1x08_P2.54mm_Vertical
U1: 74HC595; SOIC-16_3.9x9.9mm_P1.27mm

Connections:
unnamed: J1.1, U1.9 (QH')
unnamed: J1.2, U1.10 (~SRCLR)
unnamed: J1.3, U1.11 (SRCLK)
unnamed: J1.4, U1.12 (RCLK)
unnamed: J1.5, U1.13 (~OE)
unnamed: J1.6, U1.14 (SER)
unnamed: J1.7, U1.15 (QA)
unnamed: J1.8, U1.16 (VCC)
unnamed: J2.1, U1.1 (QB)
unnamed: J2.2, U1.2 (QC)
unnamed: J2.3, U1.3 (QD)
unnamed: J2.4, U1.4 (QE)
unnamed: J2.5, U1.5 (QF)
unnamed: J2.6, U1.6 (QG)
unnamed: J2.7, U1.7 (QH)
unnamed: J2.8, U1.8 (GND)


Board: 2 copper layers, 20.0 x 22.0 mm, 3 parts (1 on the bottom side), 16 nets.

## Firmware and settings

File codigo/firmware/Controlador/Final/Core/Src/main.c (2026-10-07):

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
/* Includes ------------------------------------------------------------------*/
#include "main.h"

/* USER CODE BEGIN Includes */
#include "controlador.h"
#include "cli.h"
#include "adc.h"
/* USER CODE END Includes */

ADC_HandleTypeDef hadc1;
DMA_HandleTypeDef hdma_adc1;

UART_HandleTypeDef huart2;

/* USER CODE BEGIN PV */
extern volatile uint8_t flag_controlador_update;

/* USER CODE END PV */

void SystemClock_Config(void);
static void MX_GPIO_Init(void);
static void MX_DMA_Init(void);
static void MX_USART2_UART_Init(void);
static void MX_ADC1_Init(void);
/**
  * @brief  The application entry point.
  * @retval int
  */
int main(void)
{

  /* MCU Configuration--------------------------------------------------------*/

  /* Reset of all peripherals, Initializes the Flash interface and the Systick. */
  HAL_Init();

  /* Configure the system clock */
  SystemClock_Config();

  /* Initialize all configured peripherals */
  MX_GPIO_Init();
  MX_DMA_Init();
  MX_USART2_UART_Init();
  MX_ADC1_Init();
  /* USER CODE BEGIN 2 */
  /* La matriz se configura desde el CLI con init <bancos> <celdas>. */
  CLI_Init(&huart2);
  adc_init();

  /* USER CODE END 2 */

  /* Infinite loop */
  /* USER CODE BEGIN WHILE */
  //Controlador_IniciarSwitchingCelda(0,1,'s');

  while (1)
  {

	  //Controlador_EncenderCelda(0,0);
	   CLI_Process();

	    if (flag_controlador_update) {
	        flag_controlador_update = 0;
	        Controlador_Update();
	    }
	    adc_update();
    /* USER CODE END WHILE */

    /* USER CODE BEGIN 3 */
  }
  /* USER CODE END 3 */
}

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
/* USER CODE BEGIN 4 */
void HAL_UART_RxCpltCallback(UART_HandleTypeDef *huart)
{
  CLI_RxCallback(huart);
}
void HAL_GPIO_EXTI_Callback(uint16_t GPIO_Pin)
{
  //CLI_ButtonReiniciarCallback(GPIO_Pin);
}
/* USER CODE END 4 */
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


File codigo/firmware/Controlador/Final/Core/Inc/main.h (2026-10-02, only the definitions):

#define DATA2_Pin GPIO_PIN_13
#define DATA2_GPIO_Port GPIOC
#define medicion_corriente_de_carga_Pin GPIO_PIN_0
#define medicion_corriente_de_carga_GPIO_Port GPIOC
#define salida_adc_2_Pin GPIO_PIN_2
#define salida_adc_2_GPIO_Port GPIOC
#define banco2_med_Pin GPIO_PIN_3
#define banco2_med_GPIO_Port GPIOC
#define Salida_adc_1_Pin GPIO_PIN_0
#define Salida_adc_1_GPIO_Port GPIOA
#define banco1_med_Pin GPIO_PIN_1
#define banco1_med_GPIO_Port GPIOA
#define USART_TX_Pin GPIO_PIN_2
#define USART_TX_GPIO_Port GPIOA
#define USART_RX_Pin GPIO_PIN_3
#define USART_RX_GPIO_Port GPIOA
#define banco4_med_Pin GPIO_PIN_5
#define banco4_med_GPIO_Port GPIOA
#define medicion_corriente_descarga_Pin GPIO_PIN_6
#define medicion_corriente_descarga_GPIO_Port GPIOA
#define banco3_med_Pin GPIO_PIN_7
#define banco3_med_GPIO_Port GPIOA
#define salida_adc_3_Pin GPIO_PIN_4
#define salida_adc_3_GPIO_Port GPIOC
#define Salida_adc_4_Pin GPIO_PIN_5
#define Salida_adc_4_GPIO_Port GPIOC
#define S2_Pin GPIO_PIN_6
#define S2_GPIO_Port GPIOC
#define S1_Pin GPIO_PIN_8
#define S1_GPIO_Port GPIOC
#define S0_Pin GPIO_PIN_9
#define S0_GPIO_Port GPIOC
#define llave_de_emergencia_Pin GPIO_PIN_10
#define llave_de_emergencia_GPIO_Port GPIOA
#define DATA3_Pin GPIO_PIN_11
#define DATA3_GPIO_Port GPIOA
#define DATA4_Pin GPIO_PIN_12
#define DATA4_GPIO_Port GPIOA
#define TMS_Pin GPIO_PIN_13
#define TMS_GPIO_Port GPIOA
#define TCK_Pin GPIO_PIN_14
#define TCK_GPIO_Port GPIOA
#define CLK_Pin GPIO_PIN_10
#define CLK_GPIO_Port GPIOC
#define LATCH_Pin GPIO_PIN_11
#define LATCH_GPIO_Port GPIOC
#define DATA1_Pin GPIO_PIN_12
#define DATA1_GPIO_Port GPIOC

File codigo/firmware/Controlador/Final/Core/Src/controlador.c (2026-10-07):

/*
 * controlador.c
 *
 *  Created on: 10 jun 2026
 *      Author: ---
 */

#include "controlador.h"
#include "main.h"
#include "llave.h"
#include "procesar_adc.h"
#include "fallas.h"

static controlador_t ctrl;

extern volatile uint8_t flag_controlador_update;


static shift_register_t sr_bancos[CANT_BANCOS];
static mux_t mux_bancos;



static uint16_t periodo_ms = 0;
static uint16_t contador = 0;
static uint8_t fase = 0;


//por ahora solo tengo el banco 1
static GPIO_TypeDef *sr_data_puertos[CANT_BANCOS] = {
	DATA1_GPIO_Port,
	DATA2_GPIO_Port,
	DATA3_GPIO_Port,
	DATA4_GPIO_Port,
};

static uint16_t sr_data_pines[CANT_BANCOS] = {
	DATA1_Pin,
	DATA2_Pin,
	DATA3_Pin,
	DATA4_Pin,
};



static int verificar_banco(uint8_t banco);

static void Controlador_EnviarCeros(void){
    for (uint8_t b = 0; b < CANT_BANCOS; b++) {
        ctrl.bancos[b].prox = OFF;
        for (uint8_t c = 0; c < CELDAS_POR_BANCO; c++)
            ctrl.bancos[b].celdas[c].prox = OFF;
    }
    for (int8_t pin = CANT_PINES_SR - 1; pin >= 0; pin--) {
        for (uint8_t b = 0; b < CANT_BANCOS; b++)
            Banco_AplicarEstadoPin(&ctrl.bancos[b], pin);
        Banco_ClockPulse(&ctrl.bancos[0]);
    }
    Banco_LatchPulse(&ctrl.bancos[0]);
}


static int puede_operar(void){
    return ctrl.cant_bancos != 0 &&
           (ctrl.estado == ACTIVO || ctrl.estado == PRUEBA);
}


int Controlador_init(uint8_t bancos, uint8_t celdas){

	if (bancos == 0 || bancos > CANT_BANCOS ||
	    celdas == 0 || celdas > CELDAS_POR_BANCO) {
	    return 1;
	}
	if (ctrl.cant_bancos != 0 &&
	    (ctrl.estado == ACTIVO || ctrl.estado == PRUEBA)) {
	    Controlador_EnviarCeros();
	}
    Llave_Init();
    periodo_ms = contador = fase = 0;
    ctrl = (controlador_t){0};
	ctrl.cant_bancos = bancos;

	MUX_Init(&mux_bancos, S2_GPIO_Port, S2_Pin,
			         S1_GPIO_Port, S1_Pin, S0_GPIO_Port, S0_Pin);

	for (uint8_t i = 0; i < CANT_BANCOS; i++){
		ctrl.bancos[i].id=i;

		SR_Init(&sr_bancos[i],sr_data_puertos[i],
				sr_data_pines[i],CLK_GPIO_Port,
				CLK_Pin,LATCH_GPIO_Port, LATCH_Pin);



		Banco_Init(
		    &ctrl.bancos[i],
		    &sr_bancos[i],
		    &mux_bancos,
		    i < bancos ? celdas : 0,
		    ADC_MUX_BANCO_1 + i
		);

	}

    ctrl.estado = REPOSO;
    ctrl.rl = 0;
    ctrl.modo = MODO_SIN_ASIGNAR;
	return 0;
}


int Controlador_ActivarCircuito(controlador_modo_t modo){


    if (ctrl.cant_bancos == 0 || ctrl.estado != REPOSO) {
        return 1;
    }
    if (modo != MODO_CARGA && modo != MODO_DESCARGA) {
        return 1;
    }
    if (modo == MODO_DESCARGA && ctrl.rl == 0) {
        return 1;
    }
    ctrl.estado = ACTIVO;
    ctrl.modo = modo;
	Llave_Habilitar();
	HAL_Delay(TURN_ON_DELAY);
	Controlador_EnviarCeros();

	for (uint8_t b = 0; b < ctrl.cant_bancos; b++)
	    Banco_EncenderSwitch(&ctrl.bancos[b]);

	Controlador_AplicarEstados();

	return 0;
}


int Controlador_ModoPrueba(void){

	if (ctrl.cant_bancos == 0 || ctrl.estado != REPOSO) {
	        return 1;
	    }

	Llave_Habilitar();
		HAL_Delay(TURN_ON_DELAY);
		Controlador_EnviarCeros();

		for (uint8_t b = 0; b < ctrl.cant_bancos; b++)
		    Banco_EncenderSwitch(&ctrl.bancos[b]);

		Controlador_AplicarEstados();
		ctrl.estado = PRUEBA;
		ctrl.modo = MODO_SIN_ASIGNAR;
	return 0;
}



int Controlador_EvaluarFallas(void){
	if (ctrl.estado == FALLA) return 1;
	if (ctrl.estado != ACTIVO) return 0;
	if (!puede_operar()) return 1;
	if (!adc_is_dma_started() || !adc_has_measurements()) return 0; //TODO

    if (Fallas_EvaluarCorrientes(
        Controlador_GetCorrienteDescarga(),
        Controlador_GetCorrienteCarga()
    ) != FALLA_NINGUNA) return 1;


    for (uint8_t b = 0; b < ctrl.cant_bancos; b++) {
            if (ctrl.bancos[b].actual == ON ||
                !Banco_HayCeldasActualON(&ctrl.bancos[b])) continue;

            /* Aproximacion por tension del banco activo, no un diagnostico
             * de una celda individual. */
            if (Fallas_EvaluarTensionCelda(Controlador_GetTensionBanco(b))
                != FALLA_NINGUNA) return 1;
        }

    return 0;
}

void Controlador_Update(void){
	if (ctrl.estado == REPOSO || ctrl.estado == FALLA  ) return;


	if (Controlador_EvaluarFallas()) {
	    periodo_ms = contador = fase = 0;
	    Controlador_EnviarCeros();
	    Llave_DispararFalla();
	    ctrl.estado = FALLA;
	    return;
	}

    Controlador_Tick1ms();
    Controlador_ActualizarEstados();

}

status_contraldor_t Controlador_GetEstado(void){
	return ctrl.estado;
}
uint8_t Controlador_GetCantBancos(void){
	return ctrl.cant_bancos;
}


uint8_t Controlador_GetCantCeldas(void){
    return ctrl.cant_bancos ? ctrl.bancos[0].cant_celdas : 0;
}

int Controlador_SetResistenciaRL(uint16_t resistencia){
	if (ctrl.estado != REPOSO) return 1;
	if (ctrl.cant_bancos == 0) return 1;
	if (resistencia == 0 || resistencia > 1000) return 1;

	ctrl.rl = resistencia;
	return 0;
}


uint16_t Controlador_GetResistenciaRL(void){
    return ctrl.rl;
}

static void Controlador_ClockPulse(void){
	Banco_ClockPulse(&ctrl.bancos[0]);
}


static void Controlador_LatchPulse(void){
	Banco_LatchPulse(&ctrl.bancos[0]);
}



uint8_t Controlador_GetEstadoBanco(uint8_t banco){
    if (!verificar_banco(banco)) return OFF;

	return (uint8_t) Banco_GetEstado(&ctrl.bancos[banco]);
}

uint8_t Controlador_GetEstadoCelda(uint8_t banco, uint8_t celda){
    if (!verificar_banco(banco) || celda >= ctrl.bancos[banco].cant_celdas) return OFF;

	return (uint8_t) Banco_GetEstadoCelda(&ctrl.bancos[banco], celda);
}

void Controlador_AplicarEstados(void){
	//Envio 1 bit a la vez de todos los sr y luego clockeo
	if (!Controlador_HayCambios()) {
	        return;
	    }


	for (int8_t  pin = CANT_PINES_SR-1; pin >=0; pin--){
			for (uint8_t sr = 0; sr< CANT_BANCOS; sr++){
				Banco_AplicarEstadoPin(&ctrl.bancos[sr], pin);
			}
			Controlador_ClockPulse();

	}
	Controlador_LatchPulse();
}




int Controlador_HayCambios(void){
    for (uint8_t i = 0; i < CANT_BANCOS; i++) {
        if (Banco_HayCambios(&ctrl.bancos[i])) {
            return 1;
        }
    }

    return 0;
}


// Control individual




int Controlador_EncenderCelda(uint8_t banco, uint8_t celda)
{
    if (!puede_operar() || !verificar_banco(banco) || celda >= ctrl.bancos[banco].cant_celdas) return 1;


    // Paso 1: solo modifico el banco objetivo.
    // Los otros bancos quedan con su prox intacto.
    if (Banco_GetEstadoActual (&ctrl.bancos[banco]) == ON){
		Banco_ApagarSwitch(&ctrl.bancos[banco]); // sw banco apagado
		Controlador_AplicarEstados(); // escribe TODOS los bancos y hace latch comun



    }


    // Paso 2: prendo la celda.
    Banco_EncenderCelda(&ctrl.bancos[banco], celda);
    Controlador_AplicarEstados(); // otra vez frame completo + latch comun
    return 0;
}
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

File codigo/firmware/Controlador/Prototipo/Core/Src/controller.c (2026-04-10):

#include "controller.h"
#include "main.h"
#include <stdint.h>
#include <adc.h>




/* ======================= ESTADO CELDAS ======================= */



static sw_state_t cell_state[NUM_BANKS][CELLS_PER_BANK];

static cell_cfg_t cell_cfg[NUM_BANKS][CELLS_PER_BANK];


//asi o separadas las celdas de los bancos?


typedef enum
{
  CELL_11 = 0,
  CELL_12,
  CELL_21,
  CELL_22,
  CELL_31,
  CELL_32,
  BANK_1,
  BANK_2,
  BANK_3
} module_t;


typedef struct {
  uint8_t  enabled;
  uint16_t ticks;   // en ticks de 1 ms
  uint16_t counter;
  uint8_t  phase;               // si está en on u off
} square_group_t;

static square_group_t square_groups[MAX_SQUARE_GROUPS];

typedef struct {
  GPIO_TypeDef* port;
  uint16_t pin;
  uint8_t active_high;
  module_t id;
} pin_switch_t;


/* ======================= MAPEOS SWITCHES ======================= */

// Celdas
static pin_switch_t cell_sw[NUM_BANKS][CELLS_PER_BANK] = {
  // Banco 1
  {
    { Vc_11_GPIO_Port, Vc_11_Pin, 1, CELL_11},
    { Vc_12_GPIO_Port, Vc_12_Pin, 1, CELL_12 }
  },
  // Banco 2
  {
    { Vc_21_GPIO_Port, Vc_21_Pin, 1, CELL_21},
    { Vc_22_GPIO_Port, Vc_22_Pin, 1, CELL_22}
  },
  // Banco 3
  {
    { Vc_31_GPIO_Port, Vc_31_Pin, 1, CELL_31},
    { Vc_32_GPIO_Port, Vc_32_Pin, 1 , CELL_32}
  }
};

// Bancos
static pin_switch_t bank_sw[NUM_BANKS] = {
  { Vc_1_GPIO_Port, Vc_1_Pin, 1, BANK_1 },
  { Vc_2_GPIO_Port, Vc_2_Pin, 1, BANK_2 },
  { Vc_3_GPIO_Port, Vc_3_Pin, 1, BANK_3 }
};


/* ======================= NODOS DE MEDICION ======================= */


typedef struct {
  adc_node_t nodo;
  uint16_t v_mV;   // miliVolt
  module_t cell;
} cell_v_t;

typedef struct {
  adc_node_t bus_pos;
  adc_node_t bus_neg;
  uint16_t v_mV;   // miliVolt
  module_t bank;
} bank_v_t;


static bank_v_t bank_nodes[NUM_BANKS] = {
    {ADC_NODE_BUS_1 , ADC_NODE_OUT_NEG, 3300, BANK_1 },
    {ADC_NODE_BUS_2 , ADC_NODE_BUS_1, 3300, BANK_2 },
    {ADC_NODE_OUT_POS , ADC_NODE_BUS_2, 3300, BANK_3 }
};

#define TOTAL_CELLS (CELLS_PER_BANK*NUM_BANKS)

static cell_v_t cell_nodes[TOTAL_CELLS] = {
    {ADC_NODE_CELL_11,  3300, CELL_11 },
    {ADC_NODE_CELL_12,  3300, CELL_12 },
    {ADC_NODE_CELL_21,  3300, CELL_21 },
    {ADC_NODE_CELL_22,  3300, CELL_22 },
    {ADC_NODE_CELL_31,  3300, CELL_31 },
	{ADC_NODE_CELL_32,  3300, CELL_32 }
};

/*typedef struct {
  uint8_t  bank;   // 0..NUM_BANKS-1
  uint16_t v_mV;   // miliVolt
} bank_v_t;

static uint16_t bank_voltage[NUM_BANKS] = {0};*/


static bank_v_t bank_rank[NUM_BANKS];


/* ======================= VARIABLES DE TENSION ======================= */

static ctrl_mode_t g_ctrl_mode = CTRL_MODE_MANUAL;
static uint16_t g_vtarget_mV = 3300;     // mV tension elegida


#define UMBRAL_mV 10  // 10mV

/* ======================= GPIO WRITE ======================= */

static void gpio_write(const pin_switch_t* g, uint8_t on)
{
  GPIO_PinState ps;

  if (g->active_high)
    ps = on ? GPIO_PIN_SET : GPIO_PIN_RESET;
  else
    ps = on ? GPIO_PIN_RESET : GPIO_PIN_SET;

  HAL_GPIO_WritePin(g->port, g->pin, ps);
}

/* ======================= LOGICA BANCO ======================= */

static void Controller_UpdateBank(uint8_t bank)
{
  // Switch del banco ON solo si AMBAS celdas están OFF
  uint8_t both_off =
    (cell_state[bank][0] == SW_OFF) &&
    (cell_state[bank][1] == SW_OFF);

  gpio_write(&bank_sw[bank], both_off);
}

/* ======================= INIT ======================= */

void Controller_Init(void)
{
  for (uint8_t b = 0; b < NUM_BANKS; b++) {
    for (uint8_t c = 0; c < CELLS_PER_BANK; c++) {
      cell_state[b][c] = SW_OFF;

      cell_cfg[b][c].modo = CELL_MODE_STATIC;
      cell_cfg[b][c].id_grupo = 0;
      cell_cfg[b][c].fase = CELL_PHASE_POS;

      gpio_write(&cell_sw[b][c], 0);
    }

    Controller_UpdateBank(b);
  }

  for (uint8_t g = 0; g < MAX_SQUARE_GROUPS; g++) {
    square_groups[g].enabled = 0;
    square_groups[g].ticks = 0;
    square_groups[g].counter = 0;
    square_groups[g].phase = 0;
  }

  for (uint8_t i = 0; i < NUM_BANKS; i++) {
    bank_rank[i].bank = bank_nodes[i].bank; // quedaria BANK_1 (6), BANK_2 (7), BANK_3 (8)
    bank_rank[i].v_mV = bank_nodes[i].v_mV;
  }
}

void Controller_SquareTask(void);
void Controller_mediciones(void);
uint8_t Controller_GetBanksNeeded(uint16_t *achieved_mV);

void Controller_Update(void){

	Controller_mediciones();
	/*uint16_t tension_lograda = 0;
	if (Controller_GetMode() == CTRL_MODE_AUTO){
		uint8_t cant_bancos = Controller_GetBanksNeeded(&tension_lograda);

		for (uint8_t i = 0; i< cant_bancos; i++){
			for (uint8_t j = 0; j < CELLS_PER_BANK; j++){
			Controller_SetCell(i,j,CELL_ON);}
		}
		for (uint8_t i = cant_bancos; i < NUM_BANKS;i ++ ){
			for (uint8_t j = 0; j < CELLS_PER_BANK; j++){
				Controller_SetCell(i,j,CELL_OFF);
			}
		}
	}

		*/

}


static uint8_t Controller_MapToModule(uint8_t bank_user,
                                      int8_t cell_user,
                                      module_t *mod)
{
    if (mod == NULL) {
        return 0;
    }

    if (bank_user < 1 || bank_user > NUM_BANKS) {
        return 0;
    }

    // Pedido de banco: (bank, 0)
    if (cell_user == 0) {
        *mod = (module_t)(BANK_1 + (bank_user - 1));
        return 1;
    }

    // Pedido de celda: (bank, cell)
    if (cell_user < 1 || cell_user > CELLS_PER_BANK) {
        return 0;
    }

    *mod = cell_sw[bank_user - 1][cell_user - 1].id;
    return 1;
}


/* ======================= CELDAS ======================= */

static void _controller_SetCell_ON(uint8_t bank, uint8_t cell)
{
  cell_state[bank][cell] = SW_ON;
  Controller_UpdateBank(bank);

  gpio_write(&cell_sw[bank][cell], 1);

}

static void _controller_SetCell_OFF(uint8_t bank, uint8_t cell)
{
  cell_state[bank][cell] = SW_OFF;
  gpio_write(&cell_sw[bank][cell], 0);

  Controller_UpdateBank(bank);

}




static void Controller_SetCell_ON_(uint8_t bank, uint8_t cell)
{
  cell_cfg[bank][cell].modo = CELL_MODE_STATIC;
  _controller_SetCell_ON(bank,cell);
}

static void Controller_SetCell_OFF_(uint8_t bank, uint8_t cell)
{
  cell_cfg[bank][cell].modo = CELL_MODE_STATIC;
  _controller_SetCell_OFF(bank,cell);
}

void Controller_SetCell(uint8_t bank, uint8_t cell, sw_state_t st)
{
  if (bank >= NUM_BANKS || cell >= CELLS_PER_BANK) return;

  if (st == SW_ON)
	  Controller_SetCell_ON_(bank, cell);
  else
	  Controller_SetCell_OFF_(bank, cell);
}



sw_state_t Controller_GetCell(uint8_t bank, uint8_t cell)
{
  if (bank >= NUM_BANKS || cell >= CELLS_PER_BANK) return SW_OFF;
  return cell_state[bank][cell];
}

uint8_t Controller_GetBankSwitch(uint8_t bank)
{
  if (bank >= NUM_BANKS) return 0;

  return (cell_state[bank][0] == SW_OFF) &&
         (cell_state[bank][1] == SW_OFF);
}


void apagar_celdas(void){
	for (uint8_t i = 0;i<NUM_BANKS;i++){
		for(uint8_t j = 0;j<CELLS_PER_BANK;j++)
		Controller_SetCell(i, j, SW_OFF);
	}
}
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

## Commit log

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2025-11-13 propuesta de disposición de los elementos del pcb
    subo antes de empezar a hacer el ruteo
    [celda.kicad_sch, esquematico_basico.kicad_sch, freerouting.dsn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]
2025-11-13 propuesta de ruteo de celdas
    solo el ruteo de las celdas, falta el general
    [prototipo.kicad_pcb]
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2025-11-21 termino de reacomodar las celdas con la disposición nueva, faltan las conexiones de la entrada.
    [bornerav2.step, celda.kicad_sch, prototipo.kicad_pcb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]
2025-11-25 Propuesta de conexión de las entradas
    no me gusta la opción, pero esta conectado
    [celda.kicad_sch, prototipo.kicad_pcb, prototipo.kicad_sch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]
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2025-11-28 crea el workspace para el controlador
    tambien guarda el pcb antes de unificar los agujeros
    [prototipo.kicad_pcb]
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2025-12-03 acomodo devuelta el inversor, y agrego conectores para medir con el micro
    [prototipo.kicad_pcb, prototipo.kicad_sch]
2025-12-10 Sumo ultimos cambios hablados en reunion
    agrega agujeros para tornillos, jumper para banco 1, INVERSOR CON ZOCALO, cambia el diametro de test points y vias, acomoda serigrafia, SIN WARNINGS
    [prototipo.kicad_pcb, prototipo.kicad_sch, switch_banco.kicad_sch]
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2025-12-19 Inicia el controlador
    hay que tener un par de apps descargadas de stm
    [pines.xlsx, prototipo.kicad_sch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]
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2025-12-19 actualiza el codigo, agrega los comandos status y help, comunicación verificada con putty
    falta verificar si funciona electricamente
    [prototipo.xlsx]
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2026-01-02 agrega funciones en controller, y cli
    aun falta desarrollar mediciones y la logica del controlador. Ya estan la gran mayorias de las funciones preparadas en controlador solo queda unirlas
    [pines.xlsx]
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2026-02-06 arregla los titulos de las N curvas
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2026-04-15 Se duplican dos de las 3 tiras de pines del circuito de celda topología torre
    [Switch celda.kicad_pcb, Switch celda.kicad_sch]
2026-04-18 Cambios al circuito de la celda en modo torre: clearance de 0.5mm (en lugar de la mínima), buses de potencia de 1.5mm (en lugar de 1mm) y resistores SMD de tamaño 1206 (en lugar de 0603)
    [Switch celda.kicad_pcb, Switch celda.kicad_sch]
2026-04-19 Update menor de orden de señales en la entrada (VCC por bus_pos)
    [Switch celda.kicad_pcb, Switch celda.kicad_sch]
2026-04-20 Update switch celda: ahora tiene pines para conectarse con 7 celdas en lugar de 6
    [Switch celda.kicad_pcb, Switch celda.kicad_sch]
2026-04-20 Subida de datasheets y corrección de uno de los pines de entradas
    [Switch celda.kicad_pcb, Switch celda.kicad_sch]
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2026-04-23 Eliminación del pin de señal de control para todo el banco y correcciones menores a la placa
    [Switch celda.kicad_pcb, Switch celda.kicad_sch]
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2026-04-24 Reemplazo de la vía por un resistor SMD de 0 ohm y corrección de los errores de DRC
    [Switch celda.kicad_pcb, Switch celda.kicad_sch]
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2026-05-01 PCB celda con los orificios para las varillas colocados y reduciendo la cantidad de pines hembra macho a la mitad
    [Switch celda.kicad_pcb, Switch celda.kicad_sch]
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2026-05-04 subida del pdf listo para imprimir para el PCB de las celdas
    [Switch celda.kicad_pcb]
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2026-05-06 Nuevo pdf para la impresion de la version 2 del switch del banco
    [Switch banco - Torre.kicad_pcb]
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2026-05-08 subida de simulaciones de la plaquita de prueba del PMOS y corrección de las lagrimas en el PCB de las celdas
    [Switch celda.kicad_pcb]
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2026-05-11 update de valores del codigo y subida de archivos historicos de los PCBs
    [Switch banco - Torre.kicad_pcb, Switch celda.kicad_pcb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]
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2026-05-18 comienza arreglo de huellas
    [Switch banco - Torre.kicad_pcb, Switch banco - Torre.kicad_sch]
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2026-05-22 Subida del PCB del adaptor SMD - THT para la prueba de los integrados del banco
    [Adaptador SMD - THT.kicad_pcb, Adaptador SMD - THT.kicad_sch, adaptador mux.kicad_pcb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]
2026-05-26 Subida de caricatura de pilas y boceto de kicad del circuito externo
    [Circuito Final - Circuito externo.kicad_pcb, Circuito Final - Circuito externo.kicad_sch]
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2026-05-28 Subida del circuito con el dibujo de la pilita en el cobre
    [Circuito Final - Circuito externo.kicad_pcb]
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2026-06-16 arreglos de logica de continuidad de la matriz en el controlador
    [controlador.c]
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2026-06-17 update de bitacora, valores de resistores del divisor en spice e implementacion en el kicad del circuito externo
    [Circuito Final - Circuito externo.kicad_sch]
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2026-06-22 subida de la bitacora, del spice del sumador no inversor y update del kicad del circuito central
    [Circuito Final - Circuito externo.kicad_sch]
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2026-06-24 subida version 2.2 del pcb de las celdas, junto con el modelo spice del TL084 y su datasheet
    [Switch celda.kicad_pcb, Switch celda.kicad_sch]
2026-06-24 subida del spice con el funcionamiento correcto del opamp TL084 y subida del modelo spice del LM2902 (opcion B)
2026-06-24 update del pcb del circuito central y subida de bitacora del 24 de junio
    [Circuito Final - Circuito externo.kicad_pcb, Circuito Final - Circuito externo.kicad_sch]
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2026-07-14 Subida de modelos 3D de los pines hembra largos, update de los modelos 3D de las celdas y subida provisoria de la bitácora
    [Pin hembra largo 1x4.STEP, Pin hembra largo 1x6.STEP, Pin hembra largo 1x7.STEP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]
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2026-07-17 subida de bitácora del 17 de julio, subida del kicad de circuito central de pruebas
    [Circuito Final - Circuito externo.kicad_pcb, Circuito Final - Circuito externo.kicad_sch]
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2026-07-23 subida de mediciones de switcheo con dos bancos, bitacora y kicad del circuito externo de prueba terminado
    [Circuito Final - Circuito externo.kicad_pcb, Circuito Final - Circuito externo.kicad_sch]
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2026-08-17 update de la placa central (cambio de pista de los pmos y agrandado de pilita)
    [Circuito Final - Circuito externo.kicad_pcb]
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2026-08-23 sube arreglos de la placa central
    queda confirmar el switch de emergencia
    [Circuito Final - Circuito externo.kicad_pcb, Circuito Final - Circuito externo.kicad_sch]
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2026-08-26 arregla conexion del shunt
    [Circuito Final - Circuito externo.kicad_pcb]
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2026-09-23 sube placa con los oines arreglados
    estaba mal data 2, data 1, y vcc
    [Circuito Final - Circuito externo.kicad_pcb, Circuito Final - Circuito externo.kicad_sch]
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2026-10-06 update cajita con los orificios de los conectores en el orden correcto
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2026-10-25 subida de la cajita con la ranura para los portaceldas individuales del ancho correcto
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

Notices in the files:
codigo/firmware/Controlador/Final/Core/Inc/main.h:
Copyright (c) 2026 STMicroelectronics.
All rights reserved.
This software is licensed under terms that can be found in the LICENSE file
